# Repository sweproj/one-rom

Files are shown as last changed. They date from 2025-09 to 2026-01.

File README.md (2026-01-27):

# One ROM

**[One ROM](https://onerom.org) - One ROM To Rule Them All**

The most flexible ROM replacement for your retro computer.  It is highly configurable and low-cost.  Get them fabbed at JLC for under $5 each in a quantity of 10 or more.

Based on a Raspberry Pi RP2350 (One ROM Fire 🔥) or STM32F4 (One ROM Ice ❄️).

One ROM is available as 24 pin and 28 pin versions, emulating nearly all systems' 24 and 28 pin ROMs, including any possible chip select configurations with a single hardware variants, and can serve different images to multiple ROM sockets simultaneously.

Replaces failed ROMs in Commodore 64s, VIC-20s, PETs, Ataris, BBC, TIs, disk drives and many other types of systems, like pinball machines and music synthesizers.

ROM types replaced:
- 24 pin: 2704, 2708, 2716, 2732, 2316, 2332, 2364
- 28 pin: 2764, 27128, 27256, 27512, 23128, 23256, 23512

As of the latest firmware, One ROM also supports RAM chips of the correct footprint, including the 6116 and 2016 2K SRAM chips.

One ROM was formerly known as Software Defined Retro ROM (SDRR).

## Quick Start

See https://onerom.org/start/

## Key Features

💰 Based on sub-$2 microcontrollers.  **[Choose from Raspberry Pi (Fire 🔥) or STM (Ice ❄️) flavours](docs/MCU-SELECTION.md)**.

⚡ **[Fast](docs/STM32-SELECTION.md)** enough for PETs, VIC-20s, C64s, 1541s, IEEE drives, etc. Support faster systems with higher end microcontroller.

📐 **[Same footprint](docs/images/sdrr-24-pin-side.png)** as original ROMs - doesn't overhang the socket like other solutions.

🔌 **[USB Version](https://onerom.org/prog/)** - no programmer required, program from your browser.

🚀 **[Quick programming](docs/PROGRAMMING.md)** - build and flash in <10 seconds.

🛠️ **[Reflash in situ](docs/PROGRAMMING.md)** - no need to remove the ROM from the host when reprogramming.

⚙️ **[Software configurable](docs/CONFIGURATION.md)** chip select lines - no hardware jumpers required.

💾 Stores up to **[16 ROM images](docs/STM32-SELECTION.md)** of different sizes and chip select configurations.  Image selectable via jumpers.

📦 **[Replace multiple ROMs with one ROM](docs/MULTI-ROM-SETS.md)** a single One ROM can replace up to 3 original ROMs e.g. all of C64 kernel, BASIC, character set.

🔀 **[Dynamic bank switching](docs/MULTI-ROM-SETS.md)** - switch between ROM images on the fly, e.g. different char ROMs.

💻 **[Hackable at runtime](docs/RUNTIME-ACCESS.md)** - change the ROM images being served and access telemetry from the ROM at runtime using **[Airfrog](https://piers.rocks/u/airfrog)** or other SWD probes.

🧩 **[Images combined automatically](docs/CONFIGURATION.md)** - no need to manually build up your own larger PROM image containing multiple retro ROMs.

🏭 **[Two layer PCB](sdrr-pcb/README.md)**, component on single-side, limited BOM for low manufacturing cost/complexity.

🎯 Supports multiple **[STM32F4xxR](docs/STM32-SELECTION.md)** variants: F401, F411, F405, F446 (others can be added).

🔓 **[Open source](LICENSE.md)** software and hardware.

## Introduction

The video below provides an introduction to One ROM:

Video Title (https://youtu.be/Jhe4LF5LrZ8)

## Hardware

This is the Fire 24-pin version, hardware revison A.  See [sdrr-pcb](sdrr-pcb/README.md) for the hardware designs and documentation.

<div style="display: flex; justify-content: center; gap: 20px;">
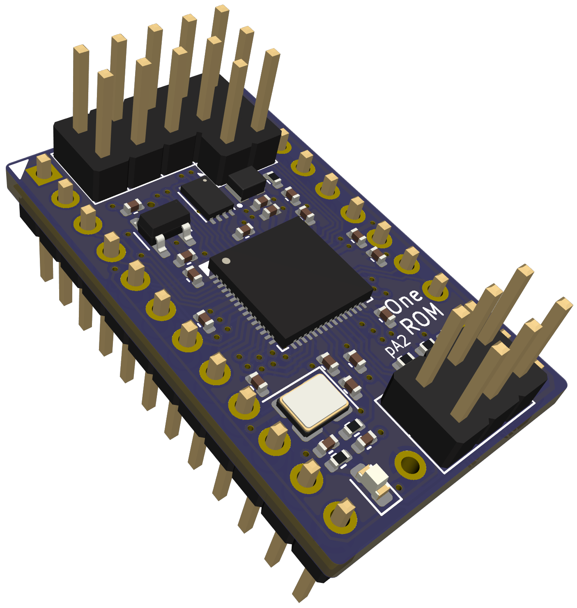
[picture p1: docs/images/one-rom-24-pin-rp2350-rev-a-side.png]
One ROM RP2350 24 pin rev A side on
  
</div>

## Documentation

| Topic | Description |
|---|---|
| [Getting Started](docs/GETTING-STARTED.md) | Detailed instructions for flashing your One ROM |
| [Frequently Asked Questions](docs/FAQ.md) | Answers to common questions about One ROM. |
| [Installation](INSTALL.md) | Installation of dependencies. |
| [Programming](docs/PROGRAMMING.md) | How to program One ROM. |
| [Available Configurations](config/README.md#available-configurations) | Various pre-collated ROM collection configurations. |
| [MCU Selection](docs/MCU-SELECTION.md) | How to select the appropriate MCU for your application. |
| [Image Selection](docs/IMAGE-SELECTION.md) | How to tell One ROM which of the installed ROM images to serve. |
| [Image Sets](docs/MULTI-ROM-SETS.md) | How to use a single One ROM to support multiple ROMs simultaneously or to dynamically switch between images. |
| [Configuration](docs/CONFIGURATION.md) | One ROM configuration options. |
| [Runtime Access/Control](docs/RUNTIME-ACCESS.md) | Access and control the One ROM while it is serving ROMs. |
| [Compatibility](docs/COMPATIBILITY.md) | Compatibility with various retro systems. |
| [Logging](docs/LOGGING.md) | How to enable and use One ROM logging. |
| [Technical Summary](docs/TECHNICAL-SUMMARY.md) | Overview of the One ROM architecture, operation and design decisions. |
| [Technical Details](docs/TECHNICAL-DETAILS.md) | Technical details of the One ROM firmware and hardware. |
| [ROMs Glorious ROMs](docs/ROMS-GLORIOUS-ROMS.md) | Everything you ever wanted to know about 23/27 series ROMs but were afraid to ask. |
| [Custom Hardware](docs/CUSTOM-HARDWARE.md) | Guide on designing custom hardware for One ROM. |
| [Build System](docs/BUILD-SYSTEM.md) | How the One ROM build system works. |
| [Voltage Levels](docs/VOLTAGE-LEVELS.md) | How the One ROM supports the required logic voltage levels. |
| [Pi Pico Programmer](docs/PI-PICO-PROGRAMMER.md) | How to use a $5 Raspberry Pi Pico as a programmer for One ROM. |
| [Manufacturing Test](docs/MANUFACTURING-TEST.md) | Information on testing One ROM during manufacturing. |
| [STM32 Clones](docs/STM32-CLONES.md) | Information using STM32 clones with One ROM. |
| [Future Enhancements](docs/FUTURE-ENHANCEMENTS.md) | Possible future enhancements under consideration. |
| [License](LICENSE.md) | One ROM software and hardware licenses. |

## Debugging

The best place to start with debugging is [`Logging`](docs/LOGGING.md).  This will help you see what the One ROM is doing, and why it may not be working as expected.

If you have an [Airfrog](https://piers.rocks/u/airfrog), you can use it to inspect the One ROM firmware and its current state.

If you'd like a hand, raise an issue on the [GitHub issues page](https://github.com/piersfinlayson/software-defined-retro-rom/issues).  Please provide:

- the MCU you are using and the PCB type/revision
- the retro system you are trying to One ROM with
- any logging from One ROM
- ideally, the firmware image, if you are happy to share.

If you have built the firmware yourself, rather than using a pre-built release image, also provide:

- your build configuration
- the output from `make info-detail`.

## License

See [LICENSE](LICENSE.md) for software and hardware licensing information.

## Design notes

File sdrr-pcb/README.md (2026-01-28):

# sdrr-pcb

Contains SDRR PCB design files.  These are organised into two directories:

- [`verified/`](verified/README.md) - Verified designs that have been tested and work.
- [`unverified/`](unverified/README.md) - Unverified designs that have not been tested.

## Recommended Revisions

Last Updated 28th January 2026.

I recommend Fire over Ice boards for most users.  See [MCU-SELECTION.md](../docs/MCU-SELECTION.md) for a comparison between Fire and Ice capabilities.

### Fire (RP2350)

The current recommended 24 pin hardware revision is [fire-24-d](./verified/fire-24-d/README.md).  This is a combined Pro (SWD) and micro USB version, with 4 image select jumpers (v0.6.1 onwards).  It supports PIO and CPU serving algorithms.  This is recommended over revisions A (Pro only) and B (USB only).

The current recommended 28 pin hardware revision is [fire-28-a3](./verified/fire-28-a3/README.md).  This is a combined Pro (SWD) and USB-C version, with 2 image select pins.  (The 28 pin version does not have X pins.)  It supports PIO and CPU serving algorithms.  The incorrect SWD CLK/DIO silkscreen in A2 has been corrected in this revision.

### Ice (STM32F4)

The current recommended 24 pin hardware revision is [ice-24-j](./verified/ice-24-j/README.md).  This is a combined Pro (SWD) and USB version, with 4 image select pins (v0.6.1 onwards) and 2 X (special function) pins.  It supports both SWD programming and USB programming.

There is no recommended 28 pin Ice version.  (Revision A does exist, but is not recommended and support may have been removed from the latest firware revisions.)

## Notes on Fabrication

All recommended designs have been manufactured and assembled using JLCPCB's PCB assembly service.  The gerbers and BOM files in each revision's `fab/` directory are compatible with JLCPCB's requirements.  However, you need to exercise care when submitting the order to ensure the correct options are selected.  In particular:

- Select economic assembly, not standard assembly, for cost reasons.
- Use standard 1.6mm PCB thickness.  You probably want HASL with lead finish for cost reasons.
- You have to select the desired PCB colour as part of the PCB ordering process.  Red is recommended for Fire and blue for Ice.
- As of late 2025 you no longer need to remove JLC's order ID from the PCBs, but it is worth checking this is still the case when you place your order.
- After uploading the BOM and position files for assembly, you need to ensure all parts are available and checked.
- You must ensure JLC is showing the correct orientation for all components.  There are silkscreen markings for pin 1 on all ICs and polarized components - ensure this matches the pink dot of the component in the viewer.  Also ensure the USB connector is the correct orientation.

Occasionally, some chosen parts are out of stock on JLCPCB.  One ROM has been designed with extremely common parts where possible, which JLC tend to hold large stocks of.  However, if a part is unavailable you may need to select an alternative part.  Ensure the alternative part has the same footprint and electrical characteristics (e.g. capacitance, voltage rating, etc) as the original part.  If in doubt, query within github discussions for advice. 

JLC may raise an issue with you after submitting your order.  Common issues include:
- JLC may ask to add side rails with stamp holes, to help with the PCB assembly process.  While One ROM has been successfully fabbed without these, if JLC recommends them it is best to accept this change, as otherwise they may not warrant the assembled boards.  The side rails can be snapped off using the "mouse bites" (stamp holes) after assembly.  JLC may or may not accept replacing stamp holes with v-score - as v-score is not available on their economic service.

If in doubt, query within github discussions for advice.

Assembly errors:
- Ice boards have rarely, if ever, experienced assembly errors.
- The first few batches of Fire boards experienced some assembly issues, particularly with respect to the RP2350 MCU solder pad fillets.  More recent boards and orders have been without issue.  It is unclear whether differences in the later PCBs or improvements in JLC's assembly process are responsible for this improvement.  If you do experience assembly issues, raise with JLC support.  It would also be interesting to hear on github discussions what issues you experienced, so others can be aware.

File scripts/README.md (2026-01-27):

# Scripts

Helper scripts for testing and debugging.

## onerom.sh

Builds a blank firmware image, adds the chip metadata, adds the ROM/RAM images, and optionally flashes the firmware to a connected OneROM device.

Example, to build a C64 set of ROMs for Fire 24 D:

```bash
scripts/onerom.sh fire-24-d onerom-config/c64.json
```

Example, to build a C64 set of ROMs for Ice 24 J, MCU STM32F411RE, with logging and debug logging, and flash it:

```bash
scripts/onerom.sh -d -l -f ice-24-j f411re onerom-config/c64.json
```

## build-empty-fw.sh

Creates a blank firmware image for the OneROM device, with no metadata and no ROM (or other chip) images or types.

Example:

```bash
scripts/build-empty-fw.sh -d -l sdrr/build/sdrr-rp2350.bin /tmp/
```

## add.sh

Tkes a blank firmware image, adds the chip metadata to it.

Example:

```bash
scripts/add.sh sdrr/build/sdrr-rp2350.bin /tmp/onerom-fw rom-config/c64.json
```

Creates:

- `/tmp/onerom-fw.bin` - the firmware image with the ROM metadata added
- `/tmp/onerom-fw.elf` - the ELF file with symbols for debugging

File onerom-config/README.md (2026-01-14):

# ROM Configs

This directory contains configuration files that can be used to generate various ROM collections for use with One ROM.

There is a [schema file](schema.json) that describes the structure of these configuration files. You can use this schema to validate your own configuration files or to generate new ones.

If you would like a more human readable version of the schema use a tool like [json-schema.app](https://json-schema.app/view/%23?url=https%3A%2F%2Fimages.onerom.org%2Fconfigs%2Fschema.json), pasting in https://images.onerom.org/configs/schema.json as the URL.

To be precise, these config files are used to generate the __metadata__ that is embedded on One ROM's flash __alongside__ the core firmware, adding:

- ROM images
- (optionally) overrides to stock firmware behaviour, on a per ROM basis.

A config file following this format can be used with [One ROM Studio](https://onerom.org/studio) to generate a complete One ROM image and flash it to your One ROM.

## Minimal Config

This is a minimal config:

```json
{
    "$schema": "https://images.onerom.org/configs/schema.json",
    "version": 1,
    "description": "A minimal ROM config",
    "rom_sets": []
}
```

This produces One ROM image with no ROMs in it. This may be useful for manufacturing purposes - in order to flash and ship One ROM with no ROMs installed.

This is essentially the configuration that is used to generate the base One ROM images that One ROM Studio then adds the ROMs you select to.

## Simple Config

A slightly more advanced config with 2 ROM images:

```json
{
    "$schema": "https://images.onerom.org/configs/schema.json",
    "version": 1,
    "name": "Simple Config",
    "description": "A simple ROM config with 2 ROMs",
    "rom_sets": [
        {
            "type": "single",
            "roms": [
                {
                    "description": "ROM 1",
                    "file": "http://example.com/rom1.bin",
                    "type": "2364",
                    "cs1": "active_low"
                }
            ]
        },
        {
            "type": "single",
            "roms": [
                {
                    "description": "ROM 2",
                    "file": "http://example.com/rom2.bin",
                    "type": "2364",
                    "cs1": "active_low"
                }
            ]
        }
    ]
}
```

As can be seen, this config contains 2 ROM sets, each with a single 2364 mask programmed ROM image, each with the CS line active low.

One ROM Studio reads this config, downloads the 2 ROM images from the specified URLs, and builds a One ROM image containing these 2 ROMs.

The two ROM images are selected, at One ROM boot (power on) time, via the on-board image select jumpers.  The first ROM set is selected when all the jumpers are open.  The second ROM set is selected when the first jumper is closed.

(If you close more jumpers than there are ROM sets, the firmware will select the image indicates by the binary value encoded by the jumpers, modulo the number of installed images.)

## 23 vs 27 Series ROMs

If specifying a 27 series (EP)ROM, instead of a 23 (mask programmed) ROM, the `type` field should be set to the appropriate 27 series type (e.g. "27256" instead of "2364").

In this case, there is no need to specify CS line behaviour, as 27 series ROMs use /CE and /OE (both active low) logic by default.

For more details on the differences between 23 and 27 series ROMs, see the [One ROM Visualizer](https://onerom.org/visualizer).

## Firmware Configuration

The `firmware_overrides` section __within a ROM set__ allows fine-tuning of One ROM hardware behavior for __that specific ROM/set of ROMs__. Each base firmware image has built-in defaults - these overrides change the behavior when serving a particular ROM set.

Any ROM set can have its own `firmware_overrides` section, allowing different ROM sets to have different hardware configurations.  It can also have no `firmware_overrides` section, in which case the default firmware behavior is used.

The `firmware_overrides` fields are optional - only include the fields you wish to override from the defaults.

### Primary Use Cases

1. __Performance requirements__ - Some ROM images (particularly character ROMs) require specific clock speeds or voltage settings to serve reliably in certain host systems
2. __Hardware experimentation__ - Testing different configurations to determine optimal settings for specific host platforms and ROM types
3. __Power/performance/preference__ - Disabling features like LEDs (power saving or user preference) or debug interfaces (performance)

### Ice/Fire Specific Configuration

#### Ice Boards (STM32F4-based)

```json
"firmware_overrides": {
    "ice": {
        "cpu_freq": "72MHz",
        "overclock": false
    }
}
```

Ice boards support frequencies from 1MHz to 450MHz.

Set `overclock: true` for frequencies above the rated maximum for a specific STM32F4 MCU.

#### Fire Boards (RP2350-based)

```json
"firmware_overrides": {
    "fire": {
        "cpu_freq": "300MHz",
        "overclock": true,
        "vreg": "1.20V",
        "serve_mode": "Pio"
    }
}
```

Fire boards support 16MHz to 800MHz in various increments (as defined in the schema). For higher frequencies than 150MHz:

- set `overclock: true`.
- you may need to tune `vreg` (internal voltage regulator) - different RP2350 silicon may need different core voltages for stability at high speeds. One ROM firmware will use its own (conservative) voltage regulator settings for higher clock speeds if this is not specified.

### Other Hardware Settings

```json
"firmware_overrides": {
    "led": {
        "enabled": false
    },
    "swd": {
        "swd_enabled": false
    }
}
```

- __LED__ - Disable to save power or if you don't want a status LED on your ROM.  Note, if present and the device enters "limp mode" (e.g. due to a fault or unrecoverable configuration error), the LED will still blink to indicate an error.
- __SWD__ - Disable the debug interface to reduce bus contention and improve serving performance.  Not yet supported, may be removed in a future release.

### Example: ROM-Specific Configuration

```json
{
    "rom_sets": [
        {
            "description": "C64 Character ROM - requires high clock speed",
            "firmware_overrides": {
                "ice": {
                    "cpu_freq": "150MHz",
                    "overclock": true
                }
            },
            "roms": [
                {
                    "description": "C64 Character ROM",
                    "file": "http://example.com/c64-char.bin",
                    "type": "2332",
                    "cs1": "active_low",
                    "cs2": "active_high"
                }
            ]
        }
    ]
}
```

### Advanced: PIO Serving Algorithm Parameters

For Fire boards using the PIO serving algorithm, low-level timing can be tuned via `serve_alg_params`. This is primarily for experimentation to determine what settings are required for specific ROM/host combinations.

```json
"firmware_overrides": {
    "serve_alg_params": {
        "params": [254, 0, 2, 0, 0, 0, 254, 255]
    }
}
```

As of firmware 0.6.0, the parameter array format is 8 bytes long, as follows:

- Byte 0: `0xFE` (signature)
- Byte 1: `addr_read_irq` (0=disabled, 1=enabled) - whether to use IRQ to trigger address reads
- Byte 2: `addr_read_delay` (0-31) - PIO cycles to delay between address reads
- Byte 3: `cs_active_delay` (0-31) - PIO cycles to wait after CS active before setting data pins to outputs
- Byte 4: `cs_inactive_delay` (0-31) - PIO cycles to hold data as outputs after CS goes inactive
- Byte 5: `no_dma` (0=use DMA, 1=CPU) - whether to use DMA or CPU for byte serving
- Byte 6: `0xFE` (end signature)
- Byte 7: `0xFF` (padding)

These parameters adjust the PIO state machine timing for specific ROM types or host systems. At 150MHz, each PIO cycle is ~6.67ns. See the PIO implementation source code for detailed timing analysis and pre-defined configurations.

It is likely that in future firmware versions, more PIO settings will be exposed via the config file.

### Firmware Defaults

As of 0.6.0 the following firmware defaults are used if no overrides are specified:

- Ice Clock: F401=84MHz, F411=100MHz, F405=168MHz, F446=180MHz, no overclocking.
- Fire Clock: 150MHz, overclocking enabled, VREG 1.10V.
- LED: Enabled (if hardware support is present)
- SWD: Enabled (if hardware support is present)
- PIO Serve Algorithm Params: [254, 0, 2, 0, 0, 0, 254, 255]

### Error Handling

Where possible, One ROM attempts to gracefully recover from incorrect or invalid configuration settings. 

For example, if it cannot calculate PLL values for a specific requested clock speed, it will attempt to find a close match, and if not found fall back to the values built into the firmware (likely to be the stock maximum rated speed for the MCU).

However, there are some situations where recover is not possible, or it is deemed better to enter "limp mode" (where the device hangs and flashes its status LED, irrespective of the LED enabled setting) to indicate a fault.

If the device enters limp mode, you have two choices:
- Try changing the settings and reflashing.
- Connecting a debug probe and using a build with BOOT_LOGGING/DEBUG_LOGGING included, to diagnose the issue.

The stock builds provided as part of One ROM releases _do not_ include debug or boot logging for performance reasons.

## Complex Configs

There's some advanced ROM options including the following:

- ROM Set types "multi" and "banked" for multi-ROM sets and dynamically bank switched ROM sets
- Local file and URL file sources (most generators only support URLs)
- The ability to specify licenses which must be accepted before building a config
- The ability to configure chip selects in multiple directions
- Support for all 24 and 28 pin ROM types
- Optional categories for better organization
- Support for archived ROM files (zips)
- Retrieve sections of a larger ROM file
- Duplicate and pad ROM images, if the ROM file provided is smaller than the expected size, and truncate if larger

Use the configs in this directory and the schema to build your own complex configs.

## Future Plans

The "end-game" is to have a repository of officially supported ROM configs for popular systems that can be used with One ROM Studio to build custom One ROM images.

It is intended that eventually ROM configs will specify the original ROM chip's access times and other characteristics, with the One ROM firmware to dynamically adjust its serving behavior to match the original hardware as closely as possible.

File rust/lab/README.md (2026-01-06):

# One ROM Lab

One ROM Lab firmware reads ROM images from external ROM chips (originals, One ROMs, and other replacements), by using the One ROM hardware with female socket placed on top of the ROM socket pins.  It can also be used to instrument the performance of these external ROM chips, by using additional equipment, such as logic analyzers or oscilloscopes.

<div class="video-container">
    <iframe 
        width="560" 
        height="315" 
        src="https://www.youtube.com/embed/9QBlPToP_BQ" 
        frameborder="0" 
        allow="accelerometer; autoplay; encrypted-media; gyroscope; picture-in-picture" 
        allowfullscreen>
    </iframe>
</div>

You need female headers on the top of your One ROM PCB in order to use the Lab firmware. 

One ROM Lab currently only support STM32F4 based One ROMs - a RP2350 is viable, with the appropriate changes to support `embassy-rp`.

## Validating One ROMs

The current primary use case for lab is to validate One ROMs before shipping them to customers.  This is done by reading the ROM image, calculating its SHA1 hash, and comparing it to the expected hash from the database.

To build One ROM Lab firmware for validating 24 pin One ROMs (with lab running on hw revision ice-24-usb-h) use:

```bash
cargo build --no-default-features --features validate-24-ice --target thumbv7em-none-eabihf --bin onerom-lab
```

To build One ROM Lab firmware for validating 28 pin One ROMs (with lab running on hw revision fire-28-a) use:

```bash
cargo build --no-default-features --features validate-28-fire --target thumbv8m.main-none-eabihf --bin onerom-lab-fire
```

Note that the 28 pin Fire version does not currently support USB.

## Modes

There are a number of modes of operation:
- **Control** - **default** - is controlled via an external device using SWD.  When paired with `Airfrog` this allows the user to manually trigger ROM Reads using Airfrog's web UI.
- **One-shot** - reads a ROM image once at startup and then stops.  This is useful for automated testing, or for use in environments where SWD is not available.  In this mode, ROM information is output via RTT.
- **Continuous** - continuously reads a ROM image in a loop, with a brief pause between reads.
- **QA** - similar to continuous, used to .

These modes are mutually exclusive, and are selected at [build](#building) time using Cargo features.

## Building

There are different features to support:
- Different STM32F4 variants
- Different [modes](#modes)

Supported STM32F4 variants:
- `f401re`
- `f405rg` - **default**
- `f411re`
- `f446re`

Modes:
- `control` - **default** - controlled via SWD (e.g. Airfrog UI)
- `oneshot` - reads a ROM image once at startup and then stops
- `repeat` - continuously reads an attached ROM image in a loop
- `qa` - similar to repeat, designed for QA testing One ROMs

Example build commands:

```bash
cargo build --release --no-default-features --features f411re,qa,usb
cargo build --release --no-default-features --features f405rg,control
cargo build --release --no-default-features --features f411re,oneshot
cargo build --release --no-default-features --features f446re,repeat
```

## Flashing

If using `probe-rs` use `cargo run` instead of `cargo build` to automatically flash the firmware after building:

```bash
cargo build --release --no-default-features --features f405rg,control
cargo build --release --no-default-features --features f411re,oneshot
cargo build --release --no-default-features --features f446re,repeat
```

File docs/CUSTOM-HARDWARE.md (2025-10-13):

# Custom Hardware

This document explains the key steps for designings custom One ROM hardware and integrating it with the One ROM build system.

## Hardware Design Requirements - STM32F4xxR

There are a number of mandatory requirements when designing your own One ROM hardware.  These are explained in [Requirements Justification](#requirements-justification).

If you are using an STM32F4xxR based system:

- You **must** assign all of the address lines and chip select lines to Port C.
- You **must** "right justify" the address and chip select lines, so they start at PC0, and use contiguous lines.
- If you provide X1/X2 they **must** follow the address and CS lines, so be PC14/PC15.
- You **must** assign the data lines to pins PA0-7 inclusive.

With the above requirements, the address and chip select lines, and data lines, can be assigned to the specified range of pins in any order.  Address and CS lines can be mixed together.

In addition, it is recommended to:

- Avoid assigning additional purposes to PA13/PA14, but dedicating them to an SWD programming/debug interface.
- Avoid assigning additional purposes to PA8, but break it out to a test point, for optional MCO access.
- Avoid connecting any external pull-ups/downs to PB2, as it is also BOOT1.  (PB2 can be used, for example as one of the image select jumpers.)
- Avoid any external pull-ups/downs on the image select lines, as the firmware enables internal pull-downs on these lines.
- Expose BOOT0.  While the firmware will keep SWD active at all times, if so configured, it may still be useful to be able to force the device into the bootloader mode by pulling BOOT0 high.
- Tie NRST high, to avoid unexpected glitches.
- Avoid the RT9013 or other switching regulators to provide 3.3V power to the STM32F4.  This voltage regular causes problems with some systems.  AP2112K-3.3 is a good, small form factor alternative, which is also used on the official One ROM hardware.

## Non-STM32F4xxR Hardware

If you are using a different model of microcontroller, read [Requirements Justification](#requirements-justification), and select the microcontroller and design the hardware following the same philosophy.

## Firmware Integration

These instructions apply to STM32F4xxR based hardware only.  If you have selected a different microcontroller, you will likely need to adapt the [firmware source code](/sdrr/).

Add a config file to either [`rust/config/json/third-party`](/rust/config/json/third-party/README.md) or [`rust/config/json/user`](/rust/config/json/user/README.md) using the name of your hardware configuration, e.g. `piers.rocks-24pin-rev-a.json`.

This file contains the ports and pins used for each function.  Use the existing files in [`rust/config/json/`](/rust/config/json/) as a template.

No firmware changes are required, so long as you follow the requirements above.  The firmware will automatically detect the hardware configuration based on the config file, and apply the correct pin mappings.

## Building

From the root of the One ROM repository, run:

```bash
MCU=f411re HW_REV=piers.rocks-24pin-rev-a BOOT_LOGGING=1 make       # Replace f411re with your STM model
MCU=f411re HW_REV=piers.rocks-24pin-rev-a BOOT_LOGGING=1 make test
```

Examine the build logs to ensure your configuration has been detected correctly.

It is **strongly recommended** to run the tests with `make test` after building your firmware, to ensure that the firmware has correctly detected and applied your hardware configuration, and mapped the ROM image(s) correctly.  

## Testing

Flash the firmware to your hardware, using an SWD programmer with RTT support:

```bash
MCU=f411re HW_REV=piers.rocks-24pin-rev-a BOOT_LOGGING=1 make run
```

Check the logs indicate a successful boot and the device is serving the image.

Now test the device in an appropriate host.

## Requirements Justification

The 64 pin STM32F4xx microcontroller is used, because it has sufficient 5V tolerant GPIOs for this application, in suitable locations.  In particular, Port C is required, as Port A contains the 2 SWD pins, which we want to keep free for SWD debugging.  All GPIOs on this range of microcontrollers are 5V tolerant, and have sufficient tolerances for this purpose.  However you should double check the datasheet for your specific microcontroller model.

Port C is used for the address and CS lines, as:

- All 16 GPIOs are exposed on the 64-pin package.  One ROM needs a minimum of 14 for the address and CS lines for the 2364 ROM.
- We want the address and CS lines states to be on the same port as each other so they are retrievable with a single assembly instruction.
- We want them to start from PC0, and to be contiguous, to avoid any bit shifting or other manipulation before using the read input register value as an offset into the ROM image being served.

Port A is used for the data lines, as:

- We need 8 GPIOs.
- We want them to be pins 0-7, to avoid any bit shifting or other manipulation before applying the read data byte to the port output register.
- Port B has BOOT1 on PB2, which we want to avoid on the address or data buses (or CS line), as its state may change during boot - either conflicting with the bus, or causing the device to boot into an incorrect mode.
- Port C is taken.

Note that on most of the STM32F4xxR devices PB11 is not broken out.  (It is present on the F405 and F415.)

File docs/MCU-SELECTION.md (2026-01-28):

# MCU Selection

Your most important choice is between a Raspbery Pi RP2350-based One ROM Fire 🔥, or an STM32F4-based One ROM Ice ❄️.

| Feature | Fire 🔥 RP2350 | Ice ❄️ STM32F4 |
|---|---|---|
| **Firmware** | Fully supported | Fully supported |
| **Price Each (5 units)** | $8 | $6.50 |
| **Price Each (20 units)** | $4.00 | $3.25 |
| **Performance** | Higher | Lower |
| **Image Select Jumpers** | 4 | 4 |
| **Bank/Set Pins** | 2 | 2 |
| **Flash Size** | 2MB | 128KB-1MB |
| **Physical Size** | 2316/2332/2364 footprint | Same |
| **Future Enhancements** | Expected | Supported for foreseeable future |
| **SRAM Emulation** | Supported | Not supported |

Notes:
- **Price**: Approximate Assembled price, each, from JLCPCB, August 2025, not including tax and shipping.
- **Image Select Jumpers**: More jumpers allow more images to be selected between at boot time
- **Bank/Set Pins**: Allow dynamic switching between images at runtime, or serving multiple ROM sockets at once
- **Storage Impact**: Flash size impacts ROM image storage capacity and multi-ROM set usage
- **Support**: Both boards are expected to be supported long-term
- **Price Trend**: RP2350 is more expensive in small quantities but prices converge at larger volumes
- **Performance**: RP2350 offers higher performance, due its parallel IO state machines (PIOs)
- **SRAM Emulation**: As of writing, only supported on Fire 24

## Which One Should **You** Choose?

I now recommend Fire (RP2350-based) boards over Ice, as they contain all the features of Ice boards, can be produed at a similar cost, and have more headroom for future enhancements, particularly as have PIO state machines.

I will keep supporting both boards for the foreseeable future - I have a large personal stock of Ice boards I want to continue to use.

## RP2350

The One ROM Pico uses the RP2350 MCU, A4 stepping or later.  This is now (August 2025) used by default by JLC's PCB assembly service.  They also (January 2026) offer RP2354 (both A and B) in the A4 stepping.

See [RP2350](docs/RP2350.md) for more details about the RP2350 support, including some earlier performance results.

## STM32

The One ROM STM uses the STM32F4 family of MCUs.  This section aims to help you choose the right one for your needs.

All performance figures in this document are based on testing genuine STM32 parts.  For a discussion of clones, see [STM32-Clones](/docs/STM32-CLONES.md).

### Supported Microcontrollers

The following table provides details about the supported STM32 and clone microcontrollers for One ROM Ice:

| Model | Flash | RAM | Max Clock Speed | Max single ROM Images | Max multi-ROM sets | Build variant |
|---|---|-----|---|---|---|---|
| STM32F401RBT6 | 128KB | 64KB | 84MHz | 4 | - | f401rb |
| STM32F401RCT6 | 256KB | 64KB | 84MHz | 12 | - | f401rc |
| STM32F401RET6 | 512KB | 96KB | 84MHz | 16 | 7 | f401re |
| STM32F411RCT6 | 256KB | 128KB | 100MHz | 12 | 3 | f411rc |
| STM32F411RET6 | 512KB | 128KB | 100MHz | 28 | 7 | f411re |
| GD32F405RGT6* | 1024KB | 128KB | 168MHz | 32 | 15 | f405rg |
| STM32F405RGT6 | 1024KB | 128KB | 168MHz | 32 | 15 | f405rg |
| STM32F446RCT6 | 256KB | 128KB | 180MHz | 12 | 3 | f446rc |
| STM32F446RETx | 512KB | 128KB | 180MHz | 28 | 7 | f446re |

(*) The GD32F405RGT6 is currently preferred above the STM32F405RGT6 as it seems more highly performant, although it has slower boot times.  See [this issue](https://github.com/piersfinlayson/software-defined-retro-rom/issues/8) for more details.

Neither STM32F401RBT6 and STM32F401RCT6 have sufficient RAM to serve multi-ROM or banked sets of images, but they can serve single ROM images.

The vast majority of ROMs can be emulated by the cheapest variant, the F401.  The best bang for buck are likely to be either:

- STM32F401RET6 - [currently $1.93 on LCSC](https://lcsc.com/product-detail/Microcontrollers-MCU-MPU-SOC_ST-STM32F401RET6_C116978.html)
- STM32F411RET6 - [currently $2.69 on LCSC](https://lcsc.com/product-detail/Microcontrollers-MCU-MPU-SOC_ST-STM32F411RET6_C94355.html)

The F401 may require a small overclock for some systems, such as running the C64 multi-ROM set (~90MHz vs 84MHz rated maximum).

There are also cheap [clones available](/docs/STM32-CLONES.md), with a clone F405 coming in at around the same price as a genuine F411 (from LCSC).  The GD32F405RGT6 has been tested, and is a recommended MCU.

For One ROM Fire boards, the RP2350A is the supported microcontroller, using ```MCU=rp2350```.  Flash is a separate chip, and is 2MB on the official boards.

Therefore the maximum number single ROM images and multi-ROM sets are both 16 for One ROM Fire.  On hardware rev A, there are only 3 image select jumpers, so only 2^3 = 8 images can be selected via these jumpers.

### Clock Speed Requirements

Ideally, you should not specify the `FREQ` build variable, which will cause the STM32 variant you choose to run at its maximum clock speed.

However, if you need to specify a lower clock speed, for example, to reduce power draw/heat you can do so by setting the `FREQ` build variable to a value that is less than or equal to the maximum clock speed of the selected STM32 variant.  See [`FREQ`](/docs/CONFIGURATION.md#freq) for more details.  It is also possible to [overclock](/docs/CONFIGURATION.md#overclock) the processor you have, at your own risk.

Different retro systems, and different use cases, have different minimum clock speed requirements.  Some example minimum clock speeds are given in the following table.  They contain both serving algorithms `A` and `B`, which can be [specified](/docs/CONFIGURATION.md#serve_alg), and `B` is the default.

They were generated by testing against real retro systems and are absolute minima.  Your mileage may vary and it would be advisable to add some headroom to these figures - and you may need to experiment with different clock speeds to find the best one for your system.

Alternatively, either a GD32F405, STM32F405 or STM32F446 and running at maximum clock speed, both of which support all of the systems below, or [overclock](/docs/CONFIGURATION.md#overclock) the processor you have.  Even the C64 multi-ROM set requires only a modest (~5%) overclock on the F401.

| System | Video | ROM Type | Default Alg `B` | Optional Alg `A` | STM32F4 Variants | Release Measured | Notes |
|---|---|---|---|---|---|---|---|
| PET 4032 | 40 Col 50Hz | Kernal | 26MHz | 29MHz | All | v0.2.1 | $E000 tested |
| PET 4032 | 40 Col 50Hz | Character | 18MHz | 26MHz | All | v0.2.1 | |
| VIC 20 | PAL | Kernal | 32Mhz | 34MHz | All | v0.2.1 | |
| VIC 20 | PAL | BASIC | 32MHz | 34MHz | All | v0.2.1 | |
| VIC 20 | PAL | Character | 45MHz | 76MHz | All | v0.2.1 | |
| C64 | PAL | Kernal | 79MHz | 79MHz | All | v0.2.1 | |
| C64 | PAL | Character | 79MHz | 92MHz | All | v0.2.1 | |
| 1541 | n/a | Kernal | 18MHz | 30MHz | All | v0.2.1 | $C000 tested |
| VIC 20 | PAL | Multi-ROM Set | 32MHz | n/a | All | v0.2.1 | Kernal+BASIC |
| C64 | PAL | Multi-ROM Set | 89MHz | n/a | *F411/F405/F446 | v0.2.1 | Kernal+BASIC+Char |
| 1541 | n/a | Multi-ROM Set | 18MHz | n/a | All | v0.2.1 | $C000+$E000 |

(*) Or a slightly overclocked F401.

When running multiple One ROMs in a single system, you may find you have to run each One ROM faster than these speeds, to avoid each conflicting with the other.  In this case, consider using multi-ROM support.

When all CS lines on a ROM are active low, the serving algorithm is slightly quicker, and hence slower clock speeds are acceptable.

### ROM Image Capacity

Each ROM image consumes 16KB of flash (irrespective of the ROM type - see [Technical Details](/docs/TECHNICAL-DETAILS.md) for why), so the maximum number of ROM images that can be stored is limited by the flash size for smaller variants.  The One ROM firmware itself consumes between 16-32KB of flash.  The rest of the flash can be used for images, up to a maximum of 16, which is limited by the number of select jumpers on the PCB, which in turn is limited by the phyical size of the original ROM footprint.

If you are using multi-ROM sets (of up to 3 images), each set consumes 64KB of flash, again irrespective of the image types.

### Supporting Other Variants

If you have a different variant, the easiest way to support it is to choose a version above which is of the same or higher power than your chosen variant, and select that version.

If you want to add support for another variant:

- Add it to [`Makefile`](/Makefile) - see the `STM` variable.
- Add it to [`/rust/sddr-common`](/rust/sdrr-common), in particular:
  - [`/rust/sdrr-common/src/sdrr_types.rs`](/rust/sdrr-common/src/sdrr_types.rs):
    - `StmProcessor`
    - `StmVariant`
  - [`/rust/sdrr-common/src/args.rs`](/rust/sdrr-common/src/args.rs):
    - `parse_stm_variant()` function
  - [`/rust/sdrr-gen/src/rom_types.rs`](/rust/sdrr-gen/src/rom_types.rs):
    - `StmProcessor`
    - `StmVariant`
- Add it to the [`sdrr`] firmware:
  - [`/sdrr/src/config_base.h`](/sdrr/src/config_base.h)
    - `stm_line_t`
  - Add its max frequency to [`/sdrr/include/include.h`](/sdrr/include/include.h) - search for the pre-processor `TARGET_FREQ_MHZ` tests.
  - Add it to [`/sdrr/src/utils.c`](/sdrr/src/utils.c) - `log_init` function.
  - Add any support specifically for this STM32 variant - grep for "STM32F411" and "STM32F405" for examples of variant specific code.

### STM32F4 Family Comparisons

For completeness, all of the STM32F4xxR variants are compared in the following table.  All of these variants proivde the Cortex-M4F core.

| Feature | F401 | F405 | F410 | F411 | F412 | F413 | F415 | F423 | F446 |
|---|---|---|---|---|---|---|---|---|---|
| **Max Freq** | 84 MHz | 168 MHz | 100 MHz | 100 MHz | 100 MHz | 100 MHz | 168 MHz | 100 MHz | 180 MHz |
| **Flash** | 128-512 KB | 512 KB-1 MB | 64-128 KB | 256-512 KB | 512 KB-1 MB | 1-1.5 MB | 512 KB-1 MB | 1-1.5 MB | 256-512 KB |
| **SRAM** | 96 KB | 192 KB | 32 KB | 128 KB | 256 KB | 320 KB | 192 KB | 320 KB | 128 KB |

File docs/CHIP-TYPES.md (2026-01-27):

# Chip Type Specifications

This document provides detailed specifications for the different Chip types One ROM supports, and aims to support in future, including pinouts, control lines, and programming requirements.

The document is auto-generated from the [json/rom-types.json](/rust/config/json/rom-types.json) configuration file.  That file was created by researching datasheets for the various Chip types.

Some of the pin names have been modified from the datasheet values for consistency beween Chip types:

- /OE on 2704/2408 is called Program, but serves as /OE when in read mode.  Other 27xx ROMs use /OE for that pin, hence the /OE name is used here. 
- Similarly /CE on 2704/2708 ROMs is called /CS, but is called /CE for consistency with other ROM types.
- 23256/23512 chip select lines are often called CE/OE on datasheets, but are mask programmable to be active high or low, hence these are referred to within this doc as CS lines, like the other 23xx ROMs.

There are also some other inconsistencies between types:

- 2332's CS2 is pin 21 and pin 18 is A11.  On the 2316, CS2 is pin 18, and CS3 pin 21.
- The 2332's A11 is pin18, but the 2732's A11 is pin 21.

## Contents

- [24-pin Mask ROM Family (23xx)](#24-pin-mask-rom-family-23xx)
- [28-pin Mask ROM Family (23xxx)](#28-pin-mask-rom-family-23xx)
- [24-pin EPROM Family (27xx)](#24-pin-eprom-family-27xx)
- [28-pin EPROM Family (2764 and 27xxx)](#28-pin-eprom-family-27xx)
- [RAM Chips](#ram-chips)
- [Pin Function Comparison](#pin-function-comparison)
- [Detailed Pinouts](#detailed-pinouts)

## 24-pin Mask ROM Family (23xx)

| Chip Type | Size | Address Lines | Control Lines | Programming |
|---|---|---|---|---|
| 2316 | 2KB | 11 (A0-A10) | CS1 (pin 20), CS2 (pin 18), CS3 (pin 21) | None |
| 2332 | 4KB | 12 (A0-A11) | CS1 (pin 20), CS2 (pin 21) | None |
| 2364 | 8KB | 13 (A0-A12) | CS1 (pin 20) | None |

## 28-pin Mask ROM Family (23xx)

| Chip Type | Size | Address Lines | Control Lines | Programming |
|---|---|---|---|---|
| 23128 | 16KB | 14 (A0-A13) | CS1 (pin 20), CS2 (pin 22), CS3 (pin 27) | None |
| 23256 | 32KB | 15 (A0-A14) | CS1 (pin 20), CS2 (pin 22) | None |
| 23512 | 64KB | 16 (A0-A15) | CS1 (pin 20), CS2 (pin 22) | None |
| 231024 | 128KB | 17 (A0-A16) | CS1 (pin 20) | None |

## 24-pin EPROM Family (27xx)

| Chip Type | Size | Address Lines | Control Lines | Programming |
|---|---|---|---|---|
| 2704 | 512B | 9 (A0-A8) | /CE (pin 18), /OE (pin 20) | VPP: pin 18 (Low during read) |
| 2708 | 1KB | 10 (A0-A9) | /CE (pin 18), /OE (pin 20) | VPP: pin 18 (Low during read) |
| 2716 | 2KB | 11 (A0-A10) | /CE (pin 18), /OE (pin 20) | VPP: pin 21 (VCC during read) |
| 2732 | 4KB | 12 (A0-A11) | /CE (pin 18), /OE (pin 20) | VPP: pin 20 (Acts as /OE) |

## 28-pin EPROM Family (27xx)

| Chip Type | Size | Address Lines | Control Lines | Programming |
|---|---|---|---|---|
| 2764 | 8KB | 13 (A0-A12) | /CE (pin 20), /OE (pin 22) | VPP: pin 1 (VCC during read); /PGM: pin 27 (High during read) |
| 27128 | 16KB | 14 (A0-A13) | /CE (pin 20), /OE (pin 22) | VPP: pin 1 (VCC during read); /PGM: pin 27 (High during read) |
| 27256 | 32KB | 15 (A0-A14) | /CE (pin 20), /OE (pin 22) | VPP: pin 1 (VCC during read) |
| 27512 | 64KB | 16 (A0-A15) | /CE (pin 20), /OE (pin 22) | VPP: pin 22 (VCC during read) |
| 27C010 | 128KB | 17 (A0-A16) | /CE (pin 22), /OE (pin 24) | VPP: pin 1 (x); /PGM: pin 31 (x) |
| 27C020 | 256KB | 18 (A0-A17) | /CE (pin 22), /OE (pin 24) | VPP: pin 1 (x); /PGM: pin 31 (x) |
| 27C040 | 512KB | 19 (A0-A18) | /CE (pin 22), /OE (pin 24) | VPP: pin 1 (x); /PGM: pin 22 (Acts as /OE) |
| 27C400 | 512KB | 19 (A0-A18) | /BYTE (pin 31), /CE (pin 10), /OE (pin 12) | VPP: pin 31 (word_size); /PGM: pin 10 (Acts as /OE) |
| 27C080 | 1024KB | 20 (A0-A19) | /CE (pin 22), /OE (pin 24) | VPP: pin 24 (Acts as /OE); /PGM: pin 22 (Acts as /OE) |

## RAM Chips

| Chip Type | Size | Address Lines | Control Lines | Programming |
|---|---|---|---|---|
| 6116 | 2KB | 11 (A0-A10) | /CE (pin 18), /OE (pin 20), /WRITE (pin 21) | None |

## Pin Function Comparison

### 24-pin Package

| Pin | 2316 | 2332 | 2364 | 2704 | 2708 | 2716 | 6116 | 2732 |
|-----|---|---|---|---|---|---|---|---|
| 1 | A7 | A7 | A7 | A7 | A7 | A7 | A7 | A7 |
| 2 | A6 | A6 | A6 | A6 | A6 | A6 | A6 | A6 |
| 3 | A5 | A5 | A5 | A5 | A5 | A5 | A5 | A5 |
| 4 | A4 | A4 | A4 | A4 | A4 | A4 | A4 | A4 |
| 5 | A3 | A3 | A3 | A3 | A3 | A3 | A3 | A3 |
| 6 | A2 | A2 | A2 | A2 | A2 | A2 | A2 | A2 |
| 7 | A1 | A1 | A1 | A1 | A1 | A1 | A1 | A1 |
| 8 | A0 | A0 | A0 | A0 | A0 | A0 | A0 | A0 |
| 9 | D0 | D0 | D0 | D0 | D0 | D0 | D0 | D0 |
| 10 | D1 | D1 | D1 | D1 | D1 | D1 | D1 | D1 |
| 11 | D2 | D2 | D2 | D2 | D2 | D2 | D2 | D2 |
| 12 | GND | GND | GND | GND | GND | GND | GND | GND |
| 13 | D3 | D3 | D3 | D3 | D3 | D3 | D3 | D3 |
| 14 | D4 | D4 | D4 | D4 | D4 | D4 | D4 | D4 |
| 15 | D5 | D5 | D5 | D5 | D5 | D5 | D5 | D5 |
| 16 | D6 | D6 | D6 | D6 | D6 | D6 | D6 | D6 |
| 17 | D7 | D7 | D7 | D7 | D7 | D7 | D7 | D7 |
| 18 | CS2 | A11 | A11 | /CE+VPP | /CE+VPP | /CE | /CE | /CE+PE |
| 19 | A10 | A10 | A10 | VDD | VDD | A10 | A10 | A10 |
| 20 | CS1 | CS1 | CS1 | /OE+PE | /OE+PE | /OE+PE | /OE | /OE+VPP |
| 21 | CS3 | CS2 | A12 | VBB | VBB | VPP | /WRITE | A11 |
| 22 | A9 | A9 | A9 | GND | A9 | A9 | A9 | A9 |
| 23 | A8 | A8 | A8 | A8 | A8 | A8 | A8 | A8 |
| 24 | VCC | VCC | VCC | VCC | VCC | VCC | VCC | VCC |

### 28-pin Package

| Pin | 23128 | 23256 | 23512 | 231024 | 2764 | 27128 | 27256 | 27512 |
|-----|---|---|---|---|---|---|---|---|
| 1 | NC | NC | A15 | A15 | VPP | VPP | VPP | A15 |
| 2 | A12 | A12 | A12 | A12 | A12 | A12 | A12 | A12 |
| 3 | A7 | A7 | A7 | A7 | A7 | A7 | A7 | A7 |
| 4 | A6 | A6 | A6 | A6 | A6 | A6 | A6 | A6 |
| 5 | A5 | A5 | A5 | A5 | A5 | A5 | A5 | A5 |
| 6 | A4 | A4 | A4 | A4 | A4 | A4 | A4 | A4 |
| 7 | A3 | A3 | A3 | A3 | A3 | A3 | A3 | A3 |
| 8 | A2 | A2 | A2 | A2 | A2 | A2 | A2 | A2 |
| 9 | A1 | A1 | A1 | A1 | A1 | A1 | A1 | A1 |
| 10 | A0 | A0 | A0 | A0 | A0 | A0 | A0 | A0 |
| 11 | D0 | D0 | D0 | D0 | D0 | D0 | D0 | D0 |
| 12 | D1 | D1 | D1 | D1 | D1 | D1 | D1 | D1 |
| 13 | D2 | D2 | D2 | D2 | D2 | D2 | D2 | D2 |
| 14 | GND | GND | GND | GND | GND | GND | GND | GND |
| 15 | D3 | D3 | D3 | D3 | D3 | D3 | D3 | D3 |
| 16 | D4 | D4 | D4 | D4 | D4 | D4 | D4 | D4 |
| 17 | D5 | D5 | D5 | D5 | D5 | D5 | D5 | D5 |
| 18 | D6 | D6 | D6 | D6 | D6 | D6 | D6 | D6 |
| 19 | D7 | D7 | D7 | D7 | D7 | D7 | D7 | D7 |
| 20 | CS1 | CS1 | CS1 | CS1 | /CE | /CE | /CE | /CE+PE |
| 21 | A10 | A10 | A10 | A10 | A10 | A10 | A10 | A10 |
| 22 | CS2 | CS2 | CS2 | A16 | /OE | /OE | /OE+PE | /OE+VPP |
| 23 | A11 | A11 | A11 | A11 | A11 | A11 | A11 | A11 |
| 24 | A9 | A9 | A9 | A9 | A9 | A9 | A9 | A9 |
| 25 | A8 | A8 | A8 | A8 | A8 | A8 | A8 | A8 |
| 26 | A13 | A13 | A13 | A13 | NC | A13 | A13 | A13 |
| 27 | CS3 | A14 | A14 | A14 | /PGM | /PGM | A14 | A14 |
| 28 | VCC | VCC | VCC | VCC | VCC | VCC | VCC | VCC |

## Detailed Pinouts

### 2316 - 2KB mask ROM with 3 configurable CS lines

**Package:** 24-pin DIP  
**Capacity:** 2048 bytes  
**Control:** 3 configurable CS lines  

| Function | Pins | Notes |
|---|---|---|
| Address (A0-A10) | 8,7,6,5,4,3,2,1,23,22,19 | 11 address lines |
| Data (D0-D7) | 9,10,11,13,14,15,16,17 | 8 data lines |
| CS1 | 20 | Configurable polarity |
| CS2 | 18 | Configurable polarity |
| CS3 | 21 | Configurable polarity |
| VCC | 24 | +5V |
| GND | 12 | 0V |

### 2332 - 4KB mask ROM with 2 configurable CS lines

**Package:** 24-pin DIP  
**Capacity:** 4096 bytes  
**Control:** 2 configurable CS lines  

| Function | Pins | Notes |
|---|---|---|
| Address (A0-A11) | 8,7,6,5,4,3,2,1,23,22,19,18 | 12 address lines |
| Data (D0-D7) | 9,10,11,13,14,15,16,17 | 8 data lines |
| CS1 | 20 | Configurable polarity |
| CS2 | 21 | Configurable polarity |
| VCC | 24 | +5V |
| GND | 12 | 0V |

### 2364 - 8KB mask ROM with 1 configurable CS line

**Package:** 24-pin DIP  
**Capacity:** 8192 bytes  
**Control:** 1 configurable CS line  

| Function | Pins | Notes |
|---|---|---|
| Address (A0-A12) | 8,7,6,5,4,3,2,1,23,22,19,18,21 | 13 address lines |
| Data (D0-D7) | 9,10,11,13,14,15,16,17 | 8 data lines |
| CS1 | 20 | Configurable polarity |
| VCC | 24 | +5V |
| GND | 12 | 0V |

### 23128 - 16KB mask ROM with 3 configurable CS lines

**Package:** 28-pin DIP  
**Capacity:** 16384 bytes  
**Control:** 3 configurable CS lines  

| Function | Pins | Notes |
|---|---|---|
| Address (A0-A13) | 10,9,8,7,6,5,4,3,25,24,21,23,2,26 | 14 address lines |
| Data (D0-D7) | 11,12,13,15,16,17,18,19 | 8 data lines |
| CS1 | 20 | Configurable polarity |
| CS2 | 22 | Configurable polarity |
| CS3 | 27 | Configurable polarity |
| VCC | 28 | +5V |
| GND | 14 | 0V |

### 23256 - 32KB mask ROM with 2 configurable CS lines

**Package:** 28-pin DIP  
**Capacity:** 32768 bytes  
**Control:** 2 configurable CS lines  

| Function | Pins | Notes |
|---|---|---|
| Address (A0-A14) | 10,9,8,7,6,5,4,3,25,24,21,23,2,26,27 | 15 address lines |
| Data (D0-D7) | 11,12,13,15,16,17,18,19 | 8 data lines |
| CS1 | 20 | Configurable polarity |
| CS2 | 22 | Configurable polarity |
| VCC | 28 | +5V |
| GND | 14 | 0V |

### 23512 - 64KB mask ROM with 2 configurable CS lines

**Package:** 28-pin DIP  
**Capacity:** 65536 bytes  
**Control:** 2 configurable CS lines  

| Function | Pins | Notes |
|---|---|---|
| Address (A0-A15) | 10,9,8,7,6,5,4,3,25,24,21,23,2,26,27,1 | 16 address lines |
| Data (D0-D7) | 11,12,13,15,16,17,18,19 | 8 data lines |
| CS1 | 20 | Configurable polarity |
| CS2 | 22 | Configurable polarity |
| VCC | 28 | +5V |
| GND | 14 | 0V |

### 231024 - 128KB mask ROM with 1 configurable CS line

**Package:** 28-pin DIP  
**Capacity:** 131072 bytes  
**Control:** 1 configurable CS line  

| Function | Pins | Notes |
|---|---|---|
| Address (A0-A16) | 10,9,8,7,6,5,4,3,25,24,21,23,2,26,27,1,22 | 17 address lines |
| Data (D0-D7) | 11,12,13,15,16,17,18,19 | 8 data lines |
| CS1 | 20 | Configurable polarity |
| VCC | 28 | +5V |
| GND | 14 | 0V |

### 2704 - 512B EPROM with multiple supply voltages

**Package:** 24-pin DIP  
**Capacity:** 512 bytes  
**Control:** /CE, /OE  

| Function | Pins | Notes |
|---|---|---|
| Address (A0-A8) | 8,7,6,5,4,3,2,1,23 | 9 address lines |
| Data (D0-D7) | 9,10,11,13,14,15,16,17 | 8 data lines |
| CE | 18 | Active low |
| OE | 20 | Active low |
| VPP | 18 | Low during read during read |
| PE | 20 | Low during read during read |
| VCC | 24 | +5V |
| VDD | 19 | +12V |
| VBB | 21 | -5V |
| GND | 12 | 0V |
| GND | 22 | 0V |

### 2708 - 1KB EPROM with multiple supply voltages

**Package:** 24-pin DIP  
**Capacity:** 1024 bytes  
**Control:** /CE, /OE  

| Function | Pins | Notes |
|---|---|---|
| Address (A0-A9) | 8,7,6,5,4,3,2,1,23,22 | 10 address lines |
| Data (D0-D7) | 9,10,11,13,14,15,16,17 | 8 data lines |
| CE | 18 | Active low |
| OE | 20 | Active low |
| VPP | 18 | Low during read during read |
| PE | 20 | Low during read during read |
| VCC | 24 | +5V |
| VDD | 19 | +12V |
| VBB | 21 | -5V |
| GND | 12 | 0V |

### 2716 - 2KB EPROM with fixed active-low CE/OE

**Package:** 24-pin DIP  
**Capacity:** 2048 bytes  
**Control:** /CE, /OE  

| Function | Pins | Notes |
|---|---|---|
| Address (A0-A10) | 8,7,6,5,4,3,2,1,23,22,19 | 11 address lines |
| Data (D0-D7) | 9,10,11,13,14,15,16,17 | 8 data lines |
| CE | 18 | Active low |
| OE | 20 | Active low |
| VPP | 21 | VCC during read during read |
| PE | 20 | Low during read during read |
| VCC | 24 | +5V |
| GND | 12 | 0V |

### 6116 - 2KB (2048 x 8-bit) Static RAM with fixed active-low CE/OE/WE

**Package:** 24-pin DIP  
**Capacity:** 2048 bytes  
**Control:** /CE, /OE, /WRITE  

| Function | Pins | Notes |
|---|---|---|
| Address (A0-A10) | 8,7,6,5,4,3,2,1,23,22,19 | 11 address lines |
| Data (D0-D7) | 9,10,11,13,14,15,16,17 | 8 data lines |
| CE | 18 | Active low |
| OE | 20 | Active low |
| WRITE | 21 | Active low |
| VCC | 24 | +5V |
| GND | 12 | 0V |

### 2732 - 4KB EPROM with fixed active-low CE and shared OE/VPP

**Package:** 24-pin DIP  
**Capacity:** 4096 bytes  
**Control:** /CE, /OE  

| Function | Pins | Notes |
|---|---|---|
| Address (A0-A11) | 8,7,6,5,4,3,2,1,23,22,19,21 | 12 address lines |
| Data (D0-D7) | 9,10,11,13,14,15,16,17 | 8 data lines |
| CE | 18 | Active low |
| OE | 20 | Active low |
| VPP | 20 | Acts as /OE during read |
| PE | 18 | Low during read during read |
| VCC | 24 | +5V |
| GND | 12 | 0V |

### 2764 - 8KB EPROM with fixed active-low CE/OE

**Package:** 28-pin DIP  
**Capacity:** 8192 bytes  
**Control:** /CE, /OE  

| Function | Pins | Notes |
|---|---|---|
| Address (A0-A12) | 10,9,8,7,6,5,4,3,25,24,21,23,2 | 13 address lines |
| Data (D0-D7) | 11,12,13,15,16,17,18,19 | 8 data lines |
| CE | 20 | Active low |
| OE | 22 | Active low |
| VPP | 1 | VCC during read during read |
| /PGM | 27 | High during read during read |
| VCC | 28 | +5V |
| GND | 14 | 0V |

### 27128 - 16KB EPROM with fixed active-low CE/OE

**Package:** 28-pin DIP  
**Capacity:** 16384 bytes  
**Control:** /CE, /OE  

| Function | Pins | Notes |
|---|---|---|
| Address (A0-A13) | 10,9,8,7,6,5,4,3,25,24,21,23,2,26 | 14 address lines |
| Data (D0-D7) | 11,12,13,15,16,17,18,19 | 8 data lines |
| CE | 20 | Active low |
| OE | 22 | Active low |
| VPP | 1 | VCC during read during read |
| /PGM | 27 | High during read during read |
| VCC | 28 | +5V |
| GND | 14 | 0V |

### 27256 - 32KB EPROM with fixed active-low CE/OE

**Package:** 28-pin DIP  
**Capacity:** 32768 bytes  
**Control:** /CE, /OE  

| Function | Pins | Notes |
|---|---|---|
| Address (A0-A14) | 10,9,8,7,6,5,4,3,25,24,21,23,2,26,27 | 15 address lines |
| Data (D0-D7) | 11,12,13,15,16,17,18,19 | 8 data lines |
| CE | 20 | Active low |
| OE | 22 | Active low |
| VPP | 1 | VCC during read during read |
| PE | 22 | Low during read during read |
| VCC | 28 | +5V |
| GND | 14 | 0V |

### 27512 - 64KB EPROM with fixed active-low CE/OE

**Package:** 28-pin DIP  
**Capacity:** 65536 bytes  
**Control:** /CE, /OE  

| Function | Pins | Notes |
|---|---|---|
| Address (A0-A15) | 10,9,8,7,6,5,4,3,25,24,21,23,2,26,27,1 | 16 address lines |
| Data (D0-D7) | 11,12,13,15,16,17,18,19 | 8 data lines |
| CE | 20 | Active low |
| OE | 22 | Active low |
| VPP | 22 | VCC during read during read |
| PE | 20 | Low during read during read |
| VCC | 28 | +5V |
| GND | 14 | 0V |

### 27C010 - 128KB EPROM with fixed active-low CE/OE

**Package:** 32-pin DIP  
**Capacity:** 131072 bytes  
**Control:** /CE, /OE  

| Function | Pins | Notes |
|---|---|---|
| Address (A0-A16) | 12,11,10,9,8,7,6,5,27,26,23,25,4,28,29,3,2 | 17 address lines |
| Data (D0-D7) | 13,14,15,17,18,19,20,21 | 8 data lines |
| CE | 22 | Active low |
| OE | 24 | Active low |
| VPP | 1 | x during read |
| /PGM | 31 | x during read |
| VCC | 32 | +5V |
| GND | 16 | 0V |

### 27C020 - 256KB EPROM with fixed active-low CE/OE

**Package:** 32-pin DIP  
**Capacity:** 262144 bytes  
**Control:** /CE, /OE  

| Function | Pins | Notes |
|---|---|---|
| Address (A0-A17) | 12,11,10,9,8,7,6,5,27,26,23,25,4,28,29,3,2,30 | 18 address lines |
| Data (D0-D7) | 13,14,15,17,18,19,20,21 | 8 data lines |
| CE | 22 | Active low |
| OE | 24 | Active low |
| VPP | 1 | x during read |
| /PGM | 31 | x during read |
| VCC | 32 | +5V |
| GND | 16 | 0V |

### 27C040 - 512KB EPROM with fixed active-low CE/OE

**Package:** 32-pin DIP  
**Capacity:** 524288 bytes  
**Control:** /CE, /OE  

| Function | Pins | Notes |
|---|---|---|
| Address (A0-A18) | 12,11,10,9,8,7,6,5,27,26,23,25,4,28,29,3,2,30,31 | 19 address lines |
| Data (D0-D7) | 13,14,15,17,18,19,20,21 | 8 data lines |
| CE | 22 | Active low |
| OE | 24 | Active low |
| VPP | 1 | x during read |
| /PGM | 22 | Acts as /OE during read |
| VCC | 32 | +5V |
| GND | 16 | 0V |

### 27C400 - 0.5MB EPROM with fixed active-low CE/OE

**Package:** 40-pin DIP  
**Capacity:** 524288 bytes  
**Control:** /BYTE, /CE, /OE  

| Function | Pins | Notes |
|---|---|---|
| Address (A0-A18) | 29,9,8,7,6,5,4,3,2,40,39,38,37,36,35,34,33,32,1 | 19 address lines |
| Data (D0-D7) | 13,15,17,19,22,24,26,28,14,16,18,20,23,25,27,29 | 8 data lines |
| BYTE | 31 | Active low |
| CE | 10 | Active low |
| OE | 12 | Active low |
| VPP | 31 | word_size during read |
| /PGM | 10 | Acts as /OE during read |
| VCC | 21 | +5V |
| GND | 11 | 0V |
| GND | 30 | 0V |

### 27C080 - 1MB EPROM with fixed active-low CE/OE

**Package:** 32-pin DIP  
**Capacity:** 1048576 bytes  
**Control:** /CE, /OE  

| Function | Pins | Notes |
|---|---|---|
| Address (A0-A19) | 12,11,10,9,8,7,6,5,27,26,23,25,4,28,29,3,2,30,31,1 | 20 address lines |
| Data (D0-D7) | 13,14,15,17,18,19,20,21 | 8 data lines |
| CE | 22 | Active low |
| OE | 24 | Active low |
| VPP | 24 | Acts as /OE during read |
| /PGM | 22 | Acts as /OE during read |
| VCC | 32 | +5V |
| GND | 16 | 0V |

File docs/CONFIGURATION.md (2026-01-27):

# Configuration

This document describes Makefile configuration.  This uses also style ROM config files (see [`old-config`](/old-config/) for examples).  Generally, blank firmware images are now created using EXCLUDE_METADATA=1 in the Makefile configuration, and then Studio or Web to construct and image with ROM images - using new style config files (see ['onerom-config'](/onerom-config/) for examples).

---

The top-level [Makefile](/Makefile) allows you to specify a significant number of configuration options, including developer and debug level options.  These are commented in the Makefile.

You can either pass options on the command line, or specify them in a config file which you then include using the `CONFIG` environment variable.  It is recommended to do this rather than modify the original `Makefile`.  For example:

```bash
# Specify ROM images on the command line
MCU=f411re HW_REV=e ROM_CONFIGS=file=images/test/0_63_8192.rom,type=2364,cs1=0 make run
```

```bash
# Or use a pre-built config file
MCU=f405rg CONFIG=old-config/c64.mk make run
```

## Mandatory Configuration

## `STM`

Defines your STM32 variant, for example:

```bash
MCU=f446re
```

See [Supported STM32 Microcontrollers](/README.md#supported-stm32-microcontrollers) for the list of supported variants.

## `HW_REV`

Use this to specify the hardware revision of your One ROM's PCB.  It is silkscreened on the underside of the PCB.  Other ways to identify the revision are:

- Rev D
  - Uses 0402 passives.
  - Has 2x4 jumpers next 2 pin 1 (3 image select jumpers and the `BOOT0` jumper).

- Rev E
  - Uses 0603 passives.
  - Has 2x5 jumpers next to pin 1 (4 image select jumpers and the `BOOT0` jumper).
  - Has a status LED roughly between pins 10 and 14.

```bash
HW_REV=e
```

## `ROM_CONFIGS`

Use this option to specify all of the ROM images to include in your One ROM firmware.  They will be numbered, in the order you provide them, starting from 0.  They can then be selected at boot type, using the image select jumpers.

The format of ROM_CONFIGS is:

```bash
ROM_CONFIGS=FIRST_ROM_INFO SECOND_ROM_INFO THIRD_ROM_INFO ...
```

Where each `..._ROM_INFO` takes the form:

```bash
key1=value1,key2=value2,...,command1,command2
```

Supported key/value pairs are:

- `set`: Optional.  Use for multi-ROMs sets, with multiple images in a set.  You need a line per image within the set, so multiple lines with the same `set` value.  If not specified, the image is in its own set.
- `file`: Required.  The path to the ROM file to include in the firmware.  This can be a local file, or a URL.
- `extract`: Optional.  Valid only if `file` is a URL, and the file to be downloaded is a ZIP file.  This specifies the path within the ZIP file to extract the ROM from.  Use URL encoding to encode any special characters in the path, such as spaces (%20).
- `licence`: Optional.  URL to path for this ROM image's licence.  Including this causes the build process to force the user to explicitly acknowledge they accept the licence terms before the firmware is built.
- `type`: Required.  One of 2364, 2332, 2316 for 8KB, 4KB and 2KB ROM images respectively.  The `file` must be small enough to fit into the specified type.
- `cs1`: Required.  0 or 1, specifying chip select line 1 acts as active low (0) or active high (1).
- `cs2`: Valid for `type=2332` or `type=2316`.  0 or 1, specifying chip select line 2 acts as active low (0) or active high (1).
- `cs3`: Valid for `type=2316`only. 0 or 1, specifying chip select line 3 acts as active low (0) or active high (1).

Supprted commands are:

- `dup`: Optional.  Valid only if file size is less than indicated by `type`, and only if ROM type size if an exact multiple of file size.  Causes the ROM image to be duplicated to fill the remaining space.  This is useful for 2KB and 4KB ROM images which need to be exposed as larger ROMs.
- `pad`: Optional.  Valid only if file size ia less than indicated by `type`.  Pad out the remaining space with 0xAA bytes.  Useful for 2KB and 4KB ROM images which need to be exposed as larger ROMs.

See [`old-config`](/old-config/) for examples of how to specify ROM images.

## Advanced Configuration

A few of the most useful advanced options are described below, but see the [Makefile](/Makefile) for the full list.

### `SWD`

Setting this to 1 enables SWD support within the firmware.  If you do **not** enable this, you will be unable to easily reprogram the device after flashing the image - you will have to use the `BOOT0` jumper.  Also see [`BOOTLOADER`](#bootloader).

This option is also required for [`BOOT_LOGGING`](#boot_logging) (and the other [`logging`](/docs/LOGGING.md) options) to work, as it uses SWD for logging.

### `BOOT_LOGGING`

This is enabled by default, and logs using RTT over SWD as the One ROM boots up.  It stops logging when it enters its main ROM serving loop for performance reasons.

You may wish to disable this logging, if startup speed of One ROM is a problem.  With boot logging enabled, One ROM takes around 2ms to start up and be ready to serve the ROM.  Without boot logging it takes around 500us.

These timings will vary based on clock speed.

### `FREQ`

This is not specified by default, which uses the maximum frequency for the chosen STM32F4xxR variant.  You can lower the frequency if you want to reduce One ROM's power draw.  The [Makefile](/Makefile) gives some guidance on what values are required by what systems, but your mileage may vary.

### `OVERCLOCK`

⚠️ Use with Caution

Enabling this feature allows you to specify a higher frequency than supported by a particular STM32F4xxR variant.  One ROM uses very few peripherals and hence it should be possible for the STM32 to be powered at a higher than stock frequency, but the silicon may not be stable.

The STM32F405 seems to max out at around 250MHz, probably due to the maximum number of flash wait states that can be configured.

The GD32F405 appears to run at 300MHz, although some host instabilities were noticed at this speed - it is possible One ROM is running too fast (serving bytes too quickly, or on brief chip select line glitches, or de-serving them too quickly?).

While currently untested, the STM32F446 may be able to be pushed much higher - as it has capacity for wait states supporting up to around 500MHz.

The STM32F405 seems to max out at around 250MHz, probably due to the maximum number of flash wait states that can be configured.

The GD32F405 appears to run at 300MHz, although some host instabilities were noticed at this speed - possible SDRR is running too fast (serving bytes too quickly, or on brief chip select line glitches, or de-serving them too quickly?).

While currently untested, the STM32F446 may be able to be pushed much higher - as it has capacity for wait states supporting up to around 500MHz.

### `STATUS_LED`

One ROM hardware revisions E and onwards provide a status LED, which is lit once the One ROM has booted and is ready to serve the image.  It also flashes this LED if it crashes.

If you want to reduce power consumption, or just not have the LED lit, use this option (or do not populate the LED on your board).

### `BOOTLOADER`

In addition to the BOOT0 jumper, One ROM provides an option, disabled by default, which will put the STM32 into bootloader mode if all image select jumpers are closed.  This may be useful if you consistently hit [problems flashing](/README.md#flashing-problems).

To use:

- Close all image select jumpers (`1`, `2`, `4`, `8`), but not the BOOT0 (`B0`) jumper.
- Reboot the One ROM device.  It will now be in bootloader mode.
- Optionally change the image select jumpers to the selection you want when the device next boots.
- Reprogram the One ROM device.  It will then reboot, re-read the image select jumpers and start serving the appropriate image.

Enabling this option means that the 16th image (if installed) cannot be selected.

### `SERVE_ALG`

This option allows you to select which serving algorithm to use.

A - Checks address lines all the time, and applies to data lines (which are inputs when CS is not active).  CS is checked twice as frequently as the address lines.

B - Checks address lines only when CS is active, and applies to data lines (which are already outptts).  CS and address lines are read with the same frequency.

In all cases tested, `B` appears to be the superior algorithm, but `A` is kept in case it is incompatible with some systems.

SDRR defaults to `B` is no algorithm is specified for single-ROM sets, and requires `B` (which is applies automatically, even if you specify `A`) for multi-ROM sets.

## Extra C Flags

There are some additional options that can be compiled in/out based on "hidden" C #defines.  You can use `EXTRA_C_FLAGS` to pass these in on the `make` command.

For example this disables loading the ROM table to the STM32F405's CCM RAM, instead loading it to (normal) RAM (SRAM):

```bash
EXTRA_C_FLAGS=-DDISABLE_CCM=1 MCU=f405rg make
```

See [`include.h`](../sdrr/include/include.h) for more information on available options.  These may be have left in a non-compiling state - raise an issue if you have problems.

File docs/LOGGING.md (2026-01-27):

# Logging

There are three types of logging which can be enabled on One ROM.

## `BOOT_LOGGING`

This logs the boot process to the SWD interface, using RTT.  It is enabled by default.  This type of logging stops when the device enters its main ROM serving loop, as with logging enabled the device cannot hit the required performance.

In general, you should be able to leave `BOOT_LOGGING` on, as this only adds around 1.5ms to One ROM's startup time, increasing it to roughly 3ms total.  This is substantially below most retro systems' reset circuit timers, so One ROM should boot and be ready to serve the configured ROM image well before it is required.

Sample boot logs from a startup of firmware built with [`c64-no-destestmax.mk`](/old-config/c64-no-destestmax.mk), are shown below:

```log
13:49:28.943: -----
13:49:28.943: SDRR v0.2.0 (build 1) - https://piers.rocks/u/sdrr
13:49:28.943: Copyright (c) 2025 Piers Finlayson <piers@piers.rocks>
13:49:28.943: Build date: Jul 13 2025 13:49:23
13:49:28.943: Git commit: bed08d2
13:49:28.943: -----
13:49:28.943: Hardware info ...
13:49:28.943: STM32F411RE
13:49:28.943: PCB rev 24-d
13:49:28.943: Flash size: 512KB
13:49:28.943: Flash used: 82KB
13:49:28.943: RAM: 128KB
13:49:28.943: Target freq: 100MHz
13:49:28.943: Oscillator: HSI
13:49:28.943: PLL MNPQ: 8/100/0/4
13:49:28.943: MCO: disabled
13:49:28.943: Bootloader: disabled
13:49:28.943: -----
13:49:28.943: Pin Configuration ...
13:49:28.943: ROM emulation: 24 pin ROM
13:49:28.943: Data pins D[0-7]: PA7,6,5,4,3,2,1,0
13:49:28.943: Addr pins A[0-15]: PC5,4,6,7,3,2,1,0,8,13,11,12,9,255,255,255
13:49:28.943: CS pins - 2364: PC10 2332: PC10,9 2316: PC10,12,9 X1: PC255 X2: PC255
13:49:28.943: Sel pins: PB0,1,2,255
13:49:28.943: Status pin: PNONE255
13:49:28.943: -----
13:49:28.943: ROM info ...
13:49:28.943: # of ROM sets: 4
13:49:28.943: Set #0: 1 ROM(s), size: 16384 bytes
13:49:28.943:   ROM #0: kernal.901227-03.bin, 2364, CS1: Active Low, CS2: -, CS3: -
13:49:28.943: Set #1: 1 ROM(s), size: 16384 bytes
13:49:28.943:   ROM #0: basic.901226-01.bin, 2364, CS1: Active Low, CS2: -, CS3: -
13:49:28.943: Set #2: 1 ROM(s), size: 16384 bytes
13:49:28.943:   ROM #0: characters.901225-01.bin, 2332, CS1: Active Low, CS2: Active High, CS3: -
13:49:28.943: Set #3: 1 ROM(s), size: 16384 bytes
13:49:28.943:   ROM #0: dead%20test.BIN, 2364, CS1: Active Low, CS2: -, CS3: -
13:49:28.943: -----
13:49:28.943: Running ...
13:49:28.943: !!! VOS not ready - proceeding anyway
13:49:28.943: Set VOS to scale 1
13:49:28.943: Configured PLL MNPQ: 8/100/0/4
13:49:28.943: Set flash config: 3 ws
13:49:28.943: ROM sel/index 0/0
13:49:28.943: ROM kernal.901227-03.bin preloaded to RAM 0x20000000 size 16384 bytes
13:49:28.943: Set ROM count: 1, Serving algorithm: 0, multi-ROM CS1 state: -
13:49:28.943: Start main loop - logging ends
```

Pulling out some highlights:

- The `Hardare info` section logs provide information about the One ROM hardware that this firmware image **was built for**.  This may not necessarily the hardware you are running the firmware on.
- The `Pin Configuration` section logs show the pin mapping used by the firmware, including:
  - The data pins (D[0-7])
  - The address pins (A[0-15])
  - The chip select (CS) pins for each ROM type
  - The image select pins (SEL0, SEL1, SEL2)
  - The status LED pin (if supported)
- The `ROM info` section logs show you how many ROM images are included in the firmare, and some details about them:
  - their file names (as seen by the build process)
  - the ROM type (`2364`, `2332`, `2316`)
  - the chip select line configuration:
    - `0` means active low
    - `1` means active high
    - `-` means not used for this ROM type
- The `Running ...` section logs show One ROM's main activities as it starts up, including:
  - Whether the VOS (voltage scaling) is set to scale 1 (only done on the F411 and only when `FREQ` is > 84Mhz).  While the F405 also required VOS set to scale 1 for high frequency operation, this is its power-on default.
  - What the PLL MNPQ values have been set to (to allow you to check they are as intended to achieve the target `FREQ`).
  - How many flash wait states have been configured (the STM32 required a different number of wait states based on the `FREQ`).
  - `ROM sel/index` shows you what value the image select jumpers were set to, and what index that corresponds to in the firmware.
  - The logs also show the filename of the active ROM image, and whether it has been preloaded to RAM (the default behaviour).
  - Finally, the last line shows that the main loop has started, and that logging has stopped.

## `DEBUG_LOGGING`

This logs extra debug information to the SWD interface, using RTT.  Enabling debug logging can sometimes cause RTT to lose some logs due to its added verbosity - this is typically shown as blank logs.  However, the RTT buffer has been increased in size, so this should not be a problem in most cases.

It is disabled by default, but can be enabled by setting the `DEBUG_LOGGING` configuration option to `1`.  This type of logging is useful for debugging One ROM itself.

Example debug logging:

```log
13:50:58.502: -----
13:50:58.502: SDRR v0.2.0 (build 1) - https://piers.rocks/u/sdrr
13:50:58.502: Copyright (c) 2025 Piers Finlayson <piers@piers.rocks>
13:50:58.502: Build date: Jul 13 2025 13:50:51
13:50:58.502: Git commit: bed08d2
13:50:58.502: -----
13:50:58.502: Hardware info ...
13:50:58.502: STM32F411RE
13:50:58.502: PCB rev 24-d
13:50:58.502: Flash size: 512KB (524288 bytes)
13:50:58.502: Flash used: 84KB 85112 bytes
13:50:58.502: RAM: 128KB (131072 bytes)
13:50:58.502: Target freq: 100MHz
13:50:58.502: Oscillator: HSI
13:50:58.502: PLL MNPQ: 8/100/0/4
13:50:58.502: MCO: disabled
13:50:58.502: Bootloader: disabled
13:50:58.502: -----
13:50:58.502: Pin Configuration ...
13:50:58.502: ROM emulation: 24 pin ROM
13:50:58.502: Data pins D[0-7]: PA7,6,5,4,3,2,1,0
13:50:58.502: Addr pins A[0-15]: PC5,4,6,7,3,2,1,0,8,13,11,12,9,255,255,255
13:50:58.502: CS pins - 2364: PC10 2332: PC10,9 2316: PC10,12,9 X1: PC255 X2: PC255
13:50:58.502: Sel pins: PB0,1,2,255
13:50:58.502: Status pin: PNONE255
13:50:58.502: -----
13:50:58.502: ROM info ...
13:50:58.502: # of ROM sets: 4
13:50:58.502: Set #0: 1 ROM(s), size: 16384 bytes
13:50:58.502:   ROM #0: kernal.901227-03.bin, 2364, CS1: Active Low, CS2: -, CS3: -
13:50:58.502: Set #1: 1 ROM(s), size: 16384 bytes
13:50:58.502:   ROM #0: basic.901226-01.bin, 2364, CS1: Active Low, CS2: -, CS3: -
13:50:58.502: Set #2: 1 ROM(s), size: 16384 bytes
13:50:58.502:   ROM #0: characters.901225-01.bin, 2332, CS1: Active Low, CS2: Active High, CS3: -
13:50:58.502: Set #3: 1 ROM(s), size: 16384 bytes
13:50:58.502:   ROM #0: dead%20test.BIN, 2364, CS1: Active Low, CS2: -, CS3: -
13:50:58.502: Execute from: Flash
13:50:58.502: -----
13:50:58.502: Running ...
13:50:58.502: !!! VOS not ready - proceeding anyway
13:50:58.502: Set VOS to scale 1
13:50:58.502: HSI cal value: 0x7C
13:50:58.502: Not trimming HSI
13:50:58.502: Configured PLL MNPQ: 8/100/0/4
13:50:58.502: PLL started
13:50:58.502: SYSCLK/2->APB1
13:50:58.502: Set flash config: 3 ws
13:50:58.502: PLL->SYSCLK
13:50:58.502: ROM sel/index 0/0
13:50:58.502: ROM filename: kernal.901227-03.bin
13:50:58.502: ROM type 2364
13:50:58.502: ROM size 16384 bytes
13:50:58.502: ROM kernal.901227-03.bin preloaded to RAM 0x20000000 size 16384 bytes
13:50:58.502: Set ROM count: 1, Serving algorithm: 0, multi-ROM CS1 state: -
13:50:58.502: Start main loop - logging ends
13:50:58.502: Serve ROM #0: kernal.901227-03.bin via mode: 0
13:50:58.502: ROM type: 2364
13:50:58.502: CS1 active low
13:50:58.502: -----
13:50:58.502: Register locations and values:
13:50:58.502: GPIOA_MODER: 0x28000000
13:50:58.502: GPIOA_PUPDR: 0x24000000
13:50:58.502: GPIOA_OSPEEDR: 0x0000AAAA
13:50:58.502: GPIOC_MODER: 0x00000000
13:50:58.502: GPIOC_PUPDR: 0xA0000000
13:50:58.502: VAL_GPIOA_ODR: 0x40020014
13:50:58.502: VAL_GPIOA_MODER: 0x40020000
13:50:58.502: VAL_GPIOC_IDR: 0x40020810
13:50:58.502: CS check mask: 0x00000400
13:50:58.502: CS invert mask: 0x00000000
13:50:58.502: Data output mask: 0x28005555
13:50:58.502: Data input mask: 0x28000000
13:50:58.502: ROM table: 0x20000000
13:50:58.502: -----
```

## `MAIN_LOOP_LOGGING`

This enables logging within the main_loop (see [`rom_impl.c`](/sdrr/src/rom_impl.c).  It does not control logging after every byte is served - see [`MAIN_LOOP_ONE_SHOT`](#main_loop_one_shot)

You mus have `SWD` and `BOOT_LOGGING` enabled for this to work.

## `MAIN_LOOP_ONE_SHOT`

This makes a log after every requested byte has been served, once the chip select has gone inactive.

Some notes:

- It is **highly** likely that enabling this will cause the One ROM to not be able to keep up with the requested data, and so it is disabled by default.
- It is also likely, unless you are only querying the odd byte here and there, that RTT will not be able to keep up with the logged data.
- Although the address and data values served are logged, these are **mangled** versions of each - they are the value read directly from the STM32 GPIO port with the address and CS lines, and the value written directly to the STM32 GPIO port with the data lines.  As the pin mapping is complex, they are not the values you would naively expect to see.  See [Technical Details](/docs/TECHNICAL-DETAILS.md) for more information on the the pin mapping.

This logging is disabled by default and can be enabled by setting the `MAIN_LOOP_ONE_SHOT` configuration option to `1`.  This type of logging is useful for debugging the One ROM's main loop.

You must have `SWD`, `BOOT_LOGGING`, and `MAIN_LOOP_LOGGING` enabled for this to work.

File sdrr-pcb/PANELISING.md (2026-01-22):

# PANELISING PCBs

WORK IN PROGRESS - DO NOT USE

## Setup

Install kikit into the KiCad python environment:

```zsh
/Applications/KiCad/KiCad.app/Contents/Frameworks/Python.framework/Versions/Current/bin/python3 -m pip install kikit
```

add to .zshrc
```
alias kikit='/Applications/KiCad/KiCad.app/Contents/Frameworks/Python.framework/Versions/Current/bin/python3 -m kikit.ui'
```

```zsh
source ~/.zshrc
```

## Usage

1. Generate the panel using kikit:

    ```zsh
    mkdir -p panels/fire-24-d-5x4-panel
    kikit panelize -p support/fire-24-d-5x4-panel-config.json verified/fire-24-d/kicad/fire-24-d.kicad_pcb panels/fire-24-d-5x4-panel/fire-24-d-5x4-panel.kicad_pcb
    ```

2. Manually add "CNC" on Edge Cuts in spaces that should be milled out.

3. Export gerbers (do not refill zones) and drill files.  It's best to export to a sub-directory.  Create a zip file of the contents of that directory for submission.

4. Upload the gerbers.

5. Select colour.

6. Select Panel by Customer and the number of columns/rows.

7. Ensure Remove Mark selected.

8. Select Confirm Production file.

9. Select PCB Assembly.

10. Select Standard (not Economic, as this includes V-CUT).

11. Select Edge Rails/Fiducials Added by Customer.

12. When adding BOM, ensure "Single Piece, pls help me repeat the data" is selected.

13. Ensure all parts selected.

Use the standard bom and pos files.

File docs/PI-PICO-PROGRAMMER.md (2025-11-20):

# Raspberry Pi Pico as a Programmer

To use a stock Raspberry Pi Pico as a programmer for One ROM, download the `debugprobe_on_pico.uf2` file from the [Releases](https://github.com/raspberrypi/debugprobe/releases) page of Raspberry Pi's `debugprobe` repository.

Mount your Raspberry Pi Pico in BOOTSEL mode and copy the `debugprobe_on_pico.uf2` file to the Raspberry Pi Pico's file system.

The required pins on the Pico are:

- CLK - GP2 (pin 4)
- DIO - GP3 (pin 5)
- GND - any GND pin (3, 8, 13, 18, 23, 28, 33, 38)
- 5V - (if **not** connected to a retro system) - VBUS (pin 40)

Note that some Pico clone boards may have different pin numbering.  Usually GP2/GP3/GND are marked on the board using silkscreen.

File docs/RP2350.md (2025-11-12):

# RP2350

In response to Raspberry Pi's July 2025 announcement of [5V tolerant GPIOs](https://www.raspberrypi.com/news/rp2350-a4-rp2354-and-a-new-hacking-challenge/) coinciding with the new RP2350 A4 stepping, I added support for the RP2350 to my open source STM32F4-based retro ROM emulator, [One ROM](https://piers.rocks/u/one).  I learned many interesting things.  This post covers the ones that I haven't forgotten.

If you'd rather consume this content in video form see below - this article contains extra detail.

<div class="video-container">
    <iframe 
        width="560" 
        height="315" 
        src="https://www.youtube.com/embed/Zy8IMe6fMI4" 
        frameborder="0" 
        allow="accelerometer; autoplay; encrypted-media; gyroscope; picture-in-picture" 
        allowfullscreen>
    </iframe>
</div>

Summary:

- The RP2350 is sort of **cheaper** than the STM32F4 and it's sort of not.
- While the RP2350 has 5V tolerant GPIOs, you still have to be **careful**.
- The recommended PCB layout for the RP235X is **extremely** painful on such a space constrained, 2-layer board.
- The RP2350 silicon appears to take about **10ms** to come out of reset, with a further approximately 5ms required by the (ROM) bootloader to start application code.
- Overclocking is entirely feasible - operation up to **540MHz** with a VREG voltage of 1.6V has been achieved, with faster clocks likely possible.  A more reasonable recommendation might be around 400MHz (1.3V).
- Programming the Pico 2/RP2350 with Rust-based [`probe-rs`](https://github.com/probe-rs/probe-rs) is a bit of a **pain**.  Perhaps other software would work better?
- In some of my use-cases the RP2350 must be clocked slighter faster than an STM32.  I suspect this is due to differences in the flash and memory subsystems.
- The RP2350's GPIO Coprocessor (GPIOC) is **slower** than using its SIO to access GPIOs.
- The RP2350's flash **XIP cache pinning** either doesn't do what I think it does, or is broken.  I tried pinning my main_loop() function to the XIP cache, but the core crashed.
- The SIO has a limitation on **sub-word writes**, which can be turned into a feature.
- **Erratum E9** does appear to be fixed in the A4 stepping - my application uses internal pull-ups successfully. 
- My first PCB revision **just worked** - meaning the first PCB layout was a success.  (The firmware didn't quite work first time, but only took a few hours to get fully functional.)

I'm glad I've ported the hardware and firmware to the RP2350 - it was a fantastic learning experience, and, on balance, it looks like it's a [better solution](#conclusion) for serving ROMs to retro systems.

The gory details follow.

## Introduction

All of the learning documented here was earned as part of the [One ROM](https://piers.rocks/u/one) project, which aims to provide the most flexible ROM replacement for retro systems.  Think Commodore 64, Atari 2600, TI-99 ...

One ROM is the form factor of an original 24-pin ROM chip (small!), but instead driven by a micro-controller with 5V tolerant GPIOs, reading the ROM's address and chip select lines, and serving data to its data lines.  I originally went with the STM32F4 as the cheapest MCU with 5V tolerant GPIOs that had the horsepower to do the job.

The application's main_loop() is hand rolled ARM thumb assembly.  No interrupts, no PIOs (at least, yet), single core, using a bunch of hardware and software tricks to get the ROM serving as fast as possible.  The main application startup and setup code is all bare metal C, with no HAL - just direct MCU register access.

Coming into the One ROM's RP2350 development, I already had a fully functional STM32F4 implementation, with mature PCB designs and firmware.

All told the layout of my first RP2350 layout for One ROM took around 12 hours, including much back forth over the [Hardware design with RP2350](https://datasheets.raspberrypi.com/rp2350/hardware-design-with-rp2350.pdf), as well as the datasheet.  I started from the existing STM32F4 layout.

Porting of the firmware, initial testing on a Pico 2, and then subsequently getting it working on the One ROM RP2350 board took around 20 hours, with much of that being poring over the RP2350 datasheet to get the bare metal register implementation correct.

## Price

One of the recurring comments I've heard from folks is that the RP2350 is cheaper than the STM32F4 MCUs.  The Raspberry Pi marketing folks have done a fantastic job of convincing people of this - but what is the reality?

I use [LCSC](https://lcsc.com) as a price reference here, as they are a large, cheap, reputable, Chinese component supplier (JLC PCB's component arm), with good prices and stock, and they serve where I live (the UK).  Prices are as of August 2025 and are for single units, unless otherwise stated.

I chose the STM32F411RET6 as my comparison.  Yes, the RP2350 is quite a lot more powerful, but the STM32F411RET6 is sufficient to get One ROM's job done and is a good bang for the buck.

| RP2350A  | STM32F411RET6  |
|---|---|
| $1.74 | $2.69 |

Wow 35% cheaper!  But wait, the RP2350A needs other components the STM32F4 includes internally:

- An external crystal oscillator
- External flash
- A (somewhat specialised) inductor for the internal voltage regulator 
- More passives (I'll ignore - they make just a few cents difference)

Ok, so here's a fuller BOM:

| Components | RP2350A | STM32F411RET6 |
|---|---|---|
| MCU | $1.74 | $2.69 |
| Crystal | $0.43 | - |
| Flash* | $0.53 | - |
| Inductor*  | $0.28 | - |
| **Total**  | **$2.98** | **$2.69** |

\* Flash and inductor not available by the single piece - piece price in quantities of 5 used instead.

That's 11% **more expensive** for the MCU-related components.

In fact, it's worse than this if getting boards assembled, which, face it, you likely will for this application, as I had to go with 0402 passives, and the RP2350 is also not really hand-solderable.  Each of the crystal, flash and inductor are JLC PCB "extended" parts, which means a one off additional $3 fee per part, per order.  If you make the minimum batch of 5 boards, this is $9 extra, or $1.80 per board.

Now the RP2350A and supporting components are **67% more expensive** than the STM32.

Perhaps I've been a bit unfair here.  In reality I would probably be ordering the STM32F4 clone from GigaDevices, the GD32F405RGT6 ($3.28).  The per-board cost would then be the same at 30 boards, and then the RP2350 based board would get cheaper for quantities above that.  And the RP2350 does have that second core, and more RAM and flash ...

Aside.  The figures above are just for the MCU and supporting components.  For the entire assembled One ROM RP2350 PCB (without pins) from JLC you are, as of writing, looking at:
- $44 for 5 - $8.80 each
- $89.50 for 20 - $4.45 each
- $320 for 100 - $3.20 each

Taxes and shipping not included.

## 5V Tolerance

Much has been made of the new RP2350's newly qualified 5V tolerant GPIOs.  This is true for GPIOs 0-25, but not for the ADCs - GPIOs 26-29.  One ROM therefore uses pins 0-23 to connect to the host.

Also, the input/output high/low voltage thresholds in the datasheet do seem to be compatible with the retro chips One ROM is used with (6502, VIC-II chip, etc).

**Caution**  Like the STM32F4, the RP2350 has an absolute maximum voltage on any pin of 5.5V.  The original Commodore chips tended to tolerant up to 7V, at least according to their datasheets.  This is likely to be the case for other types of retro systems.  If you have a retro machine with a suspect voltage regulator or power supply, and the voltage goes up 5.5V, your One ROM is at risk.

## Space Constraints and Layout

Due to the physical form factor of the ROMs being replaced by One ROM, and other design choices (the desire to have image select jumpers, the same programming header as the STM version, and only have components on a single side to keep manufacturing cost low), the entire area of the PCB available for the RP2350, plus supporting componentry, is roughly **17mm x 14mm**.  A thumbnail if you have slightly bigger thumbnails than me.  Or around 1/3 sq inch.

While the RP2350 itself is only 7mm x 7mm, I had to include:
- A voltage regulator (as per the STM32 boards, the AP2112K).
- External flash (it is internal on the STM32s).
- External crystal oscillator (it is internal and reasonably good on the STM32s - the internal oscillator on the RP2350 is, frankly, crap, and only good - and probably only intended for - getting the chip to start up).
- External decoupling and voltage regulator capacitors (similar to the STM32 boards, but more of them are recommended).
- A polarised (!) inductor for the internal voltage regulator (not required on the STM32).
- Status LED, resistor and a few pull-ups (per the STM32 boards).

This is around 30 surface mount components in total.  The 7x7mm RP2350 and the 3.2x2.5mm crystal are starting to look mighty large at this point.

As with the STM32 boards it was a design goal to avoid going below 0402 sized components, to make hand-assembly at least possible (not necessarily easy), and to be able to use the cheapest PCB assembly services.

At this point you might be thinking "sure, but the STM32 package you use on those boards is huge so surely that was tought to route around".  Yes, it is large - 14mm x 14mm.  But, and it is a very big but, you can route traces directly underneath it as it has no ground pad.

Much of the underside of the RP2350 is a solid ground pad, with any remaining space taken up by the 2 required power voltages.  In addition, you're supposed to have stitching vias through the entire ground pad, primarily to help with heat dissipation, but also to provide a good ground return path for things like the external voltage regulator circuitry.

This would mean that you also can't route traces on the underside of the PCB either, under the RP2350.  This might then push you, not to a 4-layer board (gains you very little in this case), but to a 6-layer board (expensive).  And/or to very fine traces.  But the 6 mils (6/1000ths of an inch) I used tends to be the minimum side supported by the cheapest PCB fab services.

In the end, with some creative pin assignments (that still allow One ROM's highly optimised assembly code to be very similar to the STM32 version), very few stitching vias, and a lot of careful routing, I managed to fit everything in.  But just barely.  In hardware revision A, only 3 image select jumpers are exposed, compared to the STM32F4's 5 - although there are 2 more unused GPIOs just waiting to be used.  By the time you read this, there may be a further revisions with more jumpers exposed - I have an idea that might just allow me to get them routed.

## Power On

I measured power on delay using an oscilloscope, measuring the time from 3.3V becoming available on the chip, until the main loop started executing.  I know when the main loop has started execting by measuring GPIO 26 which drives One ROM's status LED - it is pulled low at the start of the loop execution (and, in fact, due to one of my software optimisations, shows bytes being served which is fun!).

I see:
- GPIO 26 go mid-level (~1.8V) at power on, and stay there for 10ms.
- GPIO 26 go high (3.3V) at that point and stay there for 8ms in "normal" operation, with One ROM's debug logging enabled.
- GPIO 26 then goes low and starts showing bytes being served.

By removing logging and ROM image preload to RAM I can reduce the GPIO 26 high period to 6ms.

This suggests 10ms for the chip to come out of reset, 5ms for the ROM bootloader to start One ROM's code, and 1-3ms for the code to get to the main loop (depending on build options).

There are unlikely to be major gains possible here.  It may be possible to speed up One ROM's preloading the ROM image to RAM (which is necessary - serving from ROM would be too slow), by using DMA instead of a memcpy, but it's only going to save around a millisecond at the most.

The STM32F4, in the same application takes under **2ms** (1.5ms in testing) from power on to main_loop execution.  That's an order of magnitude faster.

## Overclocking

There are a number of considerations when overclocking the RP2350.

### PLL Settings

Simply, the on-board PLL takes the clock source (external crystal in this case), and takes it through an number of multipliers and dividers to generate the system clock.  

The Pico SDK tool `vcocalc.py` is very useful for calculating the settings required, although One ROM generates its own PLL settings based on the frequency requested at build time.

### Flash Speed

The appropriate flash access timing must be set using the QMI `M0_TIMING` register.  The flash chosen for revision A is the W25Q16JV, which has a maximum clock speed of 133MHz.  When clocking the RP2350 beyond this speed, the system clock needs to be divided down for flash access.  A divider of 3 is actually the RP2350's default, but One ROM is more aggressive, and sets it lower if it can according to the target MCU frequency.

### Regulator Voltage

The stock voltage regulator voltage is 1.1V, which, from testing, is good to drive the RP2350 up to around 300MHz.  Beyond that, the voltage needs to be increased.  420MHz was possible with 1.3V, but was probably right on the edge.  Frequencies beyond that need higher voltages, which in turn requires unlocking voltage limits within the RP2350.  540MHz at 1.6V was the highest I was prepared to go, and One ROM faithfully served a C64 character ROM at this speed.

Your mileage is likely to vary, depending on the exact silicon you have, temperature, application, cosmic particles, etc.

### Temperature

Running faster, means more power, means more heat.  One ROM's first RP2350 PCB has only 2 stitching vias from the RP2350 GND pad to the underside, as opposed to 9 in the reference design, so its ability to dissipate heat is limited.  If overclocking you would be wise to install a small heat-sink on the RP2350, to monitor temperature, and perhaps expect premature failure of the RP2350.

The RP2350 has an internal temperature sensor, which can be read using the ADC peripheral.  When overlocking beyond 300MHz is enabled, One ROM enables the ADC and temperature sensor, and reads it and logs it before entering its main loop.  You could continue to read this periodically - which would be more useful than detecting the temperature before it starts working hard! - either via an external [SWD device](https://piers.rocks/u/airfrog), or with code running on the second core (which would generate more heat...).

## Programming

One ROM has no USB connection, so therefore an SWD Debug Probe like Raspberry Pi's Debug Probe is used to program it.

During development I mostly used Rust-based `probe-rs` to program the RP2350, while it was installed in a host (a long-suffering Commodore 64).

I found that I had to put the RP2350 into BOOTSEL mode (pulling BOOT low and resetting), in order to program it each time.  This is a bit of a pain, as you have to short a cable from the PCB's USB_BOOT  to GND, and then power cycle the board.  You know when One ROM's in BOOTSEL mode, as the status LED will glow faintly - presmably due to the RP2350 leaving GPIO 26 in an uninitialized state while starting up.

I suspect this programming issue is due to `probe-rs` not fully resetting the RP2350 before programming it, rather than an RP2350 specific problem.  If I tried to re-program the RP2350 without pulling in BOOTSEL mode, the first re-flash appeared to work - but hadn't really.  A second time hard-failed.

The same behaviour was observed with a Pico 2 (W), so I don't believe this is a problem with the One ROM PCB.

## Speed vs STM32

To get the obvious comparisions out of the way first:

| |  RP2350  |  STM32F4 |
|---|---|---|
| Max Speed | 150MHz | 84-180MHz |
| Cortex | M33 | M4 |
| Cores | 2 | 1 |
| Flash | External | Internal |
| RAM | 520KB | 64-192KB |

The code between the STM32F4 and RP2350 variants of One ROMs is very, very similar, and in particular, at the time of writing, the assembly main byte serving loop is essentially identical.  You would therefore naively expect the performance to be the same, Hz for Hz between the two devices, as they are both ARM Cortex cores, running the same assembly, at the same speed.

However, this is not the case.

But first, what do I mean by performance?  I mean One ROM serving bytes to the host system, so it behaves correctly and does not crash.  If one MCU can serve a C64 character ROM without visual glitches or host crashes, at 80MHz, but another needs 100MHz, I consider the latter to be slower, and might be very loose and say it's 20% slower, or the other 20% faster.  Yes, my stats teacher would be horrified.  I never liked stats.  But it's all **approximate** anyway so try not to get too angry with me.

Minimum clock speeds required:

| |  RP2350 |  STM32F4 |
|---|---|---|
| C64 char ROM | 80Mhz | 80MHz |
| C64 kernal ROM | **90MHz** | 84MHz |

Why do I think there is any difference?  Two key reasons:

- Flash, in particular, instruction cache.
- RAM and bus architecture.

### Flash

The STM32F4xxR series has an ART Accelerator.  I won't get into the gory details here, but for One ROM it appears to cause the device to behave as if the device has zero flash wait states.  This is a good thing.

There are also some differences between STM32F4 models here - the F405's ART Accelerator appears worse than the other, later models, such as the F401, F411 and F446.  So let's forget about the F405 for now.  The ART Accelerator for the others is great, a least for One ROM.  There appears to be zero touching of flash from within One ROM's main loop, and I can erase and re-program One ROM's flash while the main loop is running, without any problems.

The RP2350 on the other hand has a quite difference flash architecture.  For one thing, flash is external using QSPI, and for another the RP2350 has an XIP (eXecute In Place) cache instead of the ART Accelerator.  I don't fully understand it (see [XIP Cache Pinning](#xip-cache-pinning) later!), but it is a different approach to caching.

In One ROM I attempt to "warm" the XIP cache by reading the main_loop() function from flash, immediately before executing it.  Maybe this helps, I'm not sure.  But I suspect it isn't as good as the STM32's ART Accelerator for this application and hence I think there may be more variability in performance Hz for Hz.  And perhaps the C64's 6510 processor is more sensitive to timings than the VIC-II is - hence replacing the kernal ROM requires a slightly faster clock speed than the character ROM.  I'm speculating. 

### RAM and Bus Architecture

Like the flash, I think the RAM and bus matrix architecture is a bit different between the two MCUs, although there's not that many details in the RP2350 datasheet on this topic.

I therefore think that the RP2350 may involve a bit more jitter while running due to bus contention than the STM32.  Having said this, I am currently loading bytes to be served via RAM, and accessing GPIOs via the SIO, which probably is using the same bus matrix and probably introducing contention.

I **might** be able to reduce contention by using PIOs to serve bytes (it has direct GPIO connection).  However, using the direct GPIO Coprocessor (GPIOC) is [slower](#gpio-coprocessor) when compared to SIO access.

I did upload the ROM image to be served to a dedicated SRAM bank to try and reduce contention.  Maybe that helped?

## GPIO Coprocessor

What is the GPIO Coprocessor (GPIOC)?  Cortex M33 (on which the RP2350 is based), has a concept of co-processors, which are directly connected to the core, and can be accessed using ARM-v8m instructions, such as MCR. This approach is described in the RP2350 datasheet 3.6.1 GPIO Coprocessor (GPIOC).

There are two primary benefits touted of this approach:

- You bypass the bus matrix, and therefore avoid bus contention.
- You can operate on the entire 48 GPIOs in a single instruction.  The RP2350A only has 30 GPIOs, so this is irrelevant.

I tested using MCR instructions to set the data lines to outputs/inputs (when the ROM chip select goes active/inactive) and found **worse** performance when using GPIOC compared with SIO.  Specifically, for serving the C64 character ROM stably, I needed to at 80MHz using GPIOC, vs 78MHz using SIO.

(Yes, this figure of 78MHz conflicts with the 80MHz given earlier - it was a different day, and such variations happen.)

I speculate one or both of two reasons for this:

- XIP instruction cache impact.  The MCR instructions are 32-bit wide, rather than the STR instructions I use in the SIO case.  I struggle to believe this as the cause, as this approach only introduces 4 more bytes into the very compact main loop.
- The GPIO Coprocessor is simply not as optimised as the memory-mapped GPIO and bus access.

I have not really found **anything** online discussing this approach, either using the RP2350, or other ARM Cortex processors.  It is possible that any benefit would be more apparent in a different use case, for example when using the second core for heavy memory access.

I have not attempted to use GPIOC to read the address lines, or to apply values to the data lines, as my current approach will always be faster - it requires no masking or bit shifting as a result of some cunning PCB and assembly optimisations.  A GPIOC approach would require shifting/masking (an extra cycle) in both cases.

## XIP Cache Pinning

Reading the RP2350 datasheet, in particular 4.4. External Flash and PSRAM (XIP), I concluded that I could "pin" certain flash addresses to the XIP cache, in order to ensure the main_loop() was already loaded into the XIP cache, and would be executed from there - to avoid any wait states if the CPU had to load instructions from flash.  Even a single wait state during the first iteration of the main loop and therefore failing to serve the **first** byte quite within the necessary time can crash the ROM's host.

I tried this pinning - by reading the main_loop() function from flash, and then pinning it to the XIP cache.

I tried pinning jut "way" 0, and pinning both "ways".

However, this either caused a core lock-up (when pinning both ways and then continuing), or a fault (pinning way 0 then continuing).  I don't know why, but suspect I have misunderstood the XIP cache, and it's really intended for use with external PSRAM instead.

## SIO Sub-word Writes, and Reads

The RP2350's single-cycle IO (SIO) subsystem is, as it sounds, used to perform single-cycle reads and writes to GPIOs.  All of the SIO registers are 32-bit wide, and registers are provided to modify individual or arbitrary sets of bits with single-cycle (atomic) operations.

Buried in the detail elsewhere in the datasheet, in 2.1.5 Narrow IO Register Writes is the statement:

"[Memory-mapped IO registers] treat all writes as though they were 32 bits in size.  This means software cannot use byte or halfword writes to modify part of an IO register: any write to an address where the 30 address MSBs match the register address affects the contents of the entire register."

This suggests that one cannot safely write an 8-bit or 16-bit value to an SIO register.  This can be done on other MCUs.  This limitation is fine for many use cases - just mask/shift your bits and use the registers that operate on that desired set of bits.  But in the One ROM use case, every cycle counts.  Reading on:

"Upon a 8-bit or 16-bit write (such as a strb instruction on the Cortex-M33), the narrow value is replicated multiple times across the 32-bit data bus, so that it is broadcast to all 8-bit or 16-bit segments of the destination register"

Aha, this is very useful.  In One ROM we read a single byte from RAM and want to apply it to 8 data lines, GPIOs 16-23.  This means we can write the **byte** (8-bits) we have just retrieved from RAM to the SIO's GPIO OUT register, and the hardware will replicate it across the entire 32-bit register, and apply it to GPIOs 16-23 - avoiding a shift operation, saving a cycle.  As we don't have any other GPIOs in output mode, this is a safe operation, and we don't mind having the other GPIO outputs set with the same byte.

The is no similar limitation on reads - we can read an 8-bit or 16-bit value from an SIO register without problems.  This is also useful in One ROM, as we have the address and CS lines as GPIOs (0-15), allowing us to read the entire address and CS state with a single ldrh (half-word load) instruction.  This is then used as an offset to a RAM array containing the bytes to be served.  Again, no shift or mask is required, saving a cycle.

## Erratum E9

Erratum E9 affects the RP2350 A2 stepping and essentially prevents the use of RP2350's internal pull-ups/pull-downs, requiring external pulls (where pulls are required).

One ROM makes use of internal MCU pulls, both for its image select jumpers (which are read at boot time to select a ROM image), and at run-time (to allow dynamic switching between images and also serving multiple ROM sockets simultaneously from a single ROM).  External pulls are avoided due to board space issues - there simply isn't space for the 5x0402s that would be required for external pull.

I can report that One ROM's image/bank/rom switching function operates as designed, so although I haven't explicitly tests the internal pulls, they do appear to be operating as expected.

## It Verks

This is what most surprised me, and much as I thought ill of them during PCB layout, the Raspberry Pi engineers have done a cracking job of [Hardware design with RP2350](https://datasheets.raspberrypi.com/rp2350/hardware-design-with-rp2350.pdf).  I read it and re-read it repeatedly during design and layout, and BOM selection, and followed it as closely as possible - and I was rewarded by One ROM's RP2350 design working first time.

Ship it!

## Conclusion

What are my takeaways?

Although I remain a bit nervous of the RP2350's absolute maximum voltage on any pin of 5.5V (as I've seen some of my systems hit 5.5V), now I am past the pain of the fscking board layout, I think the RP2350 gives an overall better solution than the STM32F4:

- It is roughly the same price or cheaper in quantity.
- It can be laid out on a the PCB in the same space as alternatives.
- It is roughly as performant (within 10%) at the same clock speed.
- It can be overclocked higher.
- It has more flash, more RAM, a second core, and those PIOs.
- It's British.

Well done Raspberry Pi.

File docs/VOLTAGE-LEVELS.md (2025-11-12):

# Voltage Levels

## Background

One of the biggest difficulties of this project, alongside hitting the timing requirements, was finding a microcontroller tha could support the 5V logic levels required by retro systems.

The STM32F1 series (64-bit variant) on the face of it has the required number of 5V tolerant (FT) GPIOs, but on further examination, there are not sufficient contiguous and starting at pin 0, FT pins on any port to hit the required performance - that is to allow the assembly code to perform optimal chip select comparisons, address lookups, and apply the results those to the data pins.
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

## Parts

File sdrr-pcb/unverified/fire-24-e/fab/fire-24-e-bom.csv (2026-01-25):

Reference | Qty | Value | DNP | Exclude from BOM | Exclude from Board | Footprint | Datasheet | LCSC
C1,C2,C7,C13,C15 | 5 | 4.7uF |  |  |  | Capacitor_SMD:C_0402_1005Metric | ~ | C23733
C3,C4,C5,C6,C8,C9,C10,C11,C12 | 9 | 0.1uF |  |  |  | Capacitor_SMD:C_0201_0603Metric | ~ | C668346
C16,C17 | 2 | 4.7uF |  |  |  | RP2350_60QFN_minimal:C_0402_1005Metric_small_pads | ~ | C23733
C18,C19 | 2 | 15pF |  |  |  | Capacitor_SMD:C_0201_0603Metric | ~ | C85891
D1 | 1 | LED_Small |  |  |  | LED_SMD:LED_0402_1005Metric | ~ | C25503345
D2,D3 | 2 | 1N5819WS |  |  |  | Diode_SMD:D_SOD-323 |  | C191023
J4 | 1 | USB_C_Receptacle_USB2.0_16P |  |  |  | piers retro:USB_C_connector_c2765186 | https://www.usb.org/sites/default/files/documents/usb_type-c.zip | C2765186
L1 | 1 | 3.3u |  |  |  | RP2350_60QFN_minimal:L_pol_2016 | ~ | C42411119
R1,R3,R7,R8 | 4 | 10K |  |  |  | Resistor_SMD:R_0201_0603Metric | ~ | C473048
R2,R5,R6 | 3 | 1K |  |  |  | Resistor_SMD:R_0201_0603Metric | ~ | C270365
R4 | 1 | 33R |  |  |  | Resistor_SMD:R_0402_1005Metric | ~ | C25105
R9,R10 | 2 | 5K1 |  |  |  | Resistor_SMD:R_0201_0603Metric | ~ | C270344
U1 | 1 | RP2350_60QFN |  |  |  | RP2350_60QFN_minimal:RP2350-QFN-60-1EP_7x7_P0.4mm_EP3.4x3.4mm_ThermalVias |  | C41378174
U3 | 1 | AP2112K-3.3 |  |  |  | Package_TO_SOT_SMD:SOT-23-5 |  | C51118
U4 | 1 | USBLC6-2P6 |  |  |  | Package_TO_SOT_SMD:SOT-666 | https://www.st.com/resource/en/datasheet/usblc6-2.pdf | C15999
Y1 | 1 | Crystal_GND24 |  |  |  | Crystal:Crystal_SMD_Abracon_ABM8G-4Pin_3.2x2.5mm | ~ | C20625731

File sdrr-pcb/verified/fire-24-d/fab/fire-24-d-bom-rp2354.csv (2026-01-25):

Reference | Qty | Value | DNP | Exclude from BOM | Exclude from Board | Footprint | Datasheet | LCSC
C1,C2,C3,C7,C13,C15 | 6 | 4.7uF |  |  |  | Capacitor_SMD:C_0402_1005Metric | ~ | C23733
C4,C5,C6,C8,C9,C10,C11,C12 | 8 | 0.1uF |  |  |  | Capacitor_SMD:C_0402_1005Metric | ~ | C1525
C16,C17 | 2 | 4.7uF |  |  |  | RP2350_60QFN_minimal:C_0402_1005Metric_small_pads | ~ | C23733
C18,C19 | 2 | 15pF |  |  |  | Capacitor_SMD:C_0402_1005Metric | ~ | C1548
D1 | 1 | LED_Small |  |  |  | LED_SMD:LED_0603_1608Metric | ~ | C2286
D2,D3 | 2 | 1N5819WS |  |  |  | Diode_SMD:D_SOD-323 |  | C191023
J6 | 1 | USB_B_Micro |  |  |  | piers footprints:USB_Micro-B_micro_xnj_073_C404969 | ~ | C404969
L1 | 1 | 3.3u |  |  |  | RP2350_60QFN_minimal:L_pol_2016 | ~ | C42411119
R1,R3,R7,R8 | 4 | 10K |  |  |  | Resistor_SMD:R_0402_1005Metric | ~ | C25744
R2,R5,R6 | 3 | 1K |  |  |  | Resistor_SMD:R_0402_1005Metric | ~ | C11702
R4 | 1 | 33R |  |  |  | Resistor_SMD:R_0402_1005Metric | ~ | C25105
U1 | 1 | RP2350_60QFN |  |  |  | RP2350_60QFN_minimal:RP2350-QFN-60-1EP_7x7_P0.4mm_EP3.4x3.4mm_ThermalVias |  | C41378174
U3 | 1 | AP2112K-3.3 |  |  |  | Package_TO_SOT_SMD:SOT-23-5 |  | C51118
U4 | 1 | USBLC6-2P6 |  |  |  | Package_TO_SOT_SMD:SOT-666 | https://www.st.com/resource/en/datasheet/usblc6-2.pdf | C15999
Y1 | 1 | Crystal_GND24 |  |  |  | Crystal:Crystal_SMD_Abracon_ABM8G-4Pin_3.2x2.5mm | ~ | C20625731

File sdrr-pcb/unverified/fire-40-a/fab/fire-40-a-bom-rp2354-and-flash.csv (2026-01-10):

Reference | Qty | Value | DNP | Exclude from BOM | Exclude from Board | Footprint | Datasheet | LCSC
C1,C2,C3,C7,C13,C15 | 6 | 4.7uF |  |  |  | Capacitor_SMD:C_0402_1005Metric | ~ | C23733
C4,C5,C6,C8,C9,C10,C11,C12,C14,C20,C21,C22 | 12 | 0.1uF |  |  |  | Capacitor_SMD:C_0402_1005Metric | ~ | C1525
C16,C17 | 2 | 4.7uF |  |  |  | RP2350_60QFN_minimal:C_0402_1005Metric_small_pads | ~ | C23733
C18,C19 | 2 | 15pF |  |  |  | Capacitor_SMD:C_0402_1005Metric | ~ | C1548
D1 | 1 | LED_Small |  |  |  | LED_SMD:LED_0603_1608Metric | ~ | C2286
D2,D3 | 2 | 1N5819WS |  |  |  | Diode_SMD:D_SOD-323 |  | C191023
J1 | 1 | USB_C_Receptacle_USB2.0_16P |  |  |  | piers retro footprints:USB_C_connector_c2765186 | https://www.usb.org/sites/default/files/documents/usb_type-c.zip | C2765186
L1 | 1 | 3.3u |  |  |  | RP2350_60QFN_minimal:L_pol_2016 | ~ | C42411119
R1,R3,R7,R8 | 4 | 10K |  |  |  | Resistor_SMD:R_0402_1005Metric | ~ | C25744
R2,R5,R6 | 3 | 1K |  |  |  | Resistor_SMD:R_0402_1005Metric | ~ | C11702
R4 | 1 | 33R |  |  |  | Resistor_SMD:R_0402_1005Metric | ~ | C25105
R9,R10 | 2 | 5K1 |  |  |  | Resistor_SMD:R_0402_1005Metric | ~ | C25905
R12 | 1 | 0R |  |  |  | Resistor_SMD:R_0402_1005Metric | ~ | C17168
U1 | 1 | RP2354B |  |  |  | RP2350B:RP2350-QFN-80-1EP_10x10_P0.4mm_EP3.4x3.4mm_ThermalVias |  | C39843328
U3 | 1 | AP2112K-3.3 |  |  |  | Package_TO_SOT_SMD:SOT-23-5 |  | C51118
U4 | 1 | USBLC6-2P6 |  |  |  | Package_TO_SOT_SMD:SOT-666 | https://www.st.com/resource/en/datasheet/usblc6-2.pdf | C15999
U5 | 1 | W25Q16JVSS |  |  |  | Package_SON:Winbond_USON-8-1EP_3x2mm_P0.5mm_EP0.2x1.6mm | https://www.winbond.com/hq/support/documentation/levelOne.jsp?__locale=en&DocNo=DA00-W25Q16JV.1 | C2843335
Y1 | 1 | Crystal_GND24 |  |  |  | Crystal:Crystal_SMD_Abracon_ABM8G-4Pin_3.2x2.5mm | ~ | C20625731

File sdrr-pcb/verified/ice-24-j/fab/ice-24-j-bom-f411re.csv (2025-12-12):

Reference | Value | Datasheet | Footprint | Qty | DNP | LCSC | Comment
C1,C2,C3 | 4.7uF | ~ | Capacitor_SMD:C_0402_1005Metric | 3 |  | C23733 | Samsung Electro-Mechanics CL05A475MP5NRNC
C4,C5,C6,C7,C8 | 0.1uF | ~ | Capacitor_SMD:C_0402_1005Metric | 5 |  | C1525 | Samsung Electro-Mechanics CL05B104KO5NNNC
C9 | 4.7uF/DNP/DNP | ~ | Capacitor_SMD:C_0402_1005Metric | 1 |  | C23733 | Samsung Electro-Mechanics CL05A475MP5NRNC
C10,C11 | 33pF | ~ | Capacitor_SMD:C_0402_1005Metric | 2 |  | C1562 | Samsung Electro-Mechanics CL05B104KO5NNNC
D1 | LED_Small | ~ | LED_SMD:LED_0603_1608Metric | 1 |  | C2286
D2,D3 | 1N5819WS |  | Diode_SMD:D_SOD-323 | 2 |  | C191023
J6 | USB_B_Micro | ~ | piers global:USB_Micro-B_micro_xnj_073_C404969 | 1 |  | C404969
R1,R2 | 4K7 | ~ | Resistor_SMD:R_0402_1005Metric | 2 |  | C25900 | UNI-ROYAL(Uniroyal Elec) 0402WGF4701TCE
R3 | 1K | ~ | Resistor_SMD:R_0402_1005Metric | 1 |  | C11702 | UNI-ROYAL(Uniroyal Elec) 0402WGF1001TCE
R4 | 10K | ~ | Resistor_SMD:R_0402_1005Metric | 1 |  | C25744 | UNI-ROYAL(Uniroyal Elec) 0402WGF1002TCE
RC4,RC5 | 0R/4.7uF/DNP | ~ | Capacitor_SMD:C_0402_1005Metric | 2 |  | C17168 | UNI-ROYAL(Uniroyal Elec) 0402WGF0000TCE
U1 | STM32F411RET6 | https://www.st.com/resource/en/datasheet/stm32f411rc.pdf | Package_QFP:LQFP-64_10x10mm_P0.5mm | 1 |  | C94355
U3 | AP2112K-3.3 |  | Package_TO_SOT_SMD:SOT-23-5 | 1 |  | C51118
U4 | USBLC6-2P6 | https://www.st.com/resource/en/datasheet/usblc6-2.pdf | Package_TO_SOT_SMD:SOT-666 | 1 |  | C15999
Y1 | 12MHz | ~ | Crystal:Crystal_SMD_3225-4Pin_3.2x2.5mm | 1 |  | C9002

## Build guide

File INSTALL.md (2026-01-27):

# INSTALL

one-rom requires a fairly involved toolchain to build, due to the extend of the project (embedded firmware, desktop application, webassembly, etc).  This document covers installing the toolchain and dependencies on linux (primarily focusing on an x86_64 Debian-based distribution, although notes are also provided for an ARM64 based host).

Other hosts (Mac, Windows) are possible, and it is recommended to use macOS for building One ROM Studio for Mac, and Windows for building Windows installers.

However, we strongly recommend sticking to a *nix based host (Linux or macOS) for building the One ROM firmware itself, and instructions for settig up a full Windows build host are not included below.

You can choose to install the dependencies locally, or use the [Docker container](ci/docker/README.md) to build the One ROM firmware.

0. Install pre-requisites

    ```bash
    sudo apt -y install git build-essential curl pkg-config
    ```

1. Clone the repository:

    ```bash
    git clone https://github.com/piersfinlayson/one-rom.git
    cd one-rom
    ```

2. Install the required ARM GNU toolchain.  You have options here.

    - Install it [from ARM's website](https://developer.arm.com/downloads/-/arm-gnu-toolchain-downloads) for AArch32 bare-metal target (arm-none-eabi).

        Recommended approach - download the toolchain from ARM's developer site (this is quite large, so may take a while) - this is for x86_64 linux hosts::

        ```bash
        wget https://developer.arm.com/-/media/Files/downloads/gnu/14.3.rel1/binrel/arm-gnu-toolchain-14.3.rel1-x86_64-arm-none-eabi.tar.xz
        tar -xvf arm-gnu-toolchain-14.3.rel1-x86_64-arm-none-eabi.tar.xz
        sudo mv arm-gnu-toolchain-14.3.rel1-x86_64-arm-none-eabi /opt/
        ```

        If you are on ARM64 linux, or a Mac (Intel or ARM), select the correct version from ARM's site.  Again update TOOLCHAIN.

    - Install it via your package manager, e.g., on Debian/Ubuntu:

        ```bash
        sudo apt -y install gcc-arm-none-eabi
        ```

    Now you will need to update the `TOOLCHAIN` environment variable in your shell or variable in the [Makefile](sdrr/Makefile) to point to the correct compiler binary directory.  It should probably `/usr/bin` or `/opt/arm-gnu-toolchain-14.3.rel1-darwin-arm64-arm-none-eabi/bin` or similar.

    If on an ARM64 host you will also need x86_64-linux-gnu cross tools:

    ```bash
    sudo apt -y install gcc-x86-64-linux-gnu
    ```

3. Install the following packages required for building and testing.  Of these `vice` and `dfu-util` are optional.  (`vice` is used to build some Commodore demo programs, and `dfu-util` can be used for SWD programming Ice variants.):

    ```bash
    sudo apt -y install dfu-util jq libcurl4-openssl-dev libzip-dev libjson-c-dev libudev-dev vice
    ```

    If you are using a different package manager, the package name may vary slightly, e.g., `libcurl-devel` on Fedora.

    On macOS you would be using [Homebrew](https://brew.sh/).

4. Install [Rust](https://www.rust-lang.org/tools/install) - this will take a while:

    ```bash
    curl --proto '=https' --tlsv1.2 -sSf https://sh.rustup.rs | sh
    source $HOME/.cargo/env
    rustup target install thumbv7em-none-eabihf
    cargo install cross
    cargo install wasm-pack   # Only required to build one-rom-wasm
    cargo install cargo-dist  # Only required to build One ROM Studio installers
    ```

    If planning to build One ROM Studio for all possible targets (you likely only want to build a subset!) you will also need to install additional Rust targets and the mingw-w64 toolchain for Windows targets.  If you just want to build the One ROM firmware you do not need to do this step.
    
    ```bash
    rustup target install \
        x86_64-unknown-linux-gnu \
        aarch64-unknown-linux-gnu \
        x86_64-pc-windows-gnu \
        aarch64-pc-windows-gnullvm \
        x86_64-pc-windows-msvc \
        aarch64-pc-windows-msvc \
        x86_64-apple-darwin \
        aarch64-apple-darwin
    sudo apt -y install mingw-w64
    ```

5. Install [probe-rs](https://probe.rs/) for flashing the firmware to One ROM using an SWD programmer.  This is optional if you want to just build the firmware and use another tool to flash it.

    ```bash
    curl --proto '=https' --tlsv1.2 -LsSf https://github.com/probe-rs/probe-rs/releases/latest/download/probe-rs-tools-installer.sh | sh
    probe-rs complete install
    ```

6. Connect up One ROM to your [programmer](README.md#programmer).

At this point you can follow the instructions below to build and flash the firmware.

## Building the Firmware

To build the firmware, you use a command like this:

```bash
scripts/onerom.sh fire-24-d onerom-config/vic20-pal.json
```

To flash, use `-f`, to include regular and debug logging use `-l` and `-d` respectively.

You can also use make commands as described below, but running make directly has been deprecated in favour of the `scripts/onerom.sh` script.

## Programming the Firmware

### USB

USB is the simplest way to program One ROM if your hardware revision supports.

After building the firmware as above, use the binary from `sdrr/build/sdrr-{MCU}.bin` and one of the following tools to update the firmware of your device.  You have two official One ROM options:
- [One ROM Studio](https://onerom.org/studio)
- [One ROM Web](https://onerom.org/web)

If both cases, you need to select the option to upload a local firmware binary, and then program it.

You also have board specific, third-party, options:

#### Fire Boards

- [pico⚡flash](https://picoflash.org) - A web based RP2040/RP2350 flash by One ROM's author. 
- [picotool](https://github.com/raspberrypi/picotool) - A command line tool from Raspberry Pi for programming Raspberry Pi RP2040/RP2350-based boards.

As well as `sdrr/build/sdrr-rp2350.bin`, if you have [picotool](https://github.com/raspberrypi/picotool) installed and in your path, a UF2 file is created as part of the build for Fire boards at `sdrr/build/sdrr-rp2350.uf2`.

For a factory fresh Fire board, you can copy this UF2 to the RP2350 filesystem that mounts when you plug in the Fire board to program it.

Note that the RP2350 filesystem is not automatically mounted when plugged into USB once you have One ROM firmware v0.6.0+ installed, but you can access it by pulling BOOT to GND on power up to enter this mode.

#### Ice Boards

There are many third-arty options for programming Ice USB boards, which use STM32's DFU mode.

The author sometimes uses [dfu-util](http://dfu-util.sourceforge.net/).  As well as `sdrr/build/sdrr-stm32{MCU}.bin`, a DFU file is also created at `sdrr/build/sdrr-stm32{MCU}.dfu` which can be supplied directly to `dfu-util`.

You can even use the following to build and flash via dfu-util in one step:

```bash
XXX make dfu-flash
```

### SWD Programmer

Using SWD has an advantage over USB of being able to view debug logs from One ROM after re-programming.

However, you will need to find some way to power One ROM while programming, as, unlike USB, SWD does not provide power.  You can power One ROM by installing it in your retro system and powering that on, or by providing 5V and GND to the appropriate pins on One ROM directly.  ⚠️ If you are powering One ROM directly, **do not** install it in a retro system at the same time, as this may damage your One ROM, programmer, or retro system.

There are many tools that can be used to program One ROM via an SWD programmer.  We use [probe-rs](https://probe.rs/), which you may have installed already.

If you installed `probe-rs`, you can a command like this to build and flash the firmware using an SWD programmer in a single step - replace XXX with the appropriate build config for your hardware revision, MCU and ROM set configuration:

```bash
XXX make run
```

Note that as well as `sdrr/build/sdrr-{MCU}.bin`, an ELF file is created at `sdrr/build/sdrr-{MCU}.elf` which can be used with other SWD programming tools, as it contains build symbols.  This is particularly useful for attaching to One ROM with the programmer, after it has been programmed, to view logs. 

See [Pi-PICO-PROGRAMMER](/docs/PI-PICO-PROGRAMMER.md) for details of using a Raspberry Pi Pico as an inexpensive SWD programmer.  Many other SWD programmers are available, like the Raspberry Pi Debug Probe, generic DAPLink, ST-Link, etc. 

Occassionally your One ROM may lock up, particularly if you are experimenting with overclocking or other advanced configuration options, or debugging firmware changes.  If this is is the case, try rebooting your programmer, One ROM, or both, and try again.  If you still have problems, see [Recovering a Bricked Device](docs/GETTING-STARTED.md#recovering-a-bricked-device) for help.

## Additional Make Targets

To build and then review the contents of the firmware run:

```bash
XXX make info
XXX make info-detail # More details
```

To perform consistency checking on the firmware run the following:

```bash
XXX make test
```

Not all ROM types support this testing.  Please raise an issue if your specific ROM type fails this test.

## Debugging

To enable both high-level logging and debug logging, use the following when building:

```bash
BOOT_LOGGING=1 DEBUG_LOGGING=1 HW_REV=fire-24-d MCU=rp2350 CONFIG=config/vic20-pal.mk make
```

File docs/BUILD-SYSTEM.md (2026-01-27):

# One ROM Build System Explanation

The One ROM build system is a multi-stage pipeline that transforms ROM images and configuration into flashable STM32 firmware. This document explains how the build process works internally.

As of January 2026 it's a little out of date, but still a good high level overview of the key steps required to build One ROM firmware and flash it, for both Ice (STM32F4) and Fire (RP2350) variants.

## Build Pipeline Overview

```ascii
User Input → Top-level Make → sdrr-gen → sdrr Make → sdrr-info → test (optional) → probe-rs → STM32
    ↓              ↓            ↓          ↓             ↓              ↓              ↓        ↓
Config Files  ROM Download    Code Gen    Compile      Query      Compile tests      Flash    Running
ROM Images    & Validation    & Mangle    & Link      Firmware        & Run         Firmware
```

The build process involves six main components:

1. **Top-level Makefile** - Configuration processing and orchestration
2. **sdrr-gen** - Rust tool for ROM processing and generation of firmware code containing the ROMs
3. **sdrr Makefile** - STM32 ARM firmware compilation
4. **sdrr-info** - Validate the build firmware and extract its key properties
5. **test** - Optional tests to verify the generated "mangled" ROMs - `make test`
6. **probe-rs** - STM32 flashing and debugging

## Component Breakdown

### 1. Top-level Makefile ([`/Makefile`](/Makefile))

**Purpose**: Configuration management and build orchestration

**Key Responsibilities**:

- Parse configuration variables (e.g. STM variant, HW revision, ROM configs)
- Convert configuration into command-line arguments for sdrr-gen
- Coordinate the build pipeline stages
- Provide user-friendly error messages and warnings

**Configuration Processing**:

```bash
# User can override via config file or command line
CONFIG=old-config/c64.mk MCU=f411re make run

# Makefile processes ROM_CONFIGS like:
ROM_CONFIGS=file=kernel.rom,type=2364,cs1=0 file=basic.rom,type=2364,cs1=0

# Into sdrr-gen arguments:
--rom file=../kernel.rom,type=2364,cs1=0 --rom file=../basic.rom,type=2364,cs1=0
```

**Build Stages**:

1. `sdrr-gen` target - Build the Rust code generator
2. `gen` target - Run sdrr-gen to create firmware files
3. `firmware` target - Compile the STM32 firmware
4. `run` target - Flash to hardware via probe-rs

### 2. sdrr-gen (Rust Tool)

**Purpose**: ROM processing and firmware code generation

**Key Responsibilities**:

- Download ROM images from HTTP/HTTPS URLs
- Extract files from ZIP archives
- Validate ROM sizes against declared types
- "Mangle" ROM data to match PCB pin mapping
- Generate C source files with embedded ROM data
- Create Makefile fragments with build settings
- Create linker scripts for STM32 variant
- Handle license acceptance for ROM images

**ROM Processing Pipeline**:

Example for a `type=2364` ROM image:

```ascii
Original ROM → Size Validation → Pin Mapping → Flash Layout → C Arrays
      ↓                ↓              ↓             ↓             ↓
  8KB file      Must fit 2364      Rearrange     16KB blocks  static const
                  (8KB) type       for GPIO       in flash    uint8_t arrays
```

**Generated Files** (in [`/output/`](/output/) directory):

- `sdrr_config.h` - One ROM configuration constants
- `roms.c` - ROM data as C arrays
- `roms.h` - ROM declarations and types  
- `generated.mk` - Makefile fragment with STM32 variant information
- `linker.ld` - Linker script for the STM32 variant

### 3. sdrr Makefile ([`/sdrr/Makefile`](/sdrr/Makefile))

**Purpose**: ARM firmware compilation using GCC toolchain

**Key Responsibilities**:

- Compile C source files for target STM32 variant
- Link with SEGGER RTT library for logging output via RTT over SWD
- Include auto-generated ROM data from sdrr-gen
- Generate ELF, binary, and disassembly files

**Toolchain Setup**:

```makefile
TOOLCHAIN := /opt/arm-gnu-toolchain-14.3.rel1-x86_64-arm-none-eabi
CC := $(TOOLCHAIN)/bin/arm-none-eabi-gcc
OBJCOPY := $(TOOLCHAIN)/bin/arm-none-eabi-objcopy
```

**Source File Compilation**:

- `/sdrr/src/*.c` - Main firmware source
- `/sdrr/include/*.h` - Header files
- `/sdrr/link/stm32-common.ld` - Common linker script for all STM32 variants
- `/output/roms.c` - Generated ROM data
- `/output/roms.h` - Generated ROM data
- `/output/sdrr_config.h` - Generated One ROM configuration
- `/output/linker.ld` - Generated linker script for specific STM32 variant
- `/sdrr/segger-rtt/RTT/*.c` - Debug logging library (downloaded automatically by build process)

### 6. sdrr-info

**Purpose**: Validate the build firmware and extract its key properties

See [`sdrr-info`](/rust/sdrr-info/README.md) for details on how to use this tool.

### 5. Test (Optional)

**Purpose**: Validate the generated mangled ROM data, which is built into the firmware image

**Configuration**:

- ROM_CONFIGS as defined in the top-level Makefile

**Operation**:

The test program builds in the `sdrr-gen` auto-generated `roms.c` output, loads in the original ROM files, and does a byte-by-byte comparison by

- Choosing the next address
- Mangling the address, as it done in the real hardware
- Looking up the byte in the `roms.c` generated data
- Demangling the byte
- Comparing the byte with the original ROM file

This is a complex process when testing rom sets, as the appropriate chip select line(s) have to be activated.

### 6. probe-rs Integration

**Purpose**: Hardware flashing and debugging

**Configuration**:

- Chip ID passed via `generated.mk` (e.g., `STM32F411RETx`), generated by [`sdrr-gen`](#2-sdrr-gen-rust-tool).
- Automatic detection of connected programmers
- Support for ST-Link, Pi Debug Probe, Pi Pico, etc.

## Configuration System

### Variable Hierarchy

1. **Makefile defaults** - Safe baseline settings
2. **Config file** - Project-specific collections (e.g., `old-config/c64.mk`)
3. **Command line** - Override specific settings

### Key Configuration

See [`CONFIGURATION`](/docs/CONFIGURATION.md).

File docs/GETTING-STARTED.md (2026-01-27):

# Getting Started

## USB One ROMs

Most people will be getting started with a USB One ROM device, which can be programmed over USB.  You are recommended to use either:

- [One ROM Studio](https://onerom.org/studio) - a desktop application for Windows, macOS and Linux
- [One ROM Web](https://onerom.org/web) - a web tool for programming One ROM from your browser.

You only need to continue with this guide if you want to build the firmware yourself, or use an SWD programmer to program your One ROM device, or need to [unbrick a device](#recovering-a-bricked-device).

## Important

⚠️ **Do Not** power your One ROM device when it is installed in your retro system.

If the retro system is off or unplugged, this will cause your power supply and One ROM to attempt to power the entire 5V rail of your retro system, which may damage your One ROM, your retro system, your power supply or all of them.

You may program your One ROM when it is installed in your retro system, so long as it is powered on.  In this case **do not** provide external power.

## Hardware Identification

Each variant of the One ROM hardware has a unique revision ID printed on the PCB, and the boards have different numbers of breakout pins at the top of the PCB.

Identify your One ROM hardware version using the following image - in particular look for the revision ID, or match with the number of pins at the top of the PCB.

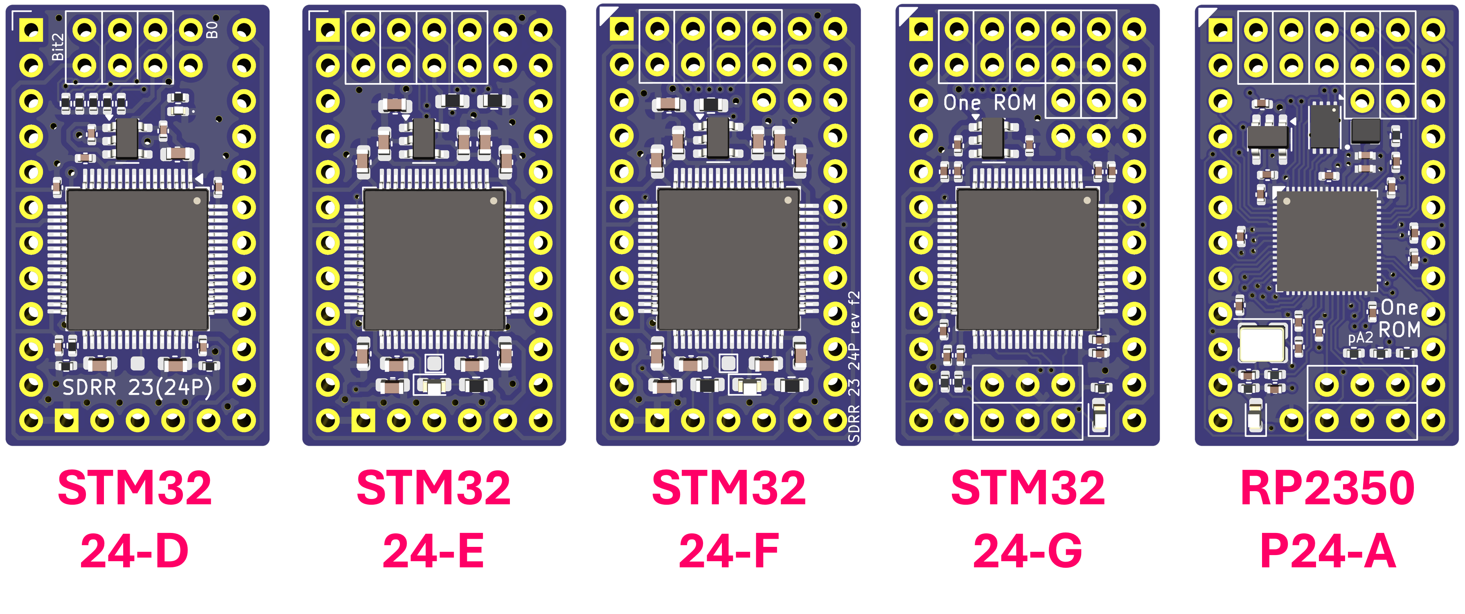
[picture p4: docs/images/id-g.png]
Identify your One ROM Hardware Version


## Pin 1

Pin 1 is marked on the PCB and the above image shows the board oriented so that pin 1 is at the top left.

⚠️ When installing One ROM in your retro system, always ensure the pin 1 is located correctly - you may damage your One ROM if you insert it incorrectly, as the power and ground pins will be connected with the wrong polarity.

## Installing the Dependencies

See [INSTALL.md](/INSTALL.md) for instructions on installing the required dependencies to build and flash the One ROM firmware.

## Programming One ROM

You need an SWD programmer to program the One ROM hardware.  The Raspberry Pi Debug Probe and a Raspberry Pi Pico programmed as a Debug Probe are suitable programmers.  An ST-Link or any other SWD programmer should also work.

You need to connect 3 cables from the SWD programmer to the One ROM:
- SWDIO (data)
- SWCLK (clock)
- GND (ground)

For the programming pins locations see:
- [STM32 Revisions 24-D/E/F Programming Pins](#stm32-revisions-24-def-programming-pins)
- [STM32 Rev G and RP2350 Rev A Programming Pins](#stm32-rev-g-and-rp2350-rev-a-programming-pins)

You also need to power the One ROM in order to program it.  This is most easily done by installing it in a retro system, and powering it on.

Alternatively, you can power the One ROM from a 5V power supply by connecting to the 5V and GND [pins that usually connect the One ROM to the retro system](#external-power):
- GND to pin 12 (bottom left)
- 5V to pin 24 (top right)

At present, when using the standard One ROM programming utility `probe-rs`, the RP2350 version must also be manually put into DFU/bootloader mode to be programmed, by shorting BOOT to GND when One ROM is powered on.  See the [Recovering a Bricked Device](#recovering-a-bricked-device) section for details.

Once connected, you can run the appropriate `make` command from the repository root to build and flash the firmware.

### Example `make` Commands

One ROM rev G, STM32F405RG MCU, serving the standard set of C64 images:

```bash
HW_REV=24-g MCU=f405rg CONFIG=old-config/c64.mk run
```

One ROM rev A, RP2350 MCU, serving the standard set of VIC20 PAL images:

```bash
HW_REV=p24-a MCU=rp2350 CONFIG=old-config/vic20-pal.mk run
```

There are lots of other build configurations possible - see:
- [Hardware Version Build Settings](#hardware-version-build-settings) for standard `HW_REV` and `MCU` settings
- [old-config](/old-config/README.md) for a list of standard ROM image configurations
- [Advanced Configuration](/docs/CONFIGURATION.md) for other configuration options.

### STM32 Revisions 24-D/E/F Programming Pins

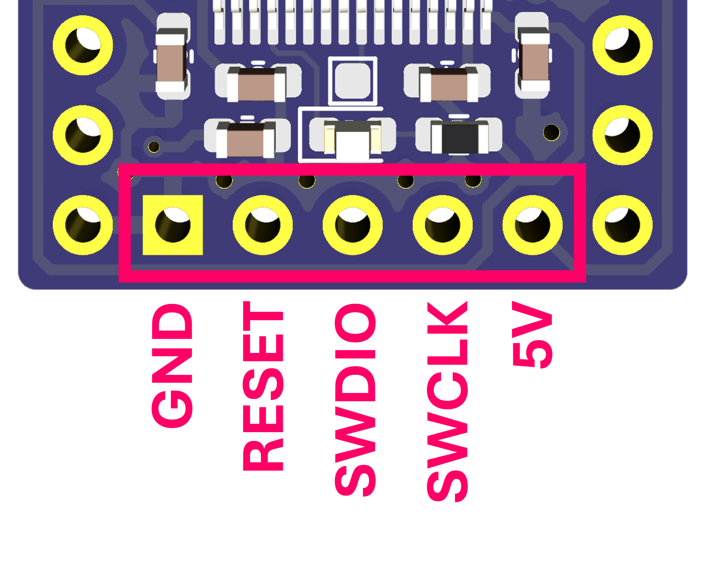
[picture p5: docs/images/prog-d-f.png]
Programming Pins for Revisions STM revs D/E/F


### STM32 Rev G and RP2350 Rev A Programming Pins

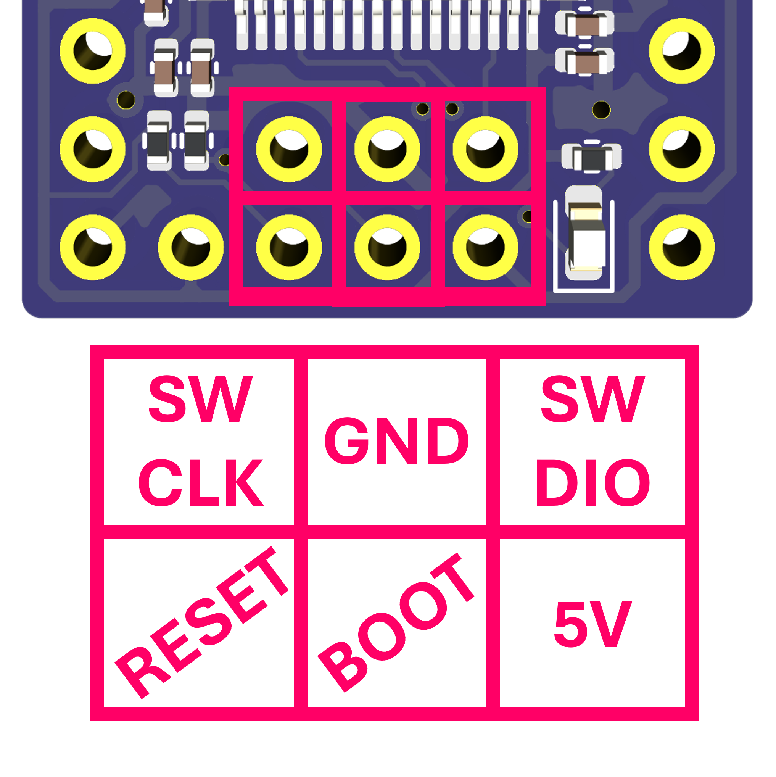
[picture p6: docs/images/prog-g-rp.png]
Programming Pins for Revisions STM rev G and RP rev A


### External Power

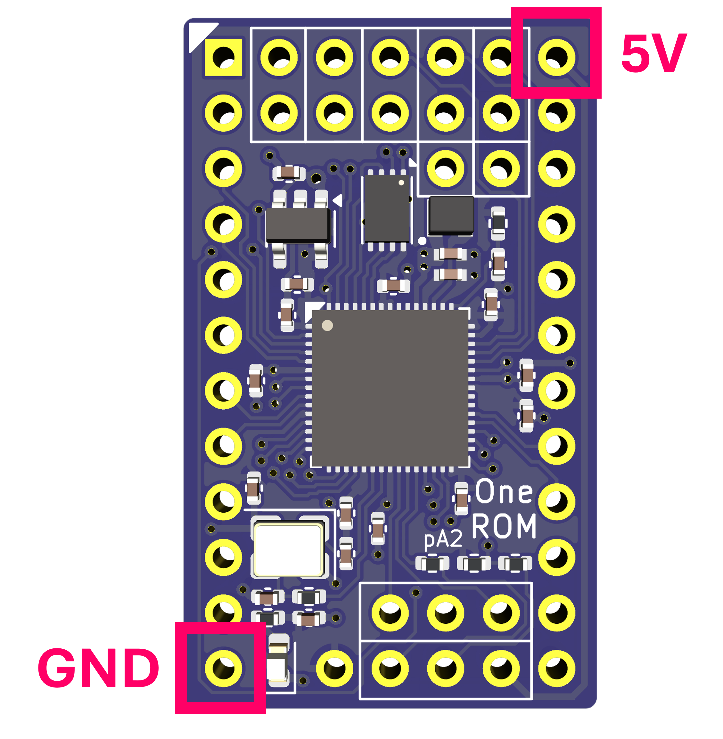
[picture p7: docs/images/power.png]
External Power Pins


## Image Selection

One ROM supports a number of different ROM images being installed at once, with those images being selected by using the One ROM jumpers.  One ROM reads these jumpers at boot time to detect which image to serve.  Using this mechanism, One ROM will not dynamically switch between images while the retro system is running - see [Bank Selection](#bank-selection) below for dynamic switching.

The image select jumpers are always found at the top of the One ROM PCB, and differerent hardware revisions have different numbers of supported jumpers.

The images below show which jumper indicates which bit of the image selection value.  If closed, the bit is a 1, if open, the bit is a 0.  Therefore to select:
- image 0, leave all jumpers open
- image 1, close the jumper marked 0
- image 2, close the jumper marked 1
- image 3, close the jumpers marked 1 and 0
- etc.

If you select an image number higher than the total number of images installed, One ROM will start counting again from image 0.  For example:
- if you have 1 image installed, it will always be selected
- if you have 2 images installed, only bit 0 will take effect
- if you have 3 images installed and close jumper bits 1 and 0, image 0 will be selected (3 modulo 3 = 0)

### STM32 Revision 24-D Image Selection Jumpers

Revision D has 3 image select jumpers, with the least significant bit on the left.

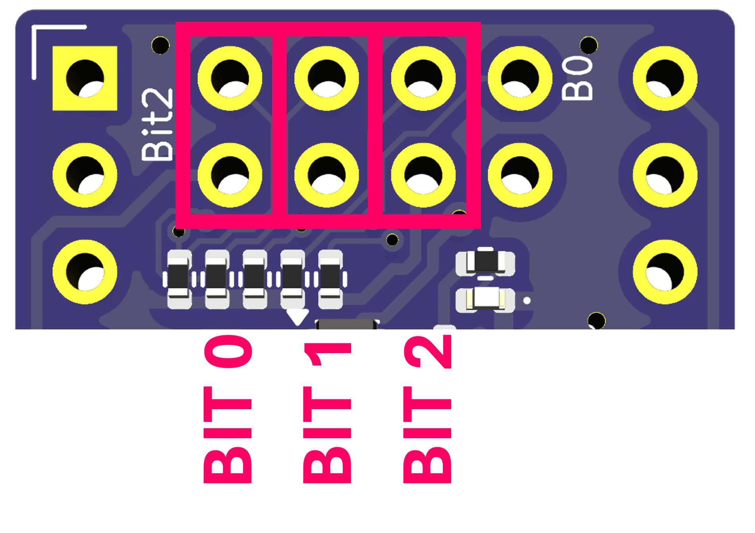
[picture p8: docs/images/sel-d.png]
Image Selection Jumpers for STM rev D


### STM32 Revisions 24-E/F Image Selection Jumpers

Revisions E and F have 4 image select jumpers, with the least significant bit on the left.

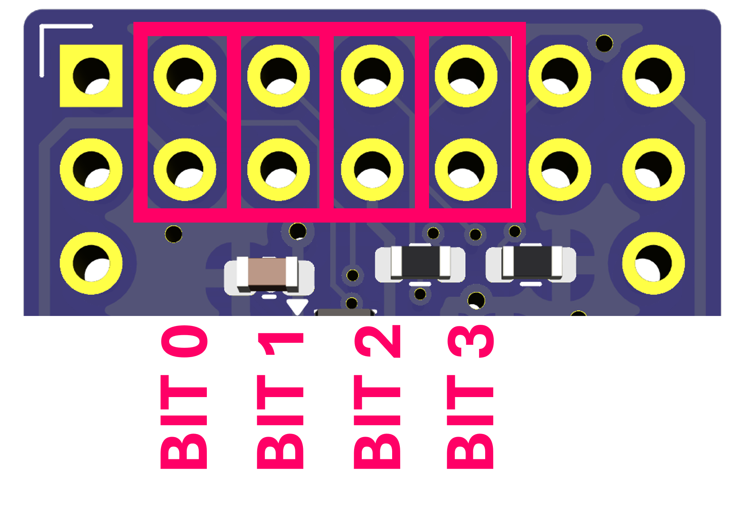
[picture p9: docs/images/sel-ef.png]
Image Selection Jumpers for STM revs E/F


### STM32 Revision 24-G/H Image Selection Jumpers

Revision G has 5 image select jumpers, with the least significant bit on the **right**.

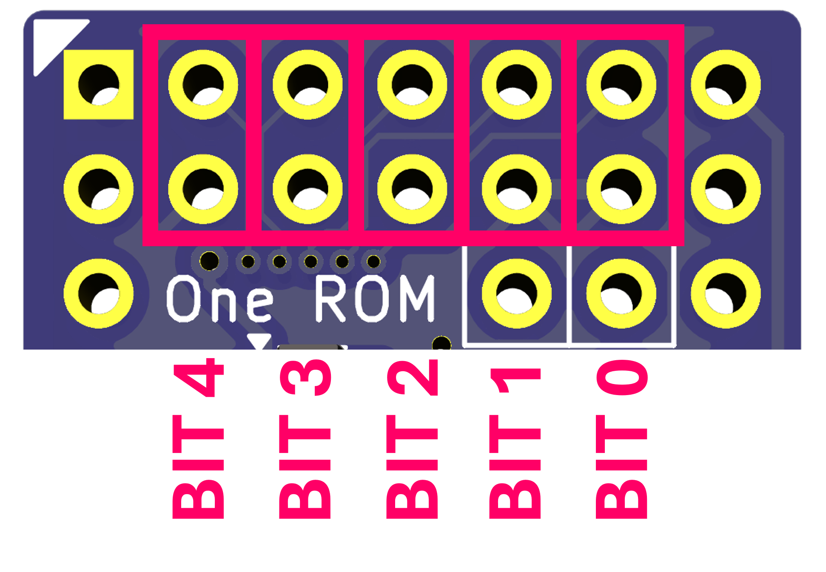
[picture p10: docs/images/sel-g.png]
Image Selection Jumpers for STM revs G/H


### RP2350 Revision A Image Selection Jumpers

Revision A has 3 image select jumpers, with the least significant bit on the **right**.

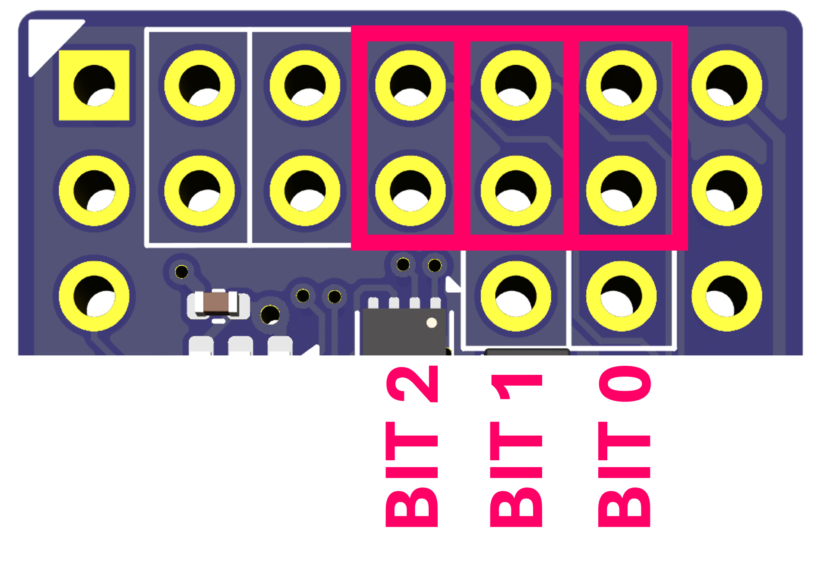
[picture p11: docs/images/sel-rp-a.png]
Image Selection Jumpers for RP rev A


## Bank Selection

When using [bank switched configurations](/docs/MULTI-ROM-SETS.md#dynamic-bank-switching-configuration) (those that start `bank-`), One ROM dynamically switches between images using the bank select jumpers X1 and X2.  These are always found at the top of the PCB.

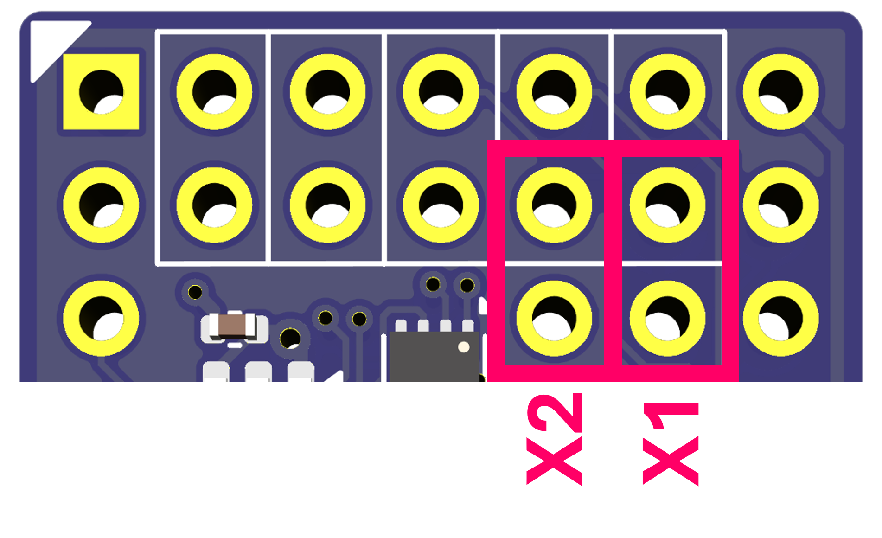
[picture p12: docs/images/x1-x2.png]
Bank Selection Jumpers


See the [Multi-ROM Sets](/docs/MULTI-ROM-SETS.md) documentation for more information on banks and multi-ROM sets.

## Multi-ROM Sets

When using [multi-ROM sets](/docs/MULTI-ROM-SETS.md#multi-rom-set-configuration) (those that start `set-`), One ROM serves ROM images up to 3 ROM sockets simultaneously, using pins X1 and X2 as extra chip select lines.  Connect flying leads from the X1 and X2 pins to the chip select pins of the other ROM sockets to be served.

Bank Selection Jumpers

See the [Multi-ROM Sets](/docs/MULTI-ROM-SETS.md) documentation for more information on banks and multi-ROM sets.

## Hardware Version Build Settings

When building the One ROM firmware you must identify the hardware version and the MCU type to the build system.  The following table lists the identifiers to use for each hardware version:

| PCB Revision ID | MCU | `HW_REV=` | Supported `MCU=` | `STATUS_LED=` |
|---|-----|---|---|---|
| D | STM32 | 24-d | f401rb/f401rc/f401re/f405rg/f411rc/f411re/f446rc/f446re | Not supported
| E | STM32 | 24-e | f401rb/f401rc/f401re/f405rg/f411rc/f411re/f446rc/f446re | 0/1 |
| F/F2 | STM32 | 24-f | f401rb/f401rc/f401re/f405rg/f411rc/f411re/f446rc/f446re | 0/1 |
| G | STM32 | 24-g | f401rb/f401rc/f401re/f405rg/f411rc/f411re/f446rc/f446re | 0/1 |
| A | RP2350 | p24-a | rp2350 | 0/1 |

## Recovering a Bricked Device

If your programmer will not connect to your One ROM device, or you have accidentally flashed incorrect firmware, you may have bricked your device and need to recover the device by forcing it into DFU/bootloader mode and then programming it using your SWD programmer as normal.

To enter DFU/bootloader mode, you must set the BOOT0 (or BOOT on RP2350) pin to the correct level, and then reset the device, either by power cycling, or briefly pulling the RESET/RUN pin low.

### STM32

On revisions D, E, and F, BOOT0 and 3.3V are exposed at the top right of the board as shown - short the two indicated pins together to pull BOOT0 high.

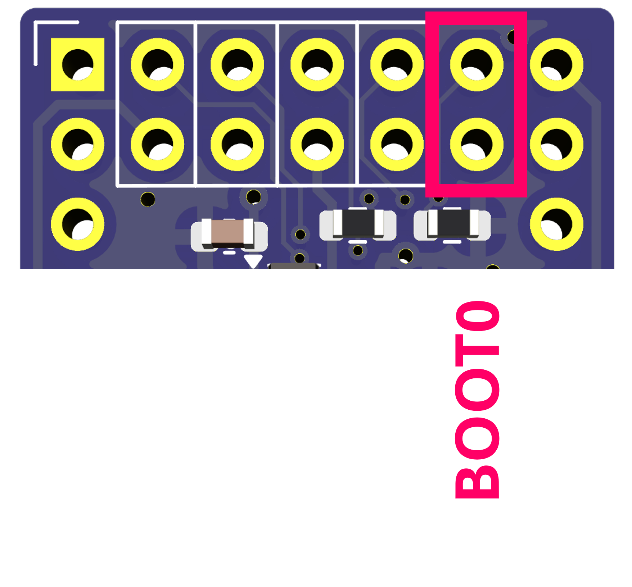
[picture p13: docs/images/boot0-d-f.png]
BOOT0 Pin Location - STM revs D/E/F


On revision G, BOOT0 and 3.3V are exposed at the bottom of the board as part of the programming pins, as shown.  Short the two indicated pins together to pull BOOT0 high.

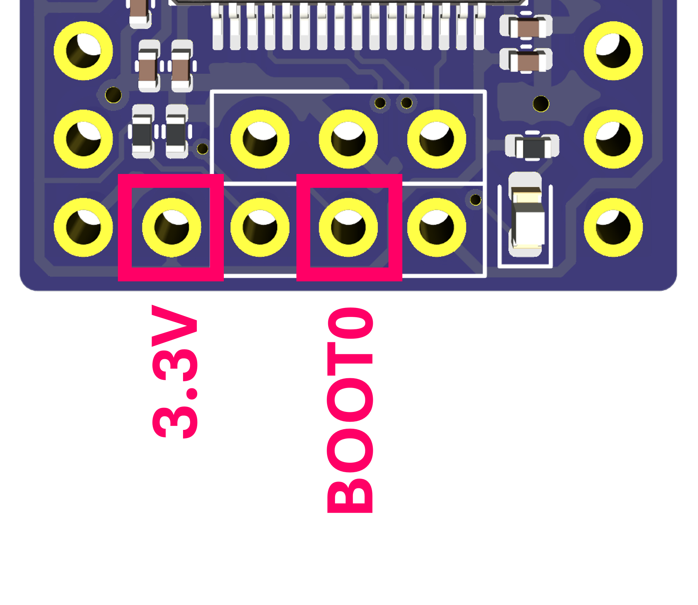
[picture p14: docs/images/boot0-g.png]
BOOT0 Pin Location - STM rev G


## RP2350

On the RP2350 BOOT must be pulled to GND, while resetting the device, to enter DFU/bootloader mode.  Short the two indicated pins together to pull BOOT low.

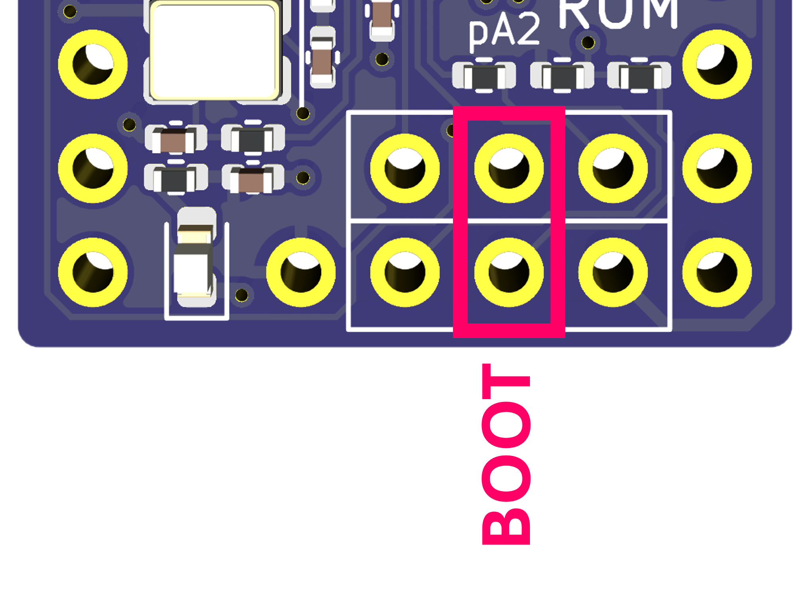
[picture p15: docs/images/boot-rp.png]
BOOT Pin Location - RP rev A


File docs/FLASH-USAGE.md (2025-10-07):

# Flash Usage

Prior to v0.5.0 the One ROM firmware, the ROM image metadata, and the ROM images themselves where all built into a single monolothic binary, which was flashed to the base of the flash.

As of v0.5.0 One ROM's flash usage was modified in to separate the firmware, the ROM image metadata, and the ROM images themselves, so that they could be erased and updated independently.  This change slightly reduces the available flash space for ROM images, but improved the reliability of reprogramming One ROM, allowing just ROM metadata and images to be updated in the normal case, hence reducing the changes of a bricking event, that would require tedious recovery.  This is also faster, as it requires erasing and reprogramming a smaller section of flash.

The new flash layout is as follows, with all addresses relative to the flash base address, which varies between the STM32 (0x08000000) and RP2350 (0x10000000):

```ascii
+---------------------+ 0x00000000
| One ROM Firmware    |
+---------------------+ 0x0000C000
| One ROM Metadata    |
+---------------------+ 0x00010000
| ROM Images          |
+---------------------+ 16/64KB boundary
```

The first 48KB of flash is reserved for the One ROM firmware.  This includes the startup code, the main byte serving algorithm and USB handling code.

The next 16KB of flash is reserved for the ROM metadata, including the number of images, and the metadata associated with each image.

Address 64KB onwards is used by ROM images.  These are varying lengths - either 16KB or 64KB, depending on the MCU and image type:

- Fire/RP2350 - images are always 64KB.
- Ice/STM32F4 - images are either 16KB (single ROM image), or 64KB (banked switch or multi-ROM set).

ROM images are always stacked next to each other, with no gaps, and a pointer to the image (as well as its length) is stored in the metadata for this ROM.

This structure means a complete firmware + metadata + images binary file is always a multiple of 16KB on STM32, and always a 64KB multiple on the RP2350.

This layout is chosen to align with both STM32F4 and RP2350 flash sector sizes - that is the minimum size which can be erased at once.

The STM32F4's sector sizes are:

- 16KB for the first 4 sectors (0x0000 - 0x3FFF)
- 64KB for the 5th sector (0x4000 - 0xFFFF)
- 128KB for sectors 6-11 (0x10000 - 0x1FFFFF)

The RP2350's sector sizes are expected to be 4KB, although this does depends on the exact flash chip used.  The stock One ROM hardware uses Winbond W25Q16JV, which has 4KB sectors.

Hence, to erase and reflash the firmware:

- On the STM32F4, sectors 0-2 are erased (0x0000 - 0x2FFF)
- On the RP2350, sectors 0-11 are erased (0x0000 - 0x2FFF)

To modify the ROM images, the metadata and all ROM images must be erased, but the firmware can be left intact. Hence means leaving sectors 0-2 (STM32F4) or 0-11 (RP2350) intact, and erasing and re-programming the others.

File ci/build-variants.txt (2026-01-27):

# Build option variants to build
# Add new variants here, one per line
# Lines starting with # are ignored

# Fire rev A
rp2350:HW_REV=fire-24-a

# Fire rev B
rp2350:HW_REV=fire-24-usb-b

# Fire 24 rev C
rp2350:HW_REV=fire-24-c

# Fire 24 rev D
rp2350:HW_REV=fire-24-d

# Fire 24 rev E
rp2350:HW_REV=fire-24-e

# Fire 28 rev A
rp2350:HW_REV=fire-28-a

# Ice rev F
f401re:HW_REV=ice-24-f
f411re:HW_REV=ice-24-f
f405rg:HW_REV=ice-24-f
f446re:HW_REV=ice-24-f

# Ice rev G
f401re:HW_REV=ice-24-g
f411re:HW_REV=ice-24-g
f405rg:HW_REV=ice-24-g
f446re:HW_REV=ice-24-g

# Ice rev H
f401re:HW_REV=ice-24-usb-h
f411re:HW_REV=ice-24-usb-h
f405rg:HW_REV=ice-24-usb-h
f446re:HW_REV=ice-24-usb-h

# Ice rev I
f401re:HW_REV=ice-24-i
f411re:HW_REV=ice-24-i
f405rg:HW_REV=ice-24-i
f446re:HW_REV=ice-24-i

# Ice rev J
f401re:HW_REV=ice-24-j
f411re:HW_REV=ice-24-j
f405rg:HW_REV=ice-24-j
f446re:HW_REV=ice-24-j

# Ice 28 rev a
f401re:HW_REV=ice-28-a
f411re:HW_REV=ice-28-a
f405rg:HW_REV=ice-28-a
f446re:HW_REV=ice-28-a

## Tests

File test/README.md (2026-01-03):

# roms-test

This is a test suite for the `roms.c` output from `sdrr-gen`, verifying that the generated images and data are correct - that is, they are properly mangled in the way that the STM32F4 expects (based on the STM32F4 wiring to the address, data and CS lines).

## Usage

The best way to execute this test suite is to run `make test` from the root directory of the repository.  Pass in whatever environment variables are being using to build your firmware.  For example:

```bash
HW_REV=24-f CONFIG=config/set-c64.mk make test
```

## Details

This

- builds the firmware
- builds the test suite with the same auto-generated `roms.c` file
- test that against the original ROM files.

These tests have an external dependency on `libcurl` and `libzip` which are used to retrieve any ROM files specified with URLs (as opposed to local files), and extract the appropriate file, if in an archive.

```bash
sudo apt install libcurl4-openssl-dev libzip-dev libjson-c-dev
```

On macOS with Homebrew:

```bash
brew install curl libzip json-c
```

Note that this test suite does _not_ yet use the pin mapping from [`rust/config/json`](/rust/config/json/README.md), so will report errors for hardware revisions other than `24-d`, `24-e` and `24-f`.

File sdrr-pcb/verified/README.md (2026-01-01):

# Verified PCB Revisions

This folder contains design and manufacturing files for verified revisions of the One ROM PCB.

These revisions have been tested and confirmed to work with specific MCU microcontroller variants and are supported by the stock One ROM firmware using the `HW_REV` field in the top-level [Makefile](/Makefile).

See the [sdrr-pcb README](../README.md) for recommended revisions.

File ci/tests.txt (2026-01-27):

# Test combinations for build system validation
# Format: test_name:MCU=variant,VAR1=val1,VAR2=val2,CONFIG=old-config/file.mk
# Lines starting with # are ignored
#
# MCU variant is required for each test
# CONFIG is optional - if not specified, no config is passed to make
# Other environment variables are optional

# All variants without config (uses Makefile default)
no-config-f401rb:HW_REV=ice-24-f,MCU=f401rb
no-config-f401rc:HW_REV=ice-24-f,MCU=f401rc
no-config-f411rc:HW_REV=ice-24-f,MCU=f411rc
no-config-f411re:HW_REV=ice-24-f,MCU=f411re
no-config-f405rg:HW_REV=ice-24-f,MCU=f405rg
no-config-f405rg:HW_REV=ice-24-f,MCU=f446rc
no-config-f446re:HW_REV=ice-24-f,MCU=f446re
no-config-rp2350-24a:HW_REV=fire-24-a,MCU=rp2350
no-config-rp2350-24b:HW_REV=fire-24-usb-b,MCU=rp2350
no-config-rp2350-24c:HW_REV=fire-24-c,MCU=rp2350
no-config-rp2350-24d:HW_REV=fire-24-d,MCU=rp2350
no-config-rp2350-24e:HW_REV=fire-24-e,MCU=rp2350

# Use test config, one of each STM32F4 variant
basic-f401rc:HW_REV=ice-24-f,MCU=f401rc,CONFIG=old-config/test-sdrr-0.mk
basic-f411re:HW_REV=ice-24-f,MCU=f411re,CONFIG=old-config/test-sdrr-0.mk
basic-f405rg:HW_REV=ice-24-f,MCU=f405rg,CONFIG=old-config/test-sdrr-0.mk
basic-f446re:HW_REV=ice-24-f,MCU=f446re,CONFIG=old-config/test-sdrr-0.mk

# Enable MCO, one of each STM32F4 variant
mco-f401re:HW_REV=ice-24-f,MCO=1,MCU=f401re,CONFIG=old-config/test-sdrr-0.mk
mco-f411re:HW_REV=ice-24-f,MCO=1,MCU=f411re,CONFIG=old-config/test-sdrr-0.mk
mco-f405rg:HW_REV=ice-24-f,MCO=1,MCU=f405rg,CONFIG=old-config/test-sdrr-0.mk
mco-f446re:HW_REV=ice-24-f,MCO=1,MCU=f446re,CONFIG=old-config/test-sdrr-0.mk

# Disable BOOT_LOGGGING
no-boot-logging-f411re:HW_REV=ice-24-f,BOOT_LOGGING=0,MCU=f411re,CONFIG=old-config/test-sdrr-0.mk
no-boot-logging-rp2350:HW_REV=fire-24-a,BOOT_LOGGING=0,MCU=rp2350,CONFIG=old-config/test-sdrr-0.mk
no-boot-logging-rp2350:HW_REV=fire-24-usb-b,BOOT_LOGGING=0,MCU=rp2350,CONFIG=old-config/test-sdrr-0.mk

# Disable BOOT_LOGGGING and SWD
no-boot-logging-no-swd-f401re:HW_REV=ice-24-f,BOOT_LOGGING=0,SWD=0,MCU=f401re,CONFIG=old-config/test-sdrr-0.mk

# PCB revisions
pcb-rev-d:HW_REV=ice-24-d,STATUS_LED=0,MCU=f401re,CONFIG=old-config/test-sdrr-0.mk
pcb-rev-e:HW_REV=ice-24-e,MCU=f401re,CONFIG=old-config/test-sdrr-0.mk
pcb-rev-f:HW_REV=ice-24-f,MCU=f401re,CONFIG=old-config/test-sdrr-0.mk
pcb-rev-g:HW_REV=ice-24-g,MCU=f401re,CONFIG=old-config/test-sdrr-0.mk
pcb-rev-h:HW_REV=ice-24-usb-h,MCU=f401re,CONFIG=old-config/test-sdrr-0.mk
pcb-rev-i:HW_REV=ice-24-i,MCU=f401re,CONFIG=old-config/test-sdrr-0.mk
pcb-rev-j:HW_REV=ice-24-j,MCU=f401re,CONFIG=old-config/test-sdrr-0.mk
pcb-rev-pa:HW_REV=fire-24-a,MCU=rp2350,CONFIG=old-config/test-sdrr-0.mk
pcb-rev-pb:HW_REV=fire-24-usb-b,MCU=rp2350,CONFIG=old-config/test-sdrr-0.mk
pcb-rev-pc:HW_REV=fire-24-c,MCU=rp2350,CONFIG=old-config/test-sdrr-0.mk
pcb-rev-pd:HW_REV=fire-24-d,MCU=rp2350,CONFIG=old-config/test-sdrr-0.mk
pcb-rev-pe:HW_REV=fire-24-e,MCU=rp2350,CONFIG=old-config/test-sdrr-0.mk

# Enable BOOT_LOGGGING
boot-logging-f401re:HW_REV=ice-24-f,BOOT_LOGGING=1,MCU=f401re,CONFIG=old-config/test-sdrr-0.mk
boot-logging-rp2350:HW_REV=fire-24-a,BOOT_LOGGING=1,MCU=rp2350,CONFIG=old-config/test-sdrr-0.mk

# Enable DEBUG_LOGGING
debug-logging-f401re:HW_REV=ice-24-f,DEBUG_LOGGING=1,BOOT_LOGGING=1,MCU=f401re,CONFIG=old-config/test-sdrr-0.mk
debug-logging-rp2350:HW_REV=fire-24-a,DEBUG_LOGGING=1,BOOT_LOGGING=1,MCU=rp2350,CONFIG=old-config/test-sdrr-0.mk

# Enable MAIN_LOOP_LOGGING
main-loop-logging-f401re:HW_REV=ice-24-f,MAIN_LOOP_LOGGING=1,BOOT_LOGGING=1,MCU=f401re,CONFIG=old-config/test-sdrr-0.mk
main-loop-logging-rp2350:HW_REV=fire-24-a,MAIN_LOOP_LOGGING=1,BOOT_LOGGING=1,MCU=rp2350,CONFIG=old-config/test-sdrr-0.mk

# Enable MAIN_LOOP_ONE_SHOT
main-loop-one-shot-f401re:HW_REV=ice-24-f,MAIN_LOOP_ONE_SHOT=1,MAIN_LOOP_LOGGING=1,BOOT_LOGGING=1,MCU=f401re,CONFIG=old-config/test-sdrr-0.mk
main-loop-one-shot-debug-f401re:HW_REV=ice-24-f,DEBUG_LOGGING=1,MAIN_LOOP_ONE_SHOT=1,MAIN_LOOP_LOGGING=1,BOOT_LOGGING=1,MCU=f401re,CONFIG=old-config/test-sdrr-0.mk
main-loop-one-shot-rp2350:HW_REV=fire-24-a,MAIN_LOOP_ONE_SHOT=1,MAIN_LOOP_LOGGING=1,BOOT_LOGGING=1,MCU=rp2350,CONFIG=old-config/test-sdrr-0.mk
main-loop-one-shot-debug-rp2350:HW_REV=fire-24-a,DEBUG_LOGGING=1,MAIN_LOOP_ONE_SHOT=1,MAIN_LOOP_LOGGING=1,BOOT_LOGGING=1,MCU=rp2350,CONFIG=old-config/test-sdrr-0.mk

# DISABLE_PRELOAD_TO_RAM
disable-preload-to-ram-f401re:HW_REV=ice-24-f,DISABLE_PRELOAD_TO_RAM=1,MCU=f401re,CONFIG=old-config/test-sdrr-0.mk
disable-preload-to-ram-rp2350:HW_REV=fire-24-a,DISABLE_PRELOAD_TO_RAM=1,MCU=rp2350,CONFIG=old-config/test-sdrr-0.mk

# Disable status LED
disable-status-led-f401re:HW_REV=ice-24-e,DISABLE_STATUS_LED=1,MCU=f401re,CONFIG=old-config/test-sdrr-0.mk
disable-status-led-rp2350:HW_REV=fire-24-a,DISABLE_STATUS_LED=1,MCU=rp2350,CONFIG=old-config/test-sdrr-0.mk

# Custom frequencies
freq-50mhz-f401re:HW_REV=ice-24-f,FREQ=50,MCU=f401re,CONFIG=old-config/test-sdrr-0.mk
freq-92mhz-f411re:HW_REV=ice-24-f,FREQ=92,MCU=f411re,CONFIG=old-config/test-sdrr-0.mk
freq-130mhz-f405rg:HW_REV=ice-24-f,FREQ=130,MCU=f405rg,CONFIG=old-config/test-sdrr-0.mk
freq-170mhz-f446re:HW_REV=ice-24-f,FREQ=160,MCU=f446re,CONFIG=old-config/test-sdrr-0.mk
freq-100mhz-rp2350:HW_REV=fire-24-a,FREQ=100,MCU=rp2350,CONFIG=old-config/test-sdrr-0.mk

# Overclocking
overclock-f401re:HW_REV=ice-24-f,OVERCLOCK=1,FREQ=100,MCU=f401re,CONFIG=old-config/test-sdrr-0.mk
overclock-f411re:HW_REV=ice-24-f,OVERCLOCK=1,FREQ=110,MCU=f411re,CONFIG=old-config/test-sdrr-0.mk
overclock-f405rg:HW_REV=ice-24-f,OVERCLOCK=1,FREQ=250,MCU=f405rg,CONFIG=old-config/test-sdrr-0.mk
overclock-f446re:HW_REV=ice-24-f,OVERCLOCK=1,FREQ=400,MCU=f446re,CONFIG=old-config/test-sdrr-0.mk
overclock-rp2350:HW_REV=fire-24-a,OVERCLOCK=1,FREQ=300,MCU=rp2350,CONFIG=old-config/test-sdrr-0.mk

# Build with different serve algorithms
serve-algorithm-a-f401re:HW_REV=ice-24-f,SERVE_ALG=a,MCU=f401re,CONFIG=old-config/test-sdrr-0.mk
serve-algorithm-b-f401re:HW_REV=ice-24-f,SERVE_ALG=b,MCU=f401re,CONFIG=old-config/test-sdrr-0.mk

# Build with c main loop - not supported in production, but want to keep compiling
c-main-loop-f405rg:HW_REV=ice-24-f,EXTRA_C_FLAGS=-DC_MAIN_LOOP,COUNT_ROM_ACCESS=0,MCU=f405rg,CONFIG=old-config/bank-1541.mk

# Build without COUNT_ROM_ACCESS
no-count-rom-access-f401re:HW_REV=ice-24-f,COUNT_ROM_ACCESS=0,MCU=f401re,CONFIG=old-config/test-sdrr-0.mk

# Build with DISABLE_CCM
disable-ccm-f405rg:HW_REV=ice-24-f,EXTRA_C_FLAGS=-DDISABLE_CCM,MCU=f405rg,CONFIG=old-config/test-sdrr-0.mk

# Test each config (except those requiring licenses and not sets)
test-1541-f411re:HW_REV=ice-24-f,MCU=f401re,CONFIG=old-config/1541.mk
test-2040-f411re:HW_REV=ice-24-f,MCU=f411re,CONFIG=old-config/2040.mk
test-4040-f411re:HW_REV=ice-24-f,MCU=f411re,CONFIG=old-config/4040.mk
test-c64-no-destestmax-f411re:HW_REV=ice-24-f,MCU=f411re,CONFIG=old-config/c64-no-destestmax.mk
test-ieee-diag-f411re:HW_REV=ice-24-f,MCU=f411re,CONFIG=old-config/ieee-diag.mk
test-pet-4-40-50-f411re:HW_REV=ice-24-f,MCU=f411re,CONFIG=old-config/pet-4-40-50.mk
test-vic20-pal-f411re:HW_REV=ice-24-f,MCU=f411re,CONFIG=old-config/vic20-pal.mk
test-vic20-ntsc-rp2350:HW_REV=fire-24-a,MCU=rp2350,CONFIG=old-config/vic20-ntsc.mk
test-vic20-ntsc-rp2350:HW_REV=fire-24-usb-b,MCU=rp2350,CONFIG=old-config/vic20-ntsc.mk

# Test old config set letters
test-hw-rev-D:HW_REV=d,STATUS_LED=0,MCU=f411re,CONFIG=old-config/test-sdrr-0.mk
test-hw-rev-E:HW_REV=e,MCU=f411re,CONFIG=old-config/test-sdrr-0.mk
test-hw-rev-F:HW_REV=f,MCU=f411re,CONFIG=old-config/test-sdrr-0.mk

# Test each set config - HW_REV=ice-24-f only
test-set-c64-f411re:HW_REV=ice-24-f,MCU=f411re,CONFIG=old-config/set-c64.mk
test-set-vic20-pal-rp2350:HW_REV=fire-24-a,MCU=rp2350,CONFIG=old-config/set-vic20-pal.mk

# Test each bank switching config
bank-1541-f405rg:MCU=f405rg,HW_REV=f,CONFIG=old-config/bank-1541.mk
bank-c64-char-f405rg:MCU=f405rg,HW_REV=f,CONFIG=old-config/bank-c64-char.mk
bank-vic20-char-f405rg:MCU=f405rg,HW_REV=f,CONFIG=old-config/bank-vic20-char.mk
bank-c64-char-fun-f405rg:MCU=f405rg,HW_REV=f,CONFIG=old-config/bank-c64-char-fun.mk
bank-vic20-char-fun-f405rg:HW_REV=fire-24-a,MCU=rp2350,CONFIG=old-config/bank-vic20-char-fun.mk

# Test RP2350 GPIO coprocessor support
rp-use-cp-rp2350:EXTRA_C_FLAGS=-DRP_USE_CP=1,MCU=rp2350,HW_REV=fire-24-a,CONFIG=old-config/test-sdrr-0.mk

# Build with EXCLUDE_METADATA (no metadata or ROM images included in firmware)
exclude-metadata-f401re:HW_REV=ice-24-f,EXCLUDE_METADATA=1,MCU=f401re,CONFIG=old-config/test-sdrr-0.mk
exclude-metadata-rp2350:HW_REV=fire-24-a,EXCLUDE_METADATA=1,MCU=rp2350,CONFIG=old-config/test-sdrr-0.mk

# PIO tests
pio-1:EXTRA_C_FLAGS="-DRP_PIO -DPIO_CONFIG_DEFAULT",HW_REV=fire-24-a,MCU=rp2350,CONFIG=old-config/c64-no-destestmax.mk

# 24 pin 27 series ROM tests
ice-2716:HW_REV=ice-24-usb-h,MCU=f411re,ROM_CONFIGS="file=images/test/rand_8192.rom,trunc,type=2716"
ice-2732:HW_REV=ice-24-usb-h,MCU=f411re,ROM_CONFIGS="file=images/test/rand_8192.rom,trunc,type=2732"
fire-2716:HW_REV=fire-24-a,MCU=rp2350,ROM_CONFIGS="file=images/test/rand_8192.rom,trunc,type=2716"
fire-2732:HW_REV=fire-24-a,MCU=rp2350,ROM_CONFIGS="file=images/test/rand_8192.rom,trunc,type=2732"
fire-2716-pio:HW_REV=fire-24-d,MCU=rp2350,ROM_CONFIGS="file=images/test/rand_8192.rom,trunc,type=2716"
fire-2732-pio:HW_REV=fire-24-a,MCU=rp2350,ROM_CONFIGS="file=images/test/rand_8192.rom,trunc,type=2732"

# 28 pin 27 series ROM tests
# Ice tests are broken - it's probaby a test script issue, but we have deprecated ice-28-a boards anyway
#ice-2764:HW_REV=ice-28-a,MCU=f446re,ROM_CONFIGS="file=images/test/rand_8192.rom,type=2764"
#ice-27128:HW_REV=ice-28-a,MCU=f446re,ROM_CONFIGS="file=images/test/rand_65536.rom,trunc,type=27128"
#ice-27256:HW_REV=ice-28-a,MCU=f446re,ROM_CONFIGS="file=images/test/rand_65536.rom,trunc,type=27256"
#ice-27512:HW_REV=ice-28-a,MCU=f446re,ROM_CONFIGS="file=images/test/rand_65536.rom,trunc,type=27512"
fire-2764:HW_REV=fire-28-a,MCU=rp2350,ROM_CONFIGS="file=images/test/rand_65536.rom,trunc,type=2764"
fire-27128:HW_REV=fire-28-a,MCU=rp2350,ROM_CONFIGS="file=images/test/rand_65536.rom,trunc,type=27128"
fire-27256:HW_REV=fire-28-a,MCU=rp2350,ROM_CONFIGS="file=images/test/rand_65536.rom,trunc,type=27256"
fire-27512:HW_REV=fire-28-a,MCU=rp2350,ROM_CONFIGS="file=images/test/rand_65536.rom,type=27512"

## 28 pin 23 series ROM tests
# Ice tests are broken - it's probaby a test script issue, but we have deprecated ice-28-a boards anyway
#ice-23128:HW_REV=ice-28-a,MCU=f446re,ROM_CONFIGS="file=images/test/rand_65536.rom,trunc,type=23128,cs1=0,cs2=1,cs3=1"
#ice-23256:HW_REV=ice-28-a,MCU=f446re,ROM_CONFIGS="file=images/test/rand_65536.rom,trunc,type=23256,cs1=0,cs2=1"
#ice-23512:HW_REV=ice-28-a,MCU=f446re,ROM_CONFIGS="file=images/test/rand_65536.rom,trunc,type=23512,cs1=0,cs2=1"
fire-28-a-c64c:HW_REV=fire-28-a,MCU=rp2350,CONFIG=old-config/28-c64c.mk
fire-28-a-c1541ii:HW_REV=fire-28-a,MCU=rp2350,CONFIG=old-config/28-1541ii.mk
fire-23128:HW_REV=fire-28-a,MCU=rp2350,ROM_CONFIGS="file=images/test/rand_65536.rom,trunc,type=23128,cs1=0,cs2=1,cs3=1"
fire-23256:HW_REV=fire-28-a,MCU=rp2350,ROM_CONFIGS="file=images/test/rand_65536.rom,trunc,type=23256,cs1=0,cs2=1"
fire-23512:HW_REV=fire-28-a,MCU=rp2350,ROM_CONFIGS="file=images/test/rand_65536.rom,type=23512,cs1=0,cs2=1"

# Test ice-28-a PCB revision (28 pin ROM support, prototype only)
ice-28-a-f446rc-c64c:HW_REV=ice-28-a,MCU=f446rc,CONFIG=old-config/28-c64c.mk
ice-28-a-f446rc-c1541ii:HW_REV=ice-28-a,MCU=f446rc,CONFIG=old-config/28-1541ii.mk

# Test third party configs - put them last as they often fail for me
test-3p-ti994a-f411re:HW_REV=ice-24-f,MCU=f411re,CONFIG=old-config/third-party/ti994a.mk
test-3p-coco2-f411re:HW_REV=ice-24-f,MCU=f411re,CONFIG=old-config/third-party/coco2.mk

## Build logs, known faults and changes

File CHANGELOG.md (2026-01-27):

# Changelog

All notables changes between versions are documented in this file.

## v0.6.2 - 2026-01-27

This release of One ROM introduces RAM support - for 6116 and 2016 2KB 24-pin static RAM chips, using Fire 24 C and onwards hardware revisions.

For a demonstation of RAM support, and an explanation of how it works, see: https://youtu.be/o7dMY6p6OJU

One ROM's JSON [config file format](onerom-config/README.md) now uses "chip_sets" instead of "rom_sets" and "chips" instead of "roms".  However, the old strings will continue to work for backwards compatibility.

Other changes:
- The ability to execute the main loop from RAM has been removed, to allow 512KB to be used for ROM RAM image on RP2350.  It would be possible to add this back where the image size to be held in RAM is under 512KB, and for Ice boards, but as executing from RAM is currently unused, it has been removed for now to save development and test effort.
- fire-24-e revision added as **unverified**.  This adds USB-C, and is intended for production quantities of Fire 24 - as it required JLC's standard assembly service to be used, rather than economic, due to the use of 0201 passives.  The MCU has also been changed to the RP235A, to take advantage of the on-board flash, saving on cost (and space).
- Rename directories `config/` -> `old-config` and `rom-config` -> `onerom-config`.
- The new recommended by to build One ROM firmware is using [`scripts/onerom.sh`](scripts/onerom.sh).  This builds an empty firmware image, adds the chip metadata, and adds the ROM/RAM images in one command.  It even flashes the firmware if desired.  Images are output to [`builds/fw`](builds/fw).

## v0.6.1 - 2026-01-22

### Added

- Prototype RAM support for 24 pin RAM chips, which use the same pin-out as the 6116/2016 RAM.  See PR #98 and discussion #70. Requires building from command line using make and EXTRA_C_FLAGS=-DONE_RAM
- Support for Fire boards (fire-24-d specifically) to use image select pins that are shared with SWD pins.  Note that this means that having an SWD programmer connected at boot will tend to change the image select value to an unexpected one, as the pins will be pulled by the programmer.  In v0.6.0 only 2 image select jumpers were supported on fire-24-d.
- Support for Ice boards (ice-24-j specifically) to use image select pins that are shared with SWD pins.  Note that this means that having an SWD programmer connected at boot may change the image select value to an unexpected one, as the pins will be pulled by the programmer.  In v0.6.0 only 2 image select jumpers were supported on ice-24-j.  Also, unlike the Fire boards, the ice-24-j (and similar) boards will disconnect from the debug probe during boot because of this function, so reconnecting will be necessary.
- Check in Studio/onerom-gen that firmware version is not too new (next major release) when building firmware images.
- Promote fire-24-d and ice-24-j to verified hardware revisions.

### Fixed

- Fixed #90 in v0.6.0 when older (pre v0.1.8) versions of One ROM Studio are used to build firmware images with more than one ROM set, One ROM will not boot on any ROM set other than ROM set 0.
- 2732 ROM type serving was broken - the top 2K replicated the bottom 2K.  Fixed (#103).  This included fixing the testing, which had also not caught this issue.

### Fixed

- 2732 ROM type serving was broken - the top 2K replicated the bottom 2K.  Fixed (#103).  This included fixing the testing, which had also not caught this issue.

## v0.6.0 - 2026-01-14

**EXPERIMENTAL RELEASE** - may contain bugs, use with caution.  If you hit problems, report them as issues and revert to v0.5.10 or earlier.  See [#87](https://github.com/piersfinlayson/one-rom/pull/87) for details of testing done.

This major release of the One ROM firmware adds support for low-level One ROM firmware configuration from the ROM config files, allowing per-ROM image configuration of processor clock speed, status LED behaviour, and other low-level capabilities from One ROM Studio, and other tools.

As a major firmware release, there are some non-backwards compatible changes in this release:

- The ROM config JSON schema has changed - `sel_jumper_pull` is now a Vec<u8>, to allow per-pin SEL jumper pull direction.
- The default PIO configuration is now SLOW_CHAR_CHAR, to improve ROM serving compatibility.  PIO configuration can be overriden on a per ROM set basis using `serve_alg_params` firmware overrides.

### Added

- Support for per-ROM image low-level configuration, including processor clock speed, status LED behaviour, and other low-level capabilities.  See the ROM Config [README](rom-config/README.md) for details.
- Support for fire-24-d and ice-24-j hardware revisions.
- Enhanced onerom-fw CLI tool to receive a local firmware file.
- One ROM Studio v0.1.8.
- Firmware v0.6.0.

### Changed

- ROM config JSON schema change - `sel_jumper_pull` is now a Vec<u8>, to allow per-pin SEL jumper pull direction.
- PIO support is now built into all RP2350 firmwares, and is enabled/disabled by default using RP_PIO build flag.
- RP2350 no longer enters filesystem mode when USB connected - only PICOBOOT protocol supported.

### Known Limitations

- The firmware does not support image select pins shared with SWD pins.  At present image select pins shared with SWD pins are ignored.
  - This is expected to be added in a future release.
  - It is relevant for `fire-24-d` and `ice-24-j` hardware revisions.
  In additon, the configurable per-pin jumper sel behaviour has not been explicitly tested.
- `swd_enabled`: false is not yet functional.  (It is not clear that this is a good idea anyway, as it would make a non-USB board more difficult to reprogram.)  This setting may be removed in a future release.

## v0.5.10 - 2026-01-03

Promote fire-24-c to verified and recommended 24-pin Fire version.

### Added

- issue #77 - Support for serving multi-ROM sets using Fire PIO algorithm.
- ROM types for 32 and 40 pin ROMs

### Changed

- issue #78 - Move RAM ROM image to 0x2000_0000 to prepare for 40 pin versions.

### Fixes

- issue #76 - fire-24-c PIO algorithm fixes.

## v0.5.9 - 2026-01-01

This release adds new One ROM hardware revisions and ROM type support.

### Added

- 231024 (28 pin) ROM type support.
- Hardware revision ice-24-i - Combined Pro (SWD) and USB 24 pin Ice version.
- Hardware revision fire-24-c - Combined Pro (SWD) and USB 24 pin Fire version.
- Hardware revisions fire-28-a2 and fire-28-a3 - Combined Pro (SWD) and USB 28 pin Fire versions.

### Crates

- onerom-config 0.2.5, 0.2.6
- onerom-fw 0.1.5, 0.1.6
- onerom-gen 0.2.3, 0.2.4
- sdrr-fw-parser 0.5.7, 0.5.8

## v0.5.8 - 2025-12-12

This release adds 28 pin ROM support for the new One ROM Fire 28-pin version, fire-28-a.

### Added

- Support for 28 pin ROM types using fire-28-a.  23128 has been tested in a C64C. wotj 2764, 27128, 27256 and 27512 tested in an EEPROM reader.  It is STRONGLY recommended NOT to use an EEPROM reader to read One ROM, as it may apply 12V to pin A9.

## v0.5.7 - 2025-12-09

### Fixed

- Erroneous CE/OE pin numbers for 2716/2732 ROMs.

## v0.5.6 - 2025-12-09

### Added

- Support for 2716/2732 ROMs (2716 tested).
- PIO support for 2316/2716/2732 ROMs (untested)
- Studio 0.1.4

### Fixed

- Comment in Makefile - B is now default serving algorithm.

## v0.5.5 - 2025-11-18

This release adds support for the RP2350 One ROM serving ROMs using the RP2350's PIO/DIO peripheral, allowing fully autonomous ROM serving without any CPU involvement.  A VIC-20 kernal can be served successfully with the RP2350 clocked at just 22MHz, the C64 kernal at 41MHz and the both systems' character ROMs at 51MHz.  There are some limitations, meaning this is not yet the default Fire algorithm:
- Dynamically bank switched ROMs _are_ supported.
- Only CS lines which are contiguous are supported - hence the 2316 is _not_ supported on either rev A or USB rev B.
- Multi-ROM sets, via X1/X2, are _not_ supported, as they are not contiguous with the CS lines in current hardware.

For full support a hardware revision must order the CS lines contiguously either:
- X2/X1/CS1/A12/A11 or
- A11/A12/CS1/X1/X2

To build use `EXTRA_C_FLAGS=-DRP_PIO` when running `make`.  See `sdrr/src/piorom.c` for further details of the PIO/DMA algorithm, and configuration options.

### Fixed

- Enabled FP extensions on both Ice and Fire to avoid hard fault if floating point instructions are used by the compiler.

## v0.5.4 - 2025-11-12

This release adds support for the One ROM Fire (RP2350) USB version, via hardware revision `fire-24-usb-b`.  Current USB support is per Ice - plugging in USB disables ROM serving, and puts the RP2350 into DFU mode to allow firmware updates.  A future release is expected to add Fire USB support in parallel to ROM serving. 

### Added

- Added first RP2350 USB version, [Fire 24 USB B](sdrr-pcb/unverified/fire-24-24-b/README.md), as unverified.
- Added [Ice 24 USB H3](sdrr-pcb/unverified/one-rom-ice-usb-h3-24-pin/README.md) as unverified.
- Moved [Ice 24 USB H2](sdrr-pcb/verified/one-rom-ice-usb-h2-24-pin/README.md) to verified.

### Added

- `onerom-config` 0.2.2 - Added method to query ROM power pins.
- Studio:
    - See [rust/studio/CHANGELOG.md](rust/studio/CHANGELOG.md) for details.
    - Studio is released independently of firmware - see `studio-*` github tags.
- ROM Configs:
    - Blank ROM config (for manufacturing/testing) - /rom-configs/blank.json
    - Added pincoder 2021 version system 3, 5, 6 and 7 ROM configs (2332 ROMs)
- Allow `sdrr-fw-parser` to parse up to v0.5.999 firmware versions. 

### Fixes

- [#43](https://github.com/piersfinlayson/one-rom/issues/43) - Let sdrr-fw-parser parse later versions of fw. Supports up to v0.5.999 with no code/wasm/site changes required.
- Allow multi-ROM sets to be built in One ROM Studio.  Unsure when this was regressed

## v0.5.3 - 2025-10-24

The major addition in this release is the companion desktop application, One ROM Studio, which provides a native GUI for creating One ROM firmware images, and analysing and flashing One ROM devices.

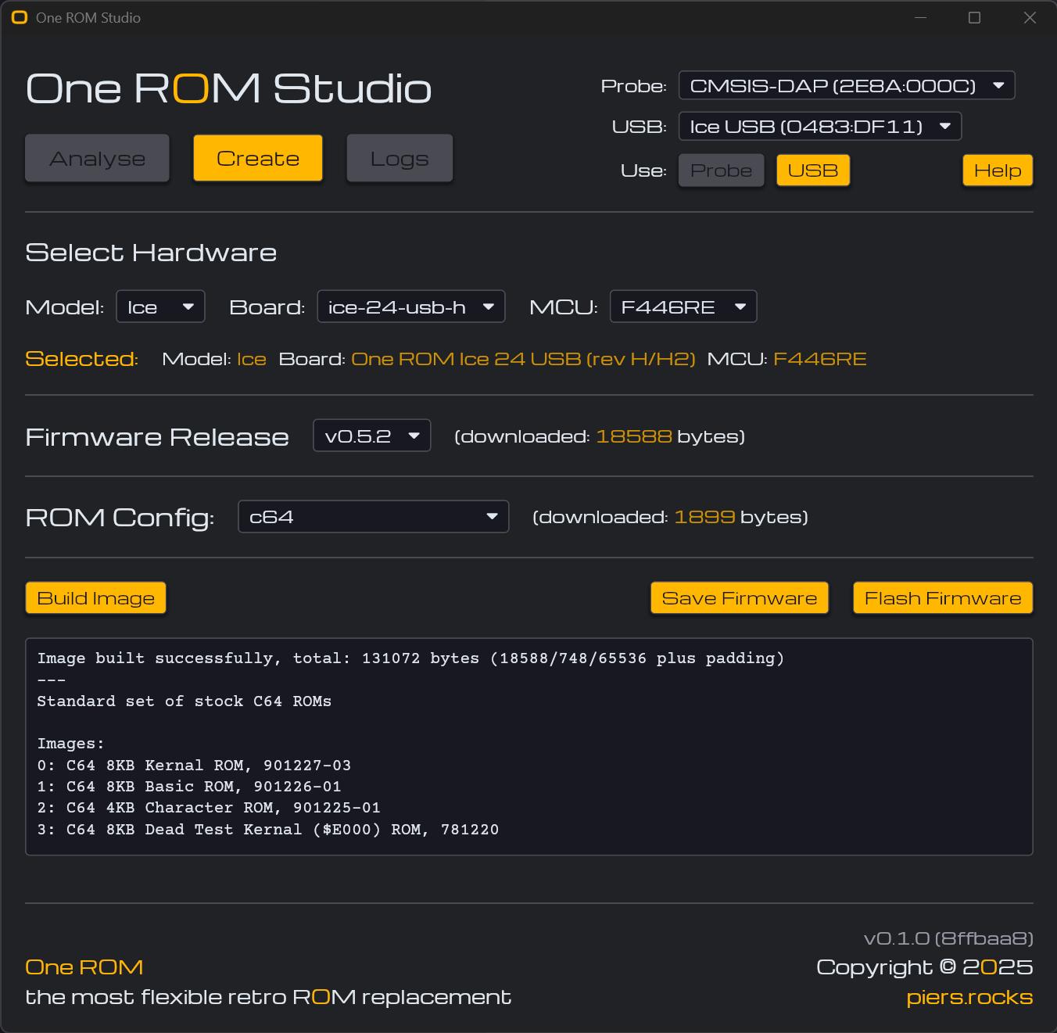
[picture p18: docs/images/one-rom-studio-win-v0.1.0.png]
One ROM Studio on Windows


Features include:
- Supported platforms: Windows, Mac, Linux (Ubuntu, Debian and Raspberry Pi OS)
- Supported One ROMs: all variants including Ice/Fire and Pro/USB
- Program One ROMs with a choice of ROM images
- Generate and save One ROM firmware files
- Analyse One ROM devices and firmware files
- Automatic debug probe and One ROM USB detection

One ROM Studio can be downloaded from https://onerom.org/studio/.

### Added

- Added "limp mode" support to detect when an incompatible firmware has been flashed to an Ice One ROM.  It blinks fast in this state and, if it is a USB model, allows the device to drop into DFU mode when USB is connected, to allow flashing of a compatible firmware.  Note that "slower" MCU firmwares are permitted by "faster" MCUs - but not the other way around.  See #37 for details.

### Fixes

## v0.5.2 - 2025-10-14

New in this release is a command line firmware image creation tool `rust/fw`.  This dynamically creates a custom One ROM firmware image from a specified:
- set of ROM images (specified as a JSON config file)
- model, board and MCU type (specified as command line arguments)
- optional firmware version (defaults to the latest version available)

To build:
```bash
cd rust/fw
cargo build --release --bin onerom-fw
# Binary is located at /rust/target/release/onerom-fw
```

This is a precursor to simplifying the CI builds to avoid having to create every combination of hardware/ROM config as build artifacts.  The hardware combinations can be pre-built with empty metadata and ROM image data, and this tool then composes a complete firmware image, ready for flashing.

As v0.5.1, and empty firmware image can also be flashed - One ROM then blinks its status LED slowly, and can have metadata and ROM images flashed to it later.

The complete list of available "empty" hardware configuration firmwares can be found at https://images.onerom.org/releases.json.

This command line tool may also be augmented with a native GUI, in parallel to the web-based tool at https://onerom.org/prog/.

### Changes

- Improved `onerom-gen` testing, and improved `onerom-config` and `onerom-gen` validation.

### Fixes

- Fix rust/gen/tests for boards with address lines all >=8.
- Fix `sdrr-info` processing of firmware from v0.5.1 onwards with detailed metadata content in a valid, but unexpected, order.

## v0.5.1 - 2025-10-13

For the average user, there are no particularly notable changes in this release, except the addition of the [Atari 800XL BASIC ROM config](/config/atari800xl.mk).

The firmware generator process underwent a major overhaul in this release:
- Support ROM types and hardware (PCB) revisions are now parsed at build time, which can be included in Web Assembly code.
- `sdrr-common` has been retired and mostly replaced with `onerom-config`
- Much of `sdrr-gen` has been moved out to `onerom-gen` crate, which can be used in other Rust projects, including Web Assembly.
- There is a new `onerom-wasm` crate at https://github.com/piersfinlayson/one-rom-wasm, which can be used to build Web Assembly code to generate One ROM firmware images in the browser.  Web Assembly packages, documentation and examples are located at https://wasm.onerom.org/.
- A metadata and ROM-less firmware can be built with `EXCLUDE_METADATA=1`.  When flashed with ths firmware, One ROM blinks its status LED slowly.  It can subsequently have metadata and ROM image fragments flashed, and, when reset, serves the newly flashed images.  This is expected to be useful for release artifacts and manufacturing, as a single firmware per hardware variant per release can be built, with metadata and ROM images added later, rather than the current need to build a firmware per hardware variant **per configuration** per release.

There is more work planned to the firmware upgrade process, including multi-stage USB device updates using the new capabilities, but this release has laid the groundwork and enabled some exciting new web-based features.

Also, the first, prototype 28 pin ROM support using hardware revision `ice-28-a` is in this release.  It successfully emulates a 27128 ROM (i.e. without the 3rd CS line on a 23128).  It has been tested successfully on a C64C, replacing the combined KERNAL/BASIC ROM with a One ROM Ice 28 A, clocked at just 55MHz using an STM32F446RCT6. This hardware revision is unlikely to be taken forwards - a different hardware layout is required to support 23128 with the 3rd CS line being used, as well as 32KB and 64KB ROMs.

Some default firmware configuration has been changed:
- BOOT_LOGGING is now disabled by default to improve boot times.

### New

- [Atari 800XL BASIC ROM config](/config/atari800xl.mk) included (and tested and working!)

### Changes

- Call out from sdrr-gen to wget to retrieve images located on sourceforge, as cloudfare seems to spot and block Rust TLS.
- Moved the PCB config/property files from `/hw-config` to `/rust/config/json`.

### Fixes

- Make "no ROMs installed" LED blink pattern slower, to be more visible.  Now on for 0.5s, off for 2.5s.  Previously flashed much too fast to be used properly.

## v0.5.0 - 2025-10-07

This release adds a bunch of hardware revisions, plus a modified flash and firmware format, to ease future device re-programming.

As a consequence of the new flash/firmware format, some of the STM32 variants (F401RB/RC, F411RC, F446RC) support 2 fewer ROM images than before.

### New

- New flash/firmware format, with firmware code, followed by ROM metadata, followed by ROM images. 
- Added One ROM Ice USB H2 (unverified).
- Added One Rom Ice USB H (verified) kicad files.
- Added One ROM Fire USB B (unverified)

### Changes

Moved USB programmer site to https://github.com/piersfinlayson/one-rom-site repo.

## v0.4.4 - 2025-09-30

This is a point release that changes the release artifact generation, to set up the One ROM USB programmer to be able to offer to flash pre-built firmware images from the release artifacts.

Release artifact change summary:
- Include additional hardware variants
- Only include .bin files (not .elf, .dis, .map) in the release artifacts.
- Remove some of the less common STM32 variants from the release artifacts (to save build time and space)
- Include a build artifact manifest JSON file. 

If the particular release artifact you want is no longer included, you can build it yourself from source.

### Changes

Updated:
- USB One ROM site (onerom.piers.rocks):
  - Added the ability to select a local file as the firmware source, in addition to a URL.
  - Add check to prevent non-USB firmware being flashed.
  - Add check to ensure the MCU the firmware was build for matches the MCU the user selected.
- CI build process, to create release artifacts:
  - Now only creates .bin files (not .elf, .dis, .map) - if you want the other types, build them yourself.
  - Creates images for multiple different hardware revisions.

## v0.4.3 - 2025-09-29

Added USB DFU support for firmware updates over USB, along with STM32 24-pin rev H hardware (24-h) which includes a micro-USB connector.  One ROM detects when USB is connected, disables ROM serving, and enters STM32 DFU mode to allow the firmware to be updated.

There is also a new web-based programmer for One ROM USB, at https://onerom.piers.rocks/.  This can be used on Chrome or Chromium based browsers on Windows, Linux, or MacOS to program an attached One ROM USB.

### Changes

Updated:
- sdrr
- sdrr-hw-config
- sdrr-pcb
- sdrr-common
- sdrr-fw-parser
- sdrr-gen
- sdrr-info

### Fixes

## v0.4.2 - 2025-09-06

Added [One ROM Lab](rust/lab/README.md) support, which allows a One ROM to be used as a ROM reader.

### Changes

- Added fw-parser for One ROM Lab
- Modify sdrr-info/parser to support Airfrog custom firmware changes

### Fixes

- Probably a few here and there.

## v0.4.1 - 2025-08-28

### Changes

- Move STM32F4 hardware rev G to verified.
- Add KiCad design files for RP2350 rev A and STM32F4 rev G.

### Fixes

- #8 - reduce severity of VOS not ready warning, as it appears to be benign.
- Include RP2350 images in github release.
- Add RP2350 build commands to README.md and generally update the docs to refer to One ROM/RP2350.

## v0.4.0 - 2025-08-24

**The RP2350 release.**

This version contains the first RP2350 PCB revision, and mostly complete firmware support.

Should you use the new RP2350 hardware revision A?  Only limited testing of the RP2350 One ROM has been done so far, but it has generally performed well.

There is one outstanding, known issue - when using the RP2350 One ROM a character ROM on a PAL VIC-20 occasionally the machine boots to a black screen background - that is the machine boots to BASIC and shows the expected text, but the screen is black, not white.  This may be a boot timing issue - that perhaps One ROM RP2350 is not booting fast enough for the VIC chip, which is getting corrupted somehow.  This issue does not appear on a C64 (which has a different video bus architecture).

You may want to order and test small quantities of RP2350 based boards for now, as there is some risk of a hardware design issue coming to light.  However, the hardware appears solid in early testing, so it is likely most issues can be overcome by firmware changes - and it is expected that the RP2350 revision A will continue to be supported in future releases, even should another variant be released.

Other notable changes:

- Instead of building with `STM=<mcu variant> make`, you now need to use `MCU`:

  ```bash
  MCU=<mcu_variant> make
  ```

### Changes

- Added RP2350 support.
  - Hardware rev A.
  - Includes single ROM images, dynamically bank switched, and multi-ROM sets.
  - Includes image select jumpers, status LED, overclocking.
  - Features not supported include: C main loop, MCO output.
  - For the gory details of supporting the RP2350, see [RP2350](docs/RP2350.md).
- Added STM32F4 24-pin PCB rev G hardware configuration.  This adds a different programming header and one more image select jumper (so 5 in total, plus X1/2).
- Added hardware and firmware configuration to specify whether the image select jumpers and X1/X2 pins are pulled high or low when the PCB jumper is closed, to allow for different PCB designs.
- Added firmware support for up to 7 image select jumpers.
- Change STM32 MCO (and MCO2) divider to be /5 (previous value was /4).  Makes it easier to measure the clock speed of an overclocked STM32F4.
- Substantially refactored platform specific code to break out platform agnostic code - significant work to `sdrr/src/main.c`, `utils.c` and `rom_impl.c`.
- Tested overclocking and various STM32 clones.

### Fixes

- It is likely that the 4th image select pin on revs E/F didn't work properly - this has been fixed.

## v0.3.1 - 2025-08-16

The project has been renamed One ROM (To Rule Them All).

This release is a few odds and ends including some hardware improvements:
- One ROM hardware revision [F2](/sdrr-pcb/verified/stm32f4-24-pin-rev-f2/README.md) is currently recommended.
- An **unverified** hardware revision [G](/sdrr-pcb/unverified/stm32f4-24-pin-rev-g/README.md) is in testing.  This brings mostly layout improvements and slightly reduced manufacturing costs.
- The fastest STM32F4 MCU, the STM32F446 has been verified to work.   This brings a max supported clock speed of 180MHz, and has run stably up to 300MHz in testing.
- The STM32F405 has provided slower than expected (more details below).  It is supported and a decent choice, but the GigaDevices GD32F405 appears to be more performant.

### Changes

- Speed up STM32F405 support:
  - The STM32F405 is under-performant vs the other devices at the same clock speed - needs around 30-40% faster clock speed.
  - Added CCM RAM support for the F405, bringing the uplift in clock speed down to around 15-20%.
  - To disable CCM RAM set `C_EXTRA_FLAGS=-DDISABLE_CCM=1` when building.
  - The STM32F405 is still a decent MCU choice for One ROM, as its max clock speed is 168MHz compared with the F411's 100MHz.  However, users may wish to use the GigaDevices clone GD32F405, which appears to have no performance penalty. 
- Hardware revision 24-f2 is now verified.  JLC have successfully fabbed using the hardware files both STM32F411 and STM32F405 variants.
- Allow more aggressive overclocking (up to 400MHz).
- Validated STM32F446RCT6 (STM32F446RET6 highly likely to work as well).  Successfully tested as C64 char ROM, and verified clock speed of 180MHz (via MCO1 showing 45MHz = SYSCLK/4).  Also overclocked to 300MHz, ran stably.
- Added **unverified** hardware revision 24-g.

### Fixes

- Explicitly prevent COUNT_ROM_ACCESS and C_MAIN_LOOP being configured together, as they are incompatible.
- Fixed ability to run main loop from RAM (this tends to be slower than from flash, so isn't recommended).

## v0.3.0 - 2025-08-12

The main user facing change in this release is the addition of support for remote analysis and co-processing alongside the SDRR device via plug-ins, such as [Airfrog](https://piers.rocks/u/airfrog) - **a tiny $3 probe for ARM devices**.  This allows you to inspect the firmware and runtime state of the SDRR device, and change its configuration and ROM data - **while it is serving ROMs**.

There is also new ROM access counting feature, which causes SDRR to count how times the CS line(s) go active.  This can be extracted and visualised using [Airfrog](https://piers.rocks/u/airfrog) and other SWD probes, to determine how often the ROMs are accessed based on host activity.

ROM Access Graph

The Rust tooling has been substantially refactored to easier to integrate SDRR support in third-party tooling, such as [Airfrog](https://piers.rocks/u/airfrog).  In particular there is [Firmware Parser](rust/sdrr-fw-parser/README.md) crate, which can be used to parse the firmware from a file or running SDRR, and extract information about the configuration, ROM images, and to extract ROM images from the firmware.

### Changes

- TI-99/4A and CoCo2 configurations have been added to the [third-party configs](config/third-party/README.md) directory.  Thanks to [@keronian](https://github.com/keronian) for contributing these.
- Added a C main loop implementation for which GCC produces the assembly/machine code.  This requires a roughly 25% faster clock speed.  Use `EXTRA_C_FLAGS=-DC_MAIN_LOOP` when running `make` to use this version.
- Stored off image files used to create the firmware in `output/images/`.  This allows post build inspection of the images used.  It also enables additional tests - `sdrr-info` can be now be used as an additional automated check (along with `test`), to ensure the images in the firmware are correct, and validate the behaviour of `sdrr-info` and `test` to be compared.
- Substantial refactoring of `sdrr-gen`, to make it more maintainable.
- Substantial refactoring of `sdrr-fw-parser` in order to make it suitable for airfrog integration.
- Added ROM access counting behind COUNT_ROM_ACCESS feature flag.  When enabled, the firmware updates a u32 counter at RAM address 0x20000008 every time the chip select line(s) go active - i.e. the ROM is selected.  This can be read by an SWD probe, such as [Airfrog](https://piers.rocks/u/sdrr). 
- Changed default Makefile configuration to HW_REV=24-f COUNT_ROM_ACCESS=1 STATUS_LED=1.
- Added a manufacturing test tool [`sdrr-check`](rust/sdrr-check/README.md).
- Changed default build config:
  - HW_REV=24-f
  - STATUS_LED=1
  - COUNT_ROM_ACCESS=1
- Added retrieval of mangled ROM images from firmware.  This can be used to compare the embedded images between different firmwares and to collect a pre-mangled ROM images in order to overwrite a running SDRR's RAM image with it.
- Added new "One ROM To Rule Them All" BASIC program for upcoming video. 

### Fixes

- Probably a few here and there.

## v0.2.1 - 2025-07-22

The main new feature in this version of SDRR is the addition of dynamic [bank switching](docs/MULTI-ROM-SETS.md#dynamic-bank-switching) of ROM images.  This allows SDRR to hold up to 4 different ROM images in RAM, and to switch between them **while the host is running** by using the X1/X2 pins (hardware revision F and later) to switch between them.  Some fun [C64](config/bank-c64-char-fun.mk) and [VIC-20](config/bank-vic20-char-fun.mk) character ROM configurations that support bank switching are included.

In other news:
- The default ROM serving algorithm has been improved, leading to better performance, and hence the ability to support more systems with lower powered STM32F4 devices than before.  Check out [STM32 Selection](docs/STM32-SELECTION.md). The current price/performance sweet spot is the F411.
- [Hardware revision E](sdrr-pcb/verified/stm32f4-24-pin-rev-e/README.md) is now fully verified, so manufacture these with confidence.
- If you'd rather use [revision F](sdrr-pcb/unverified/stm32f4-24-pin-rev-f/README.md) (required for multi-ROM and bank switching support), at least once user has reported getting these manufactured and working with his NTSC VIC-20 - although they did not testing either multi-ROM or bank switching support.

### Changes

- Added pull-up/downs to X1/X2 in multi-ROM cases, so that when a multi-set ROM is configured, but X1/X2 are not connected, the other ROMs in the set still serve properly.
- Improved serving algorithm `B` in the CS active low case.
- Moved to algorithm `B` by default.
- Measured performance of both algorithm on all targets.
- Refactor `rom_impl.c`, breaking out assembly code to `rom_asm.h` to make the main_loop easier to read, and commonalising a bunch of the code for greater maintainability.
- Added detection of hardware reported STM32F4 device and flash size at runtime, and comparison to firmware values - warning logs are produced in event of a mismatch.
- Verified [hw revision e](/sdrr-pcb/verified/stm32f4-24-pin-rev-e/) - supports STM32F4x5 variants in addition to F401/F411, all passives are now 0603, contains a status LED and a 4th image select jumper.
- Added [documentation](/docs/STM32-CLONES.md) on STM32 clones.
- Moved firmware parsing to [`rust/sdrr-fw-parser`](/rust/sdrr-fw-parser/README.md) crate, which can be used to parse the firmware and extract information about the configuration, ROM images, and to extract ROM images from the firmware.  Done in preparation for using the same code from a separate MCU.
- Moved Rust code to [`rust/`](/rust/) directory to declutter the repo a bit.
- Added experimenta; [build containers](/ci/docker/README.md) to assist with building SDRR, and doing so with the recommended build environment.
- Added dynamic [bank switchable](docs/MULTI-ROM-SETS.md#dynamic-bank-switching) ROM image support, using X1/X2 (you can use __either__ multi-ROM __or__ bank switching in a particular set).
- Added fun banked character ROM configs.
- Added VIC-20 NTSC config.
- Added retry in [ci/build.sh](ci/build.sh) to allow for intermittent network issues when downloading dependencies.
- Added [demo programs](demo/README.md) for C64 and VIC-20 to list SDRR features and other information/

### Fixes

- Fixed status LED behaviour, by placing outside of MAIN_LOOP_ONE_SHOT, and using the configured pin.
- Got `sdrr` firmware working on STM32F401RB/RC variants.  These have 64KB RAM, so can only support individual ROM images (quantity limited by flash) and do not support banked or multi-set ROMs.

## v0.2.0 - 2025-07-13

This version brings substantial improvements to the SDRR project, including:

- A single SDRR can be used to replace multiple ROM chips simultaneously.
- New [`sdrr-info`] tool to extract details and ROM images from firmware.
- Add your own hardware configurations, by adding a simple JSON file.
- New STM32F4 variants supported.
- Comprehensive testing of compiled in images to ensure veracity.

Care has been taken to avoid non-backwards compatible interface (such as CLI) changes, but some may may have been missed.  If you find any, please report them as issues.

### New Features

- Added support for ROM sets, allowing SDRR to serve multiple ROM images simultaneously, for certain combinations of ROM types.  This is done by connecting just the chip selects from other, empty sockets to be served, to pins X1/X2 (hardware revision 24-f onwards).  Currently tested only on VIC-20 (PAL) and C64 (PAL), serving kernal and BASIC ROMs simultaneously on VIC-20 and kernal/BASIC/character ROMs simultaneously on the C64.  See [Multi-ROM Sets](/docs/MULTI-ROM-SETS.md) for more details.
- Added [`sdrr-info`](/rust/sdrr-info/README.md) tool to parse the firmware and extract information about the configuration, ROM images, and to extract ROM images from the firmware.  In particular this allows
  - listing which STM32F4 device the firmware was built for
  - extraction of ROM images from the firmware, for checksumming and/or comparing with the originals.
- Moved hardware configuration to a dynamic model, where the supported hardware configurations are defined in configuration files, and the desired version is selected at build time.  Users can easily add configurations for their own PCB layouts, and either submit pull requests to include them in the main repository, or keep them locally.  For more details see [Custom Hardware](/docs/CUSTOM-HARDWARE.md).
- Added support F446 STM32F446R C/E variants - max clock speed 180 MHz (in excess of the F405's 168 MHz).  Currently untested.
- Added [`test`](/test/README.md), to verify the images source code files which are built into the firmware image, output the correct bytes, given the mangling that has taken place.

### Changes

- Updated VIC-20 PAL config to use VIC-20 dead-test v1.1.01.
- 24-pin PCB rev E/F gerbers provided (as yet unverified).
- Many previously compile time features now moved to runtime.
- Makefile produces more consistent and less verbose output.
- Added `sddr_info` struct to main firmware, containing firmware properties, for use at runtime, and later extraction.  This should also allow querying the firmware of a running system via SWD in future.

### Fixed

- Moved to fast speed outputs for data lines, instead of high speed, to ensure VOL is 0.4V, within the 6502's 0.8V requirement.  With high speed outputs, the VOL can be as high as 1.3V, which is beyond the 6502's 0.8V requirement.

## v0.1.0 - 2025-06-29

First release of SDRR.

- Supports F401, F411, and F405 STM32F4xxR variants.
- Includes configurations and pre-built firmware for C64, VIC-20 PAL, PET, 1541 disk drive, and IEEE disk drives.
- PCB rev D design included.
- Release binaries

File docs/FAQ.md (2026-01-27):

# One ROM Frequently Asked Questions

January 2026 - this FAQ is a little out of date.  For programming see [One ROM Studio](https://onerom.org/studio) and [One ROM Web](https://onerom.org/web).

## What is One ROM?

**Q: What exactly is One ROM?**

A: One ROM is a ROM replacement solution that uses a cheap RP2350 or STM32F4 microcontroller to emulate failed or missing ROMs in retro computers. It is easily reprogrammed, can store up to 16 different ROM images and switch between them using jumpers, eliminating the need for expensive EEPROM programmers or multiple physical ROM chips.

**Q: What is Software Defined Retro ROM (SDRR)?**

A: The old name for One ROM.  While it captures the technical essence of One ROM, it wasn't exactly catchy.

**Q: Why would I use One ROM instead of buying replacement ROMs or using an EEPROM?**

A: One ROM offers several advantages:

- Much cheaper to program than xEPROMs ($5 programmer vs $40+ for xEPROM programmers).
- Fits the exact footprint of original ROMs, no overhanging the socket.
- Can be reprogrammed in-situ without removal, allowing sub-minute times to recompile and reflash firmware.
- Stores multiple images.
- Can support all required chip select line behaviours without any hardware changes.
- Is faster to build and program (just `make run` vs complex xEPROM procedures).
- Makes it easy to download and combine ROM images from various sources - no need to build combination ROM images by hand.
- Have various advanced features, such as boot time and dynamic image selection, and the ability to serve multi ROM sockets from a single ROM. 

**Q: What ROM types does One ROM support?**

A: One ROM currently emulates 2364 (8KB), 2332 (4KB), and 2316 (2KB) ROMs commonly used in Commodore systems, disk drives, and other retro computers.

The original ROMs had mask programmable chip select behaviour, which meant they could be either low or high when selected. One ROM can emulate this by configuring the chip select lines in software, allowing it to work with any system that uses these ROM types - and can support multiple images with different chip select configurations in a single firmware build.

## Hardware Compatibility

**Q: Which MCU variants are supported?**

A: Currently supported variants include:

- Raspberry Pi RP2350 (A4 stepping, 150Mhz max clock, 8 ROM images)
- STM32F401RBT6/RCT6/RET6 (84MHz max clock, 6-16 ROM images)
- STM32F411RCT6/RET6 (100MHz max clock, 14-16 ROM images)  
- STM32F405RGT6 (168MHz max clock, 16 ROM images)
- STM32F446RCT6/RETx (180MHz max clock, 16 ROM images)

The RP2350/F405/F446 are recommended for maximum compatibility as they runs fastest and supports the maximum number of target systems.

Note all MCUs are overclockable.

See [Supported Microcontrollers](/docs/MCU-SELECTION.md) for more details.

**Q: What retro systems work with One ROM?**

A: Tested systems include Commodore PETs, VIC-20s, C64s, TI-99, 1541 drives, and IEEE-488 drives. The F405 variant running at 168MHz should support virtually any system using compatible ROM types, including faster 2MHz systems.

If One ROM **doesn't** work in your system, replacing a 2364, 2332 or 2316, we want to hear about it!  Please [raise an issue](/README.md#debugging).

**Q: How do I know which MCU variant I need?**

A: Choose based on your target system's timing requirements. PETs need 26MHz minimum, VIC-20s need 37MHz, C64 kernals need 75MHz, and C64 character ROMs need 98MHz.

Use RP2350, F405 or F446 if unsure - they support all target systems.

See [MCU Selection](/docs/MCU-SELECTION.md) for more details.

**Q: Why are you using the STM32's internal oscillator - doesn't that make it unstable?**

A: An internal oscillator was one of the microcontroller selection criteria, in order to simplify the design, and reduce the PCB footprint and BOM cost.  The STM32F4 runs stably off its internal oscillator, although its accuracy is not as good as from an external crystal.  A precisely accurate clock is not required for this application - it primarily requires raw speed.

**Q: Why can't I find the MCU for $2?**

A: You need to look at Chinese sites including [aliexpress.com](https://www.aliexpress.com) and [LCSC](https://www.lcsc.com), JLC PCB's component supplier ARM.

As of July 2025:

- LCSC wanted $1.74 for a single RP2350.
- LCSC had STM32F401 for $1.93 in quantities of 1 - good enough for PET, VIC-20 and C64 single ROMs
- LCSC had STM32F411 for $2.69 in quantities of 1 - also good enough for C64 multi-ROM sets
- aliexpress had STM32F405 for $3.08 in quantities of 1 - faster than the F401/F411
- aliexpress had GD32F405 $2.27 in quantities of 1 - GigaDevices produces clones of the STM32 parts

The aliexpress seller referred to above was also offering free shipping when buying more than 4 or 5 parts.

One ROM is extremely flexible in the STM32F4xxR variants it supports, so you can choose the cheapest one that meets your requirements.

**Q: Are STM32 clones just as good as the real deal STM32?**

A: Mostly, but not entirely.  The GigaDevices GD32F405 may take longer to boot than the STM32F405, but generally appears more performantSee [STM32 Clones](/docs/STM32-CLONES.md) for more details.

## Installation and Setup

**Q: What do I need to get started?**

A: You need:

- One ROM PCB
- a supported microcontroller
- some other components (voltage regulator, LED, resistors and capacitors)
- ARM GNU toolchain, Rust, probe-rs
- and an SWD programmer (ST-Link, Pi Debug Probe, or programmed Pi Pico).

See the [Installation Guide](INSTALL.md) for detailed setup instructions.

**Q: How difficult is the PCB assembly?**

A: Depends on the board.

STM32 - Medium difficulty - some experience with surface mount soldering is recommended.

The rev D PCB uses a combination of 0402 and 0603 components.

Rev E/F PCBs uses all 0603 components, so are easier to solder.

All variants use an STM32 LQFP64 package, which requires soldering as it is close to other components.

RP2350 - High difficulty.  Recommend getting these assembled.

**Q: Can I use a Raspberry Pi Pico as a programmer?**

A: Yes! Flash the debug probe firmware to a Pi Pico and connect CLK (GP2), DIO (GP3), GND, and optionally 5V (VBUS). This provides a $5 programming solution.

See the [Pi Pico Programmer Guide](/docs/PI-PICO-PROGRAMMER.md) for detailed instructions.

## Programming and Flashing

**Q: How do I flash firmware to One ROM?**

A: Connect your programmer's CLK, DIO, and GND lines to One ROM, then run a command like this:

```bash
MCU=f411re CONFIG=old-config/c64.mk make run
```

This automatically downloads ROMs, generates firmware, and flashes the device.

There are other pre-collated collections of ROMs available in the [`old-config/`](/old-config/) directory, such as `vic20-pal.mk`, `pet-4-40-50.mk`, and `1541.mk`. You can also create your own custom configurations.

**Q: Can I reprogram One ROM while it's installed in my retro system?**

A: Yes! You can flash in-situ with the system powered on. The system may crash during flashing but will work normally after completion.

**Never** externally power One ROM when installed in a retro system.

**Q: What if I have flashing problems?**

A:

STM32: Jump the BOOT0 pin to 3.3V and power cycle to force bootloader mode, then reflash. Alternatively, enable the `BOOTLOADER` config option to enter bootloader mode when all image select jumpers are closed.

See the [Programming Guide](/docs/PROGRAMMING.md) for more details.

RP2350: Jump the BOOT pin to GND and power cycle to force bootloader mode, then reflash.

**Q: How can I see what platform in my firmware image is for?**

A: You can use [`sdrr-info`](/rust/sdrr-info/README.md) to inspect firmware `.elf` and `.bin` files.

**Q: How can I see what ROMs are in my firmware image?**

A: You can use [`sdrr-info`](/rust/sdrr-info/README.md) to inspect firmware `.elf` and `.bin` files.

## Configuration and Usage

**Q: How do I select which ROM image to use?**

A: Use the image select jumpers labeled 1, 2, 4, and 8 on the PCB bottom.  Close jumpers to form a binary number (0-15) corresponding to your desired ROM image.  A closed jumper corresponds to 1, an open jumper 0.

You must reboot One ROM after changing jumpers.

**Q: How many ROM images can I store?**

A: Up to 16 images, limited by either flash size (smaller variants) or the physical jumper count. Each image consumes 16KB of flash regardless of actual ROM size.

**Q: Can I mix different ROM types in one firmware?**

A: Yes! Each ROM image can be independently configured as 2364, 2332, or 2316 with different chip select configurations. See the [config files](/old-config/) for examples.

**Q: How do I create custom ROM configurations?**

A: Define `ROM_CONFIGS` with file paths, ROM types, and chip select settings:

```bash
ROM_CONFIGS=file=kernal.rom,type=2364,cs1=0 file=basic.rom,type=2364,cs1=0
```

Or create your own [config file](/old-config/).

## Performance and Technical

**Q: Can you add feature X to One ROM?**

A: Perhaps - raise an issue on the [GitHub issues page](https://github.com/piersfinlayson/software-defined-retro-rom/issues).

One ROM is very busy serving ROM images, so has few spare cycles for additional features.  However, it can be augmented by a co-processor such as [Airfrog](https://piers.rocks/u/airfrog) to provide additional functionality, such as remote access and control, or telemetry.  The RP2350 is likely to get additional features, on-board, due to its second core.

**Q: Why does One ROM store all ROM images as 16KB in flash?**

A: This optimization allows the main loop to use chip select states as direct address offsets, eliminating runtime calculations and achieving the required access speeds.

See [Technical Details](/docs/TECHNICAL-DETAILS.md) for more information.

**Q: What makes One ROM fast enough for retro systems?**

A: Multiple optimizations: maximum clock speeds, highly optimised assembly main loop, preloaded ROM data in RAM, no interrupts, flash prefetch/caching, and "mangled" ROM storage that matches the PCB pin mapping.

See [Technical Details](/docs/TECHNICAL-DETAILS.md) for more information.

**Q: Why not use interrupts?**

A: Interrupts would add latency that could cause the system to miss critical timing windows. The polling-based approach ensures consistent, predictable response times.  As One ROM does nothing other than serve flash, a tight main loop with no interrupts is sufficient **and** optimal.

**Q: Isn't the RP2350/STM32 a 3.3V device? How does it work in 5V systems?**

A: Most of the GPIO pins on the RP2350/STM32F4xx are 5V tolerant, and the maximum and minimum input and output voltage levels are compatible with the main target retro driving ICs (such as the 6502, VIC and VIC-II) chips.  Care is taken to ensure that only 5V tolerant GPIOs are used, including setting the drive strength on the STM32 to stay within the required output levels.

There's a detailed analysis in [Voltage Levels](/docs/VOLTAGE-LEVELS.md).

**Q: What languages are used in One ROM?**

A: The main [`sdrr`](/sdrr/) firmware is written in a combination of C and assembly.  Assembly is used for the main loop to achieve the required performance, while C is used for the startup-up logic.

C was chosen above other lanuages in order to stay as close as possible to the hardware, for performance reasons.  The C code is fully bare-metal - no hardware abstraction layer or other libraries are used, except [SEGGER-RTT](https://github.com/piersfinlayson/segger-rtt) for logging.

The [`sdrr-gen`](/rust/sdrr-gen/README.md) tool, which generates the ROM images and other code to embed in the main firmware is written in Rust.

**Q: What does the build pipeline look like.**

```ascii
User Input → Top-level Make → sdrr-gen → sdrr Make → sdrr-info → test (optional) → probe-rs → STM32
    ↓              ↓            ↓          ↓             ↓              ↓              ↓        ↓
Config Files  ROM Download    Code Gen    Compile      Query      Compile tests      Flash    Running
ROM Images    & Validation    & Mangle    & Link      Firmware        & Run         Firmware
```

See [Build System](/docs/BUILD-SYSTEM.md) for more details on how the build system works.

## Troubleshooting

**Q: How do I debug One ROM issues?**

A: Enable boot logging (default) to see startup information via SWD/RTT. This shows hardware info, ROM configurations, frequency settings, and which image is loaded. Boot logging adds ~1.5ms to startup time.

See [Logging](/docs/LOGGING.md) for more details.

**Q: My retro system doesn't boot with One ROM installed. What should I check?**

A: Verify the correct ROM type and chip select configuration, ensure One ROM is fully seated in the socket, check that the STM32 variant can run fast enough for your system, and review boot logs for errors.

It would be worth reprogramming One ROM with your firmware image in-situ, and viewing the logs to ensure the expected ROM image is being served.

See [`BOOT_LOGGING`](/docs/LOGGING.md#boot_logging) for more details on how to interpret boot logging.

**Q: Can I reduce power consumption?**

A: Lower the clock frequency using the `FREQ` option, disable the status LED with `STATUS_LED=0`, or choose a lower-power STM32 variant if it meets your timing requirements.

[Clock Speed Requirements](/docs/STM32-SELECTION.md#clock-speed-requirements) provides guidance on selecting the right frequency for your system, but you may need to experiment to find the best balance between performance and power consumption.

## Cost and Availability

**Q: How much does One ROM cost to build?**

A: In small quantities, expect around $5 per device.  The STM32F4 costs around $2 depending on variant, PCB manufacturing is inexpensive (2-layer, single-side components), and the BOM is minimal.

**Q: Where can I get the PCB?**

A: Order the latest revision from [OSH Park](https://oshpark.com) using the provided link for your chosen revision in the [`sdrr-pcb`](/sdrr-pcb/README.md), or manufacture using the open-source design files.  We use JLC PCB to assemble our One ROMs, and are very happy with their service.

**Q: Is One ROM open source?**

A: Yes! Software/firmware uses MIT license, hardware uses CC BY-SA 4.0. You can modify, improve, and share the designs within the license terms.

**Q: Is there a warranty?**

A: In common with most open source projects, no warranty is provided.  See [License](/LICENSE.md) for details.  The project is provided "as is" without any guarantees of fitness for purpose or reliability.

However, if you find a bug or issue, please raise an issue via GitHub.

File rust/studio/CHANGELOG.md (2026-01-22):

# Changelog

## v0.1.9 - 2026-01-22

### Fixed

- Fixed #90 in v0.6.0 when older (pre v0.1.8) versions of One ROM Studio are used to build firmware images with more than one ROM set, One ROM will not boot on any ROM set other than ROM set 0.
- 2732 ROM type serving was broken - the top 2K replicated the bottom 2K.  Fixed (#103).  This included fixing the testing, which had also not caught this issue.

## v0.1.8 - 2026-01-14

### Added

- Support for low level config of firmware at runtime using JSON files #87.

## v0.1.7 - 2026-01-03

### Added

- #77 - Support for serving multi-ROM sets using Fire PIO algorithm.

## v0.1.6 - 2026-01-01

### Added

- 231024 ROM support in JSON config files.
- fire-24-c
- ice-24-i

## v0.1.5 - 2025-12-12

### Added

- fire-28-a

## v0.1.4 - 2025-12-09

### Added

- Support for local files to onerom-fw and onerom-studio.

### Fixed

- Set Windows PE file and product versions to match Cargo version.

## v0.1.3 - 2025-11-24

### Fixed

- Panic (crash) when analyzing a Fire with a debug probe.  Moved to fork of probe-rs with fix for panic.
- Allow multi-rom sets to be built
- Statically link with vcruntime

## v0.1.2 - 2025-11-09

- Built with rustc 1.91
- Move to probe-rs 0.30
- Added ability to load ROM config JSON files from disk in Create view
- Added online manifest to access latest URLs, with local cache file backup, and defaults as further backup
- Added app version update check and download link

## v0.1.1 - 2025-10-30

- Built with rustc 1.90
- Mac and Windows releases now signed.
- Mac app now uses the One ROM liquid glass icon.
- Moved to libusb-less DFU implementation using `dfu-rs` and `nusb` crates.
- Moved to manual rescanning to detect probes and USB devices.
- Added network connectivity icon.
- Single universal macOS dmg installer instead of separate Intel and Apple Silicon versions.
- Added ability to load ROM config JSON files from disk in Create view.

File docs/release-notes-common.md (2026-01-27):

# One ROM - Release Notes

The most flexible ROM replacement for your retro computer.

## Changes In This Release

[CHANGELOG_PLACEHOLDER]

## Quick Start

Use [One ROM Studio](https://onerom.org/studio) to configure and build custom firmware images for your One ROM.

Alternatively, download pre-built firmware images from the releases below.

## File Types

- **onerom-{hw-rev}-{mcu}-{rom-config}.bin** - Single binary file for a specific hardware revision, MCU variant and ROM configuration, ready to flash
- **onerom-{hw-rev}-{mcu}.zip** - Zip of binaries for a specific hardware revision and MCU variant, ready to flash
- **manifest.json** - JSON manifest file listing all available firmware images, their hardware and ROM configurations, and SHA256 checksums, for use by automated tooling.

## Supported Configurations

Each zip firmware with a selection of ROM images for multiple system configurations, including:

- C64
- VIC-20 PAL  
- PET
- Commodore 1541 disk drive
- IEEE disk drives
- And more...

Firmware for ROM image configurations that require explicit licence acceptance (for example ['c64'](/old-config/c64.mk)) are not included in the release.  You can build them yourself, by following instructions in the [README](/README.md) and [INSTALL](/INSTALL.md).

There are more hardware, MCU and other build configurations options supported by One ROM than are included in the release artifacts.  You can build them yourself, by following instructions in the [README](/README.md) and [INSTALL](/INSTALL.md).

## Installation

1. Download the appropriate **.bin** for your hardware and desired ROM configuration
2. Flash the desired binary to your One ROM
3. Install One ROM into your retro computer

## Support

For documentation, hardware setup guides, and support:

- GitHub: [Project](https://piers.rocks/u/one)
- YouTube: [@piers.rocks](https://www.youtube.com/@piers_rocks)

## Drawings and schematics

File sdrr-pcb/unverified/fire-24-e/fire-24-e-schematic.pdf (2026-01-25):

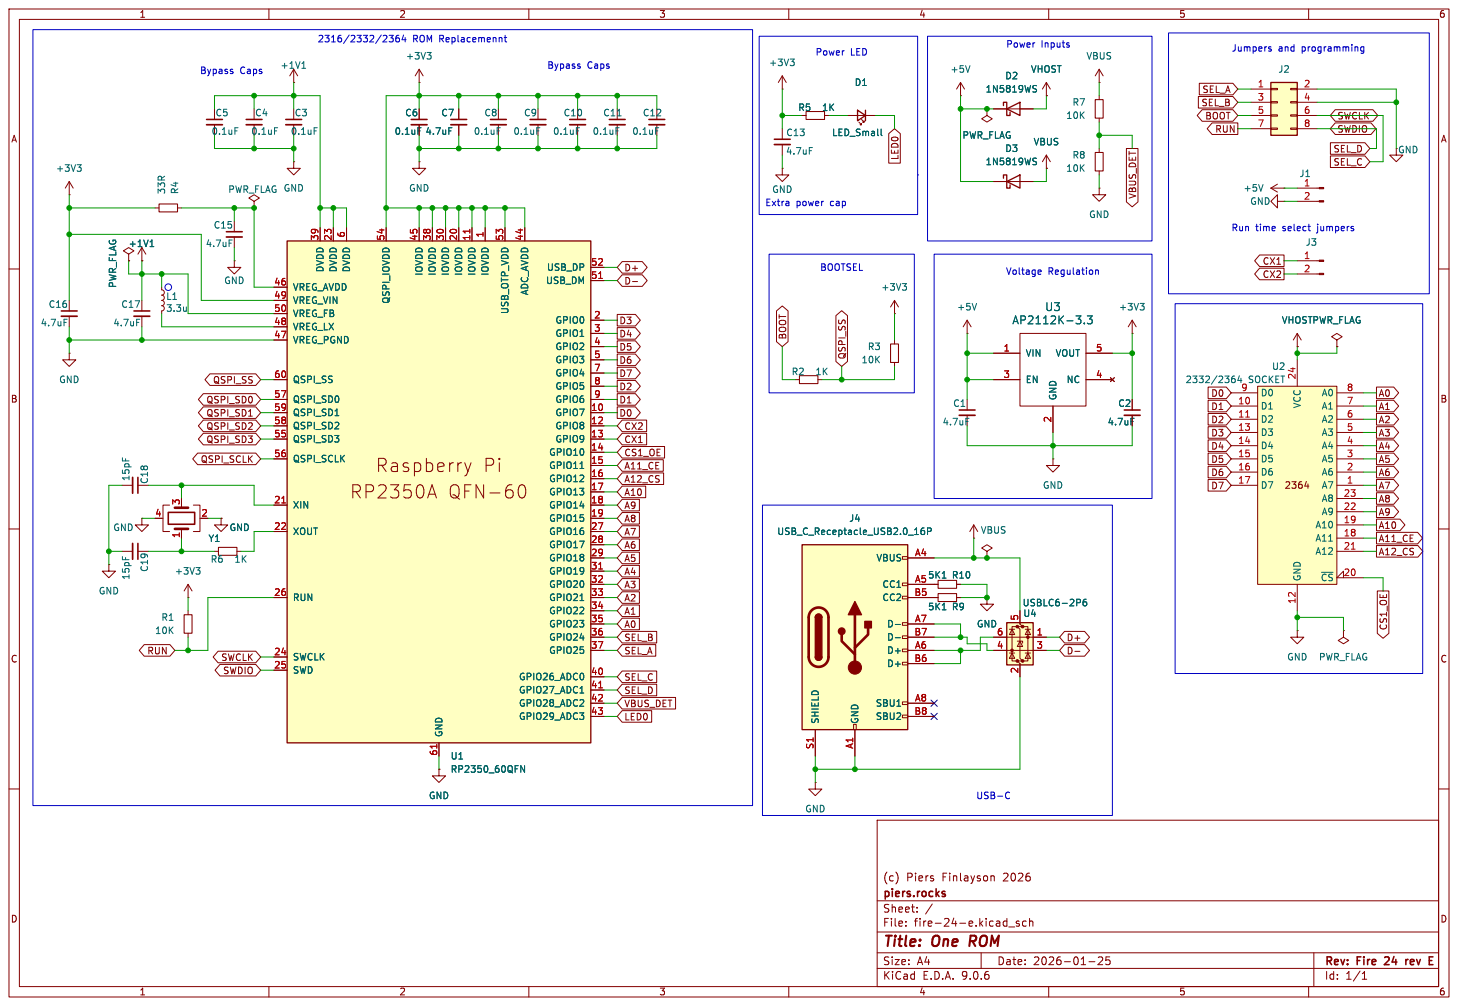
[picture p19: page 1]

Run time select jumpers

6 QSPI_IOVDD 54 IOVDD 45 IOVDD 38 GND 61 IOVDD 30 IOVDD 20 IOVDD 11 IOVDD

File: fire-24-e.kicad_sch Sheet: / piers.rocks

Id: 1/1 Title: One ROM

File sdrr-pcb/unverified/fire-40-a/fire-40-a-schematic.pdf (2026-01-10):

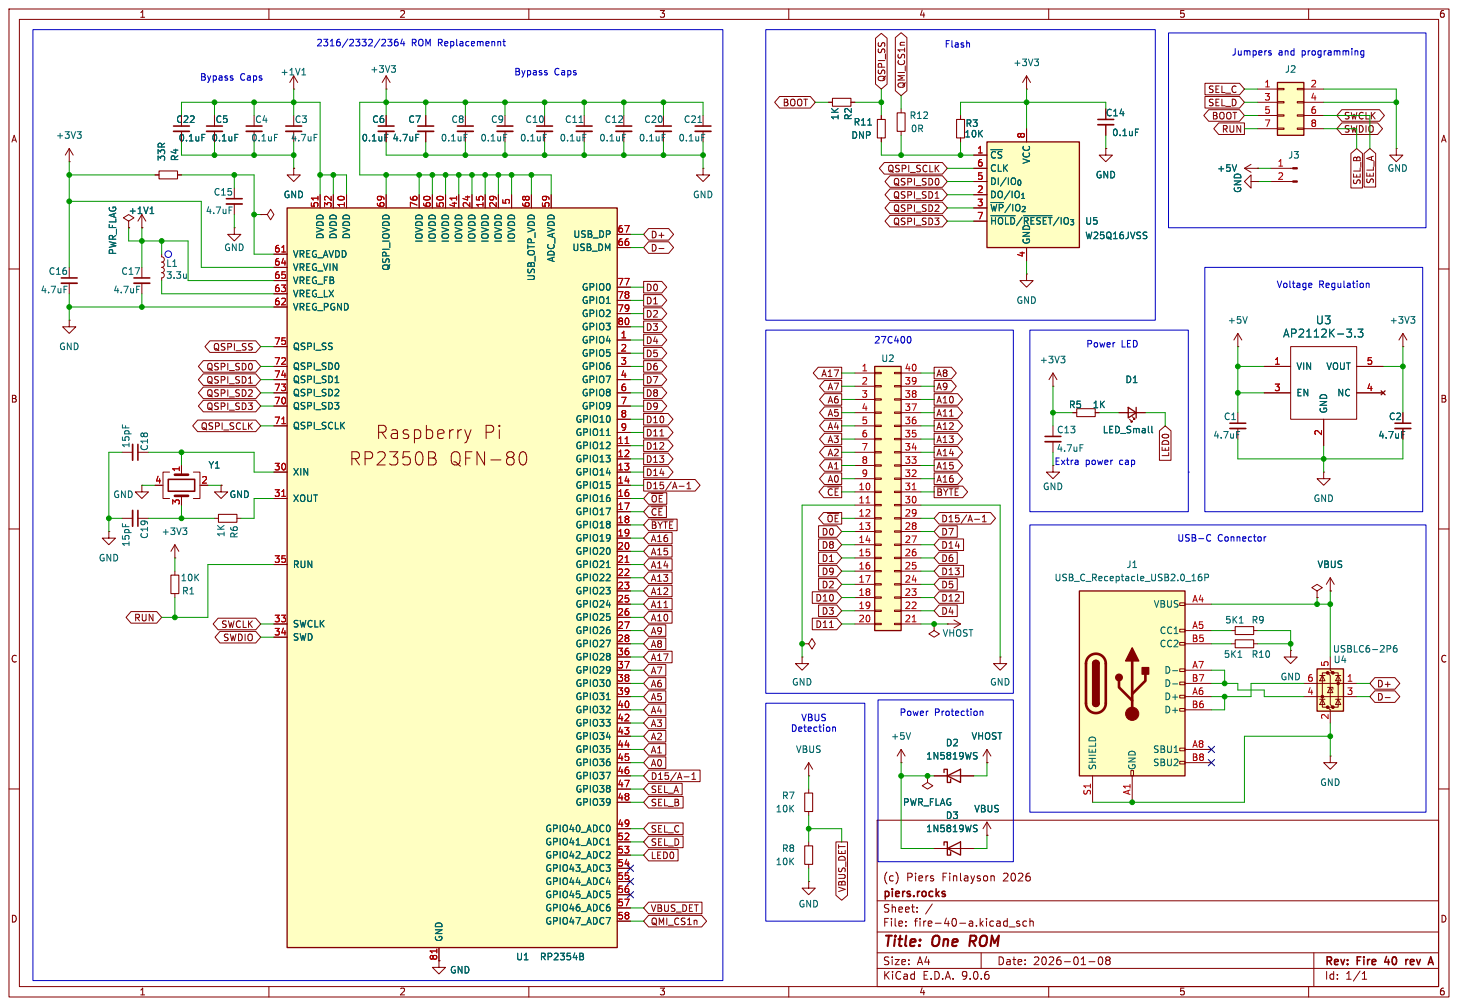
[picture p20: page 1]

2 VOUT 5 NC 4 VBUS GND

File: fire-40-a.kicad_sch Sheet: / piers.rocks

Id: 1/1 Title: One ROM

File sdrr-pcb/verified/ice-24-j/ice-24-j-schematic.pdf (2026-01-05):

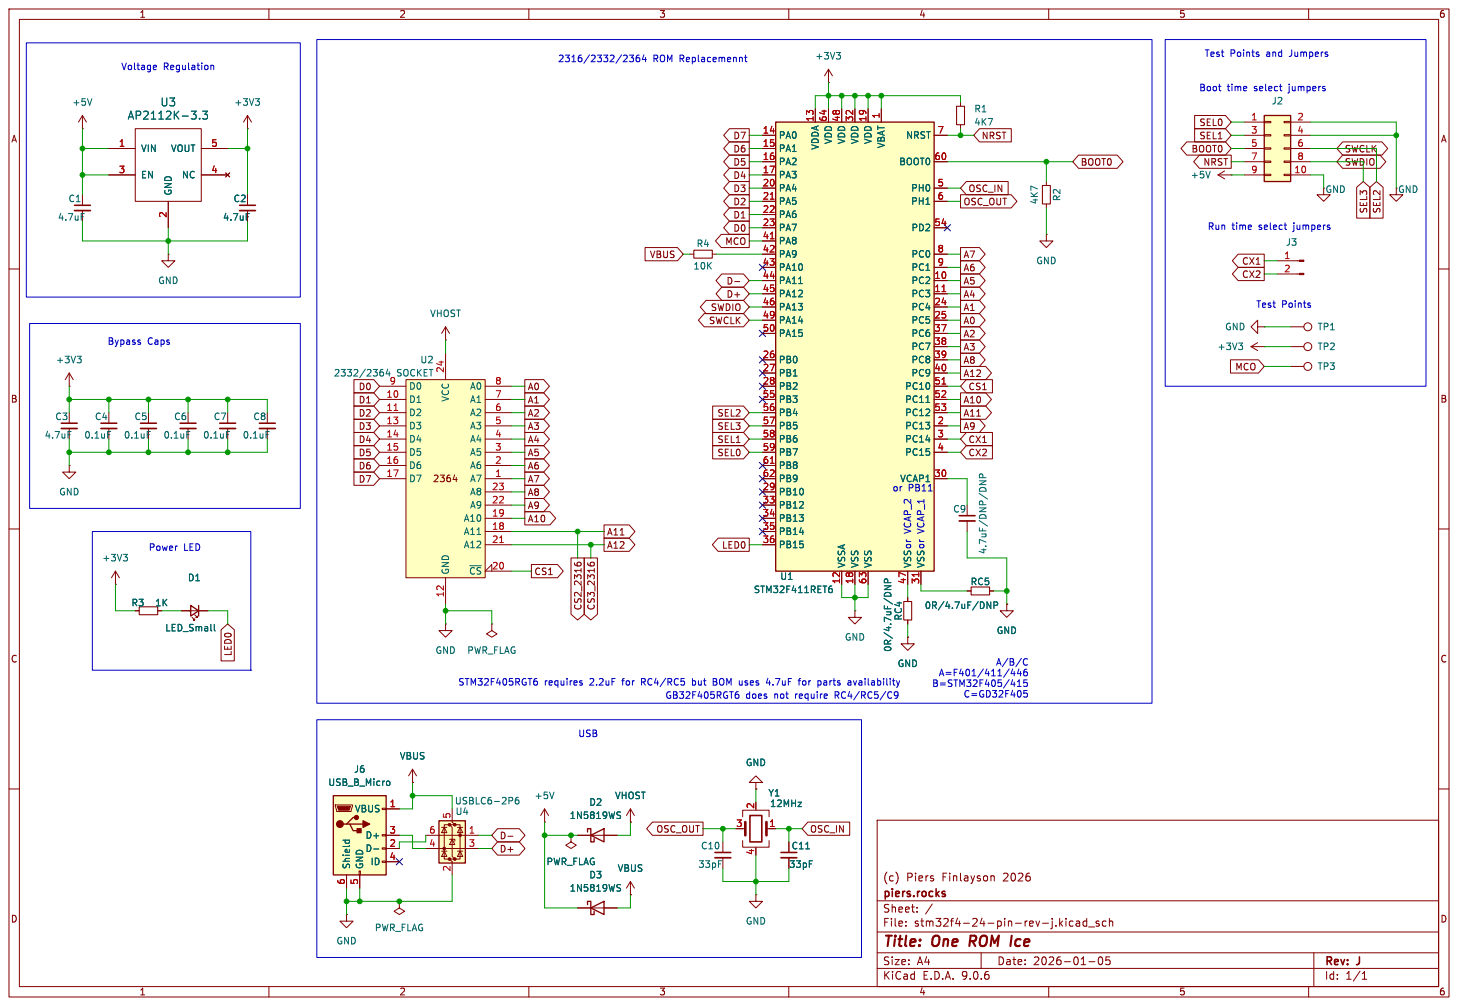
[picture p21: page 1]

Test Points and Jumpers Boot time select jumpers Run time select jumpers GB32F405RGT6 does not require RC4/RC5/C9 D3
D5 D7 D4 D3 D1 D2 D+ SWDIO

1 VDD 19 VSS 63 VDD 32 VSS 18 VDD 48 VSSA 12 VDD 64 VDDA 13 PA0 14 PA1 15 PA2 16 PA3 17 PA4 20 PA5 21 PA6 22 PA7 23 PA8 41 PA9 42 PA10 43 PA11 44 PA12 45 PA13 46 PA14 49 PA15 50 PB0 26 PB1 27 PB2 28 PB3 55 PB4 56 PB5 57 PB6 58 PB7 59 PB8 61 PB9 62 PB10 29 PB12 33 PB13 34 PB14 35 PB15 36 U1 STM32F411RET6 GND

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

A=F401/411/446 B=STM32F405/415 C=GD32F405 STM32F405RGT6 requires 2.2uF for RC4/RC5 but BOM uses 4.7uF for parts availability

File: stm32f4-24-pin-rev-j.kicad_sch Sheet: / piers.rocks

Id: 1/1 Title: One ROM Ice

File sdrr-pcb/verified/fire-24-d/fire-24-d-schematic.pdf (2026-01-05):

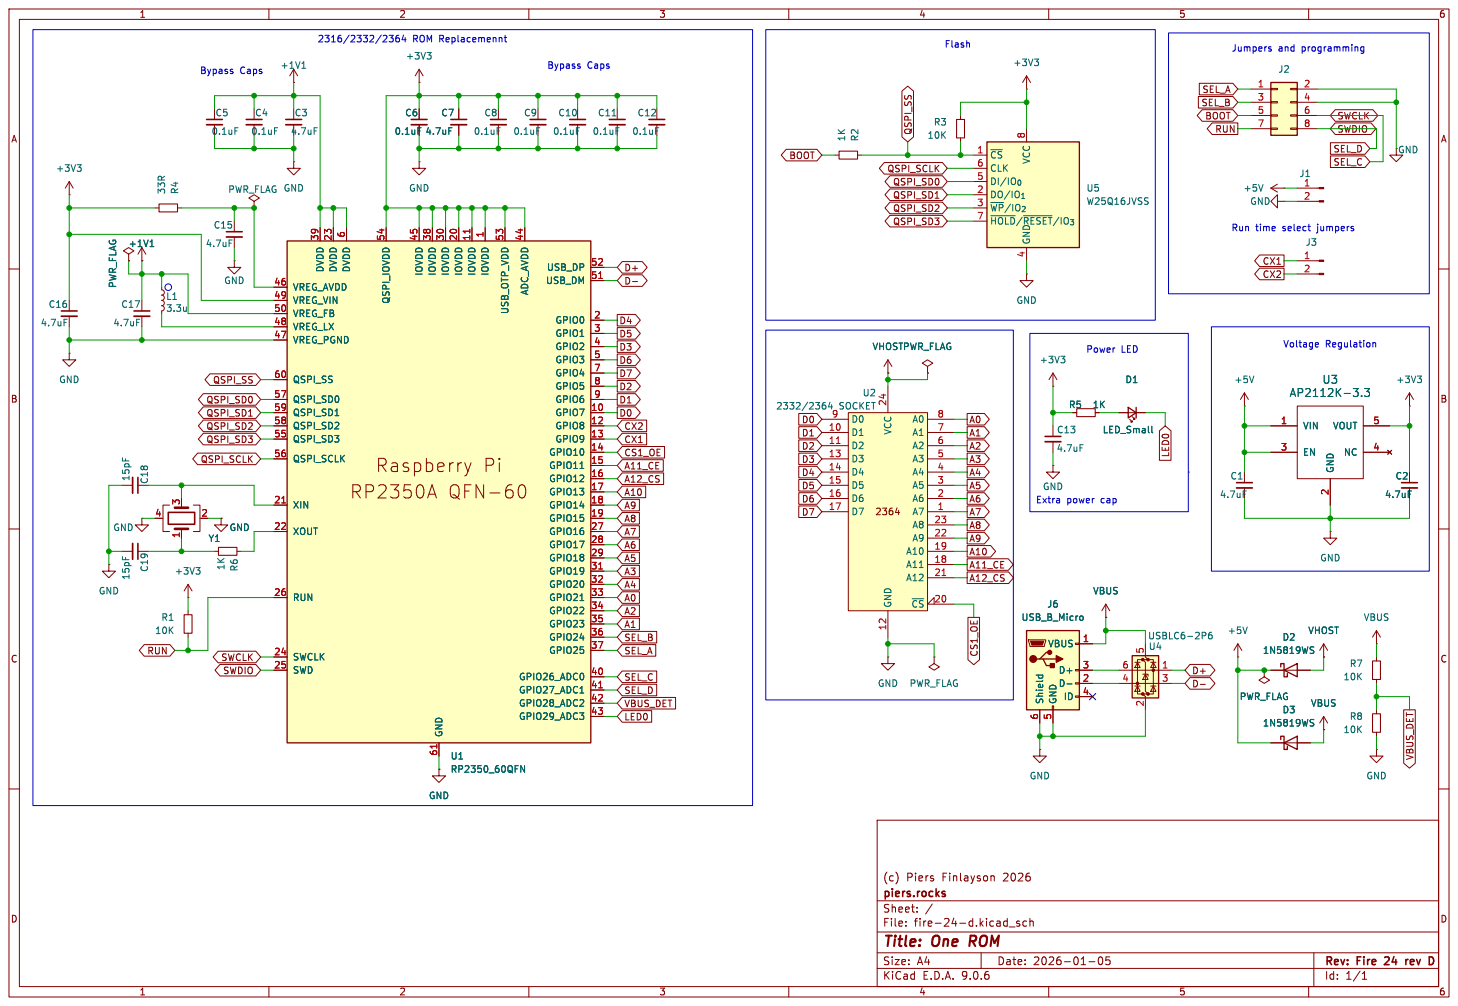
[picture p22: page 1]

6 QSPI_IOVDD 54 IOVDD 45 IOVDD 38 GND 61 IOVDD 30 IOVDD 20 IOVDD 11 IOVDD

File: fire-24-d.kicad_sch Sheet: / piers.rocks

Id: 1/1 Title: One ROM

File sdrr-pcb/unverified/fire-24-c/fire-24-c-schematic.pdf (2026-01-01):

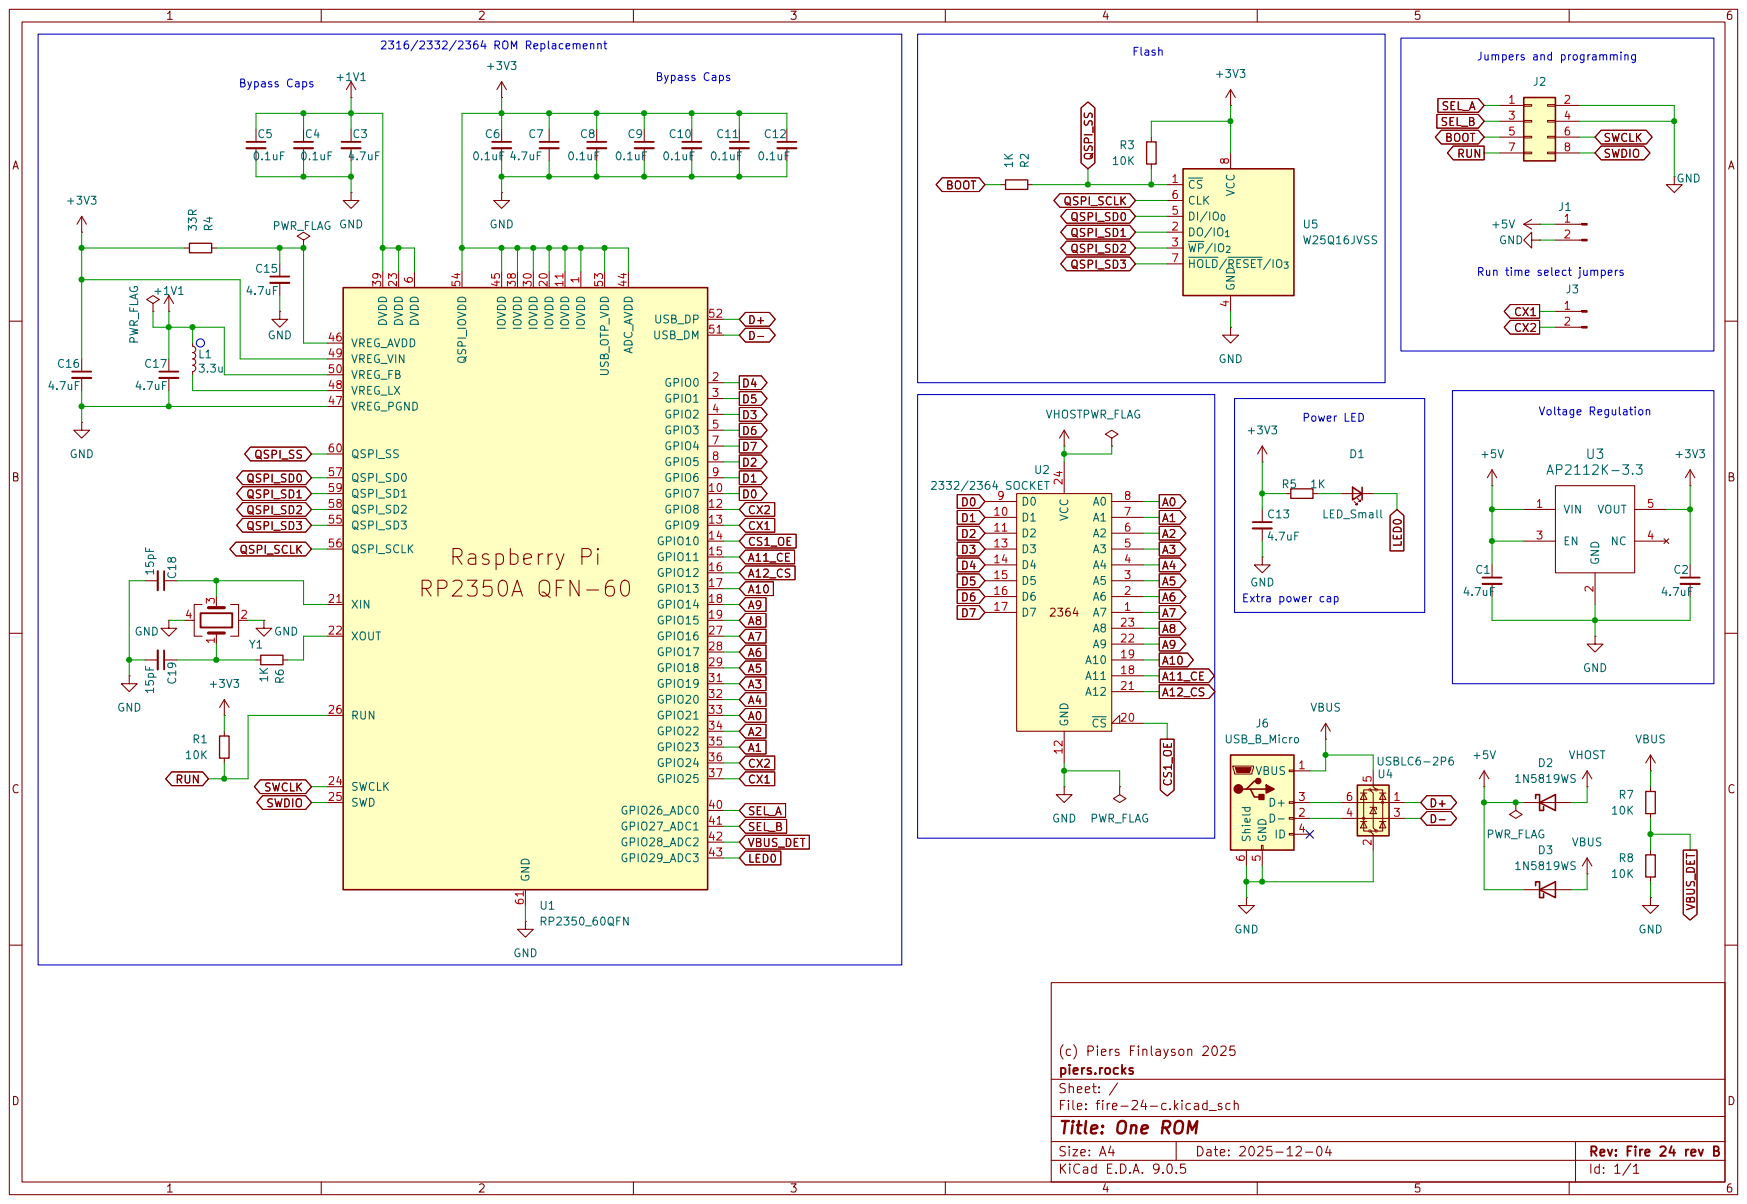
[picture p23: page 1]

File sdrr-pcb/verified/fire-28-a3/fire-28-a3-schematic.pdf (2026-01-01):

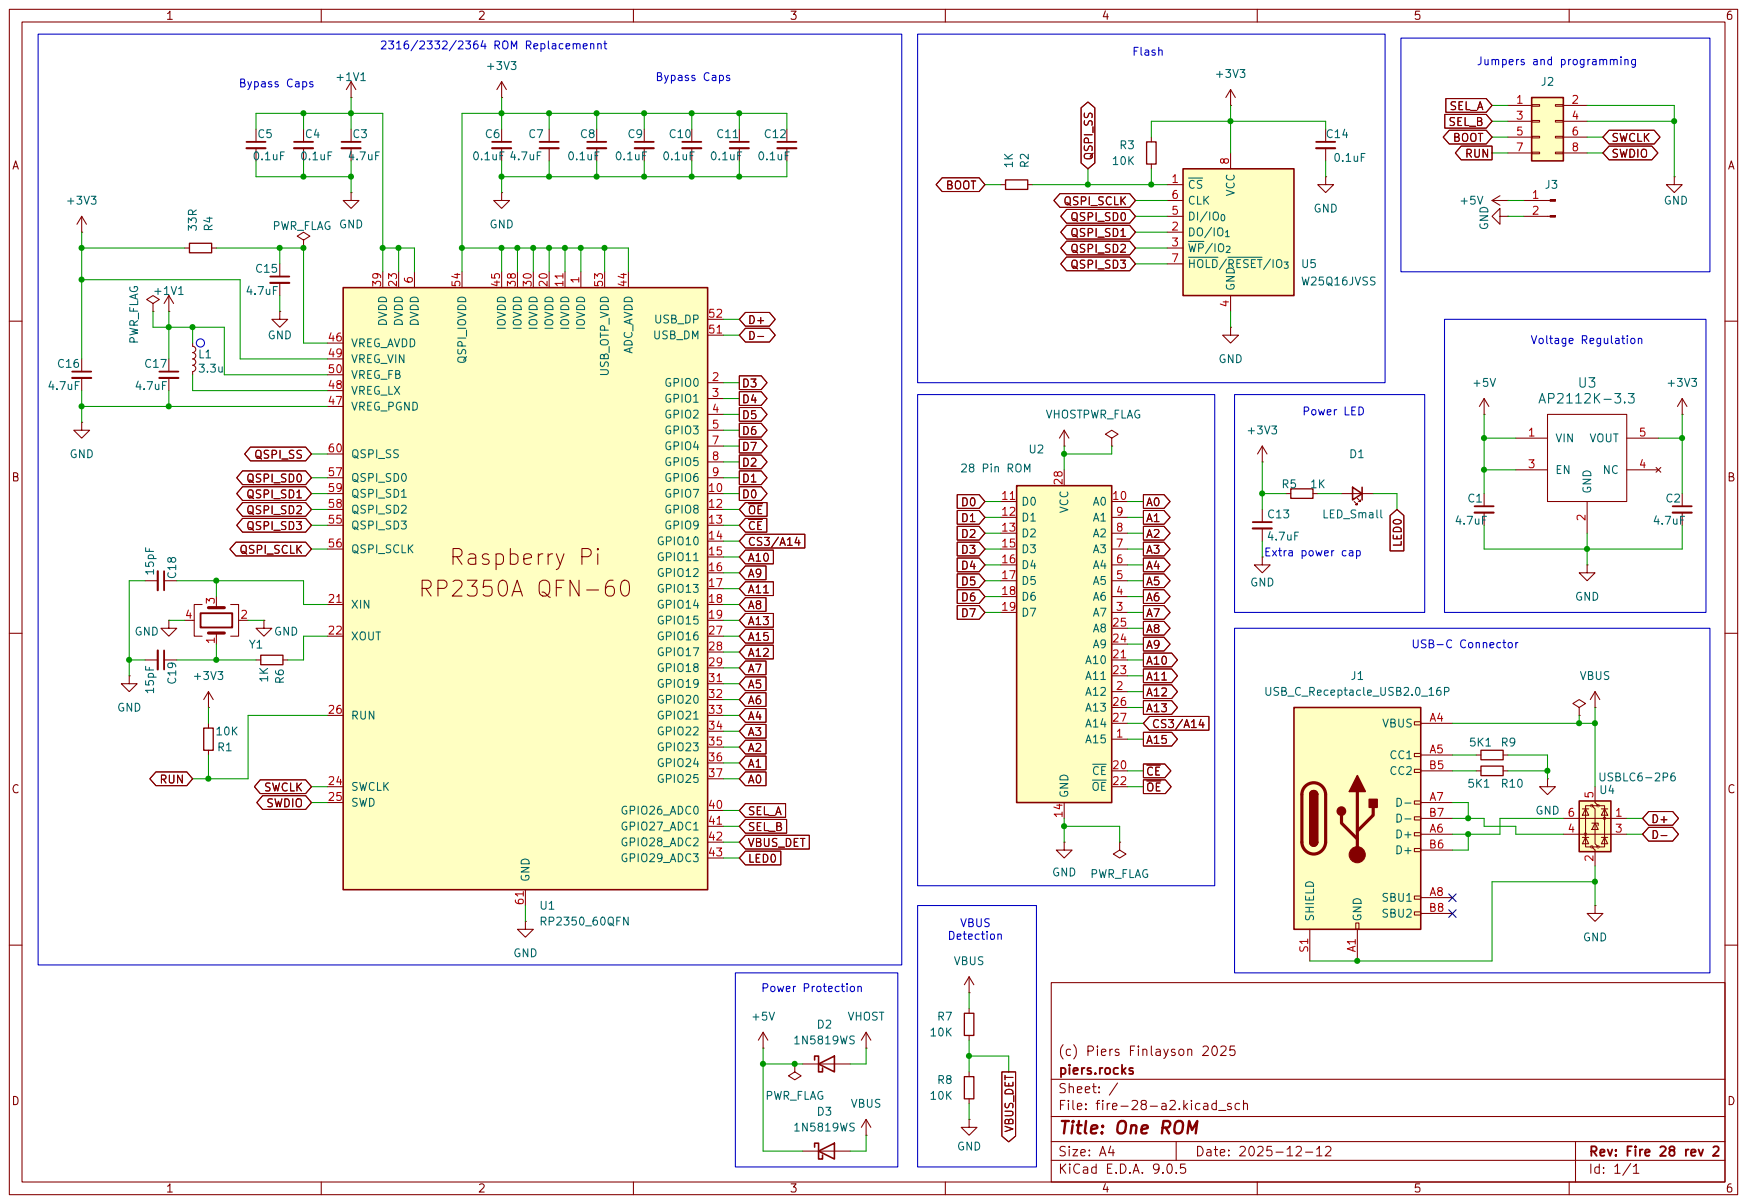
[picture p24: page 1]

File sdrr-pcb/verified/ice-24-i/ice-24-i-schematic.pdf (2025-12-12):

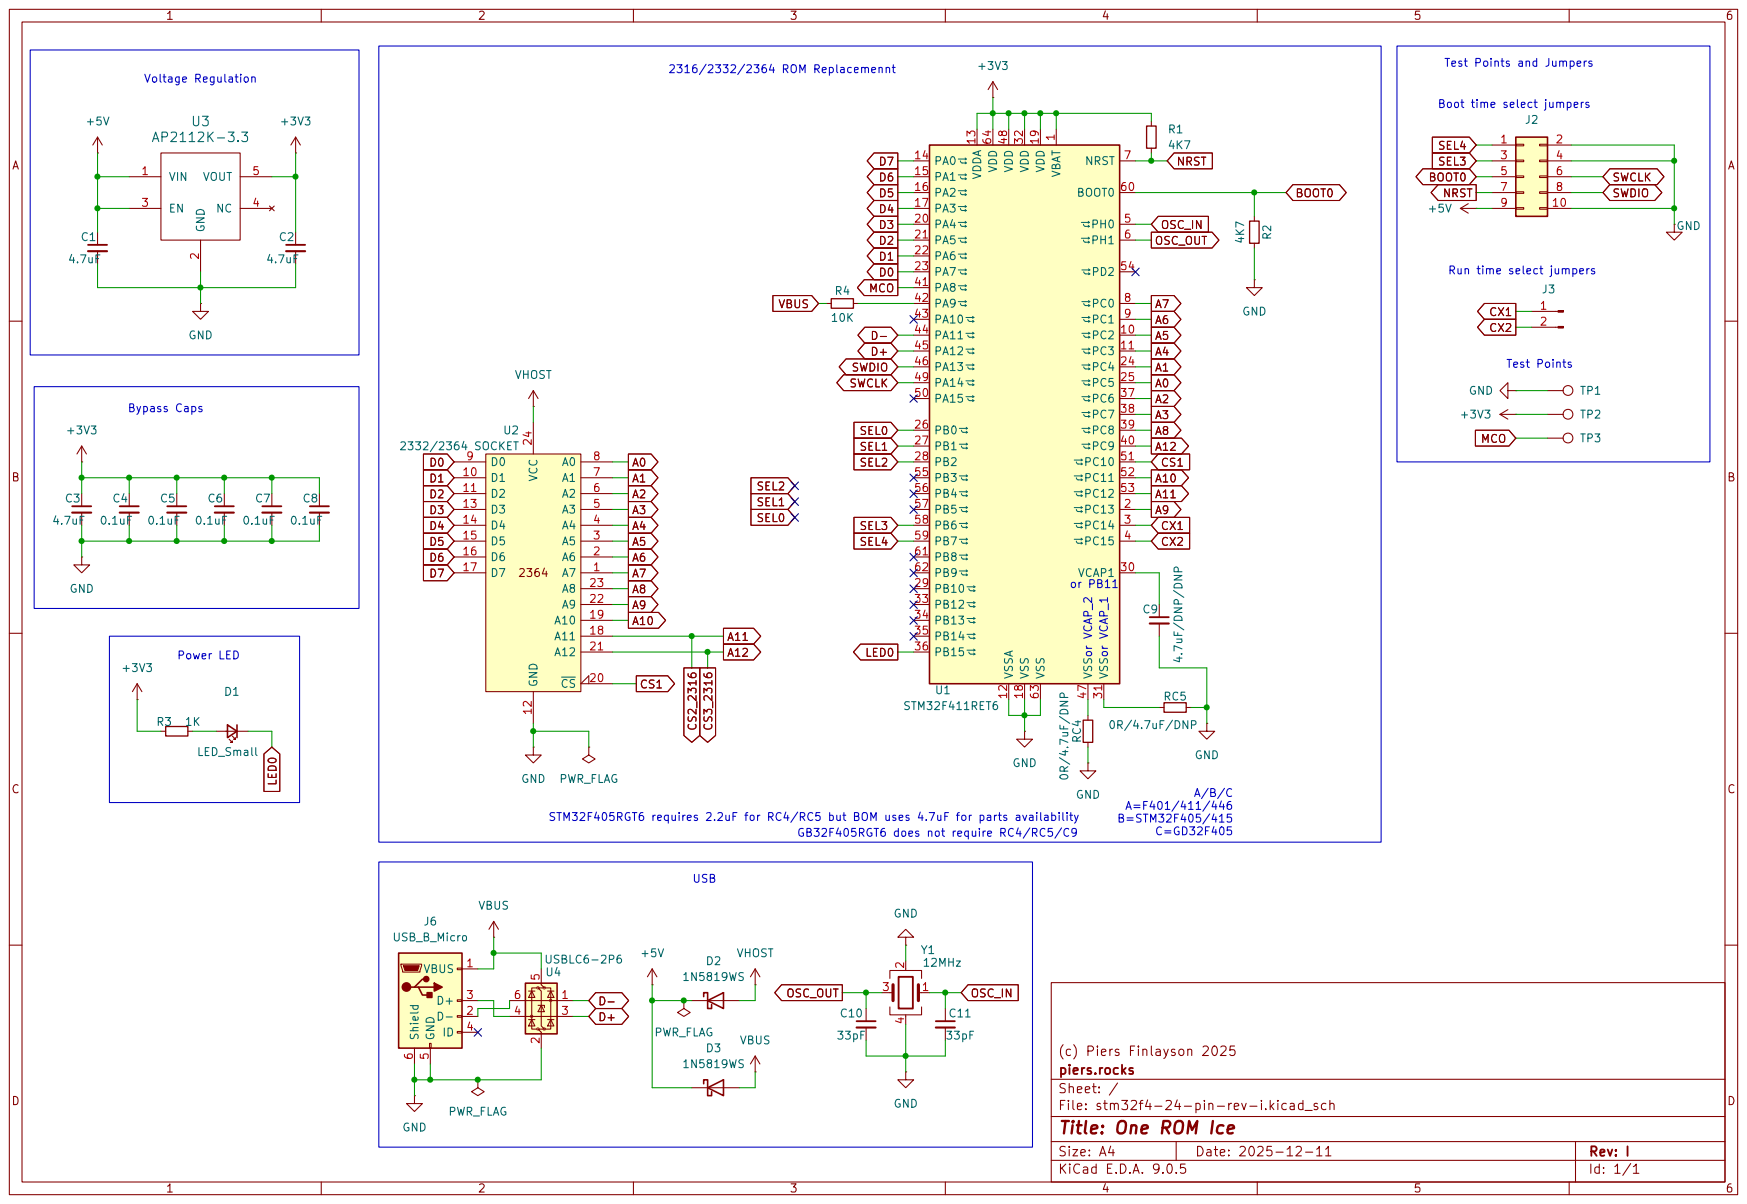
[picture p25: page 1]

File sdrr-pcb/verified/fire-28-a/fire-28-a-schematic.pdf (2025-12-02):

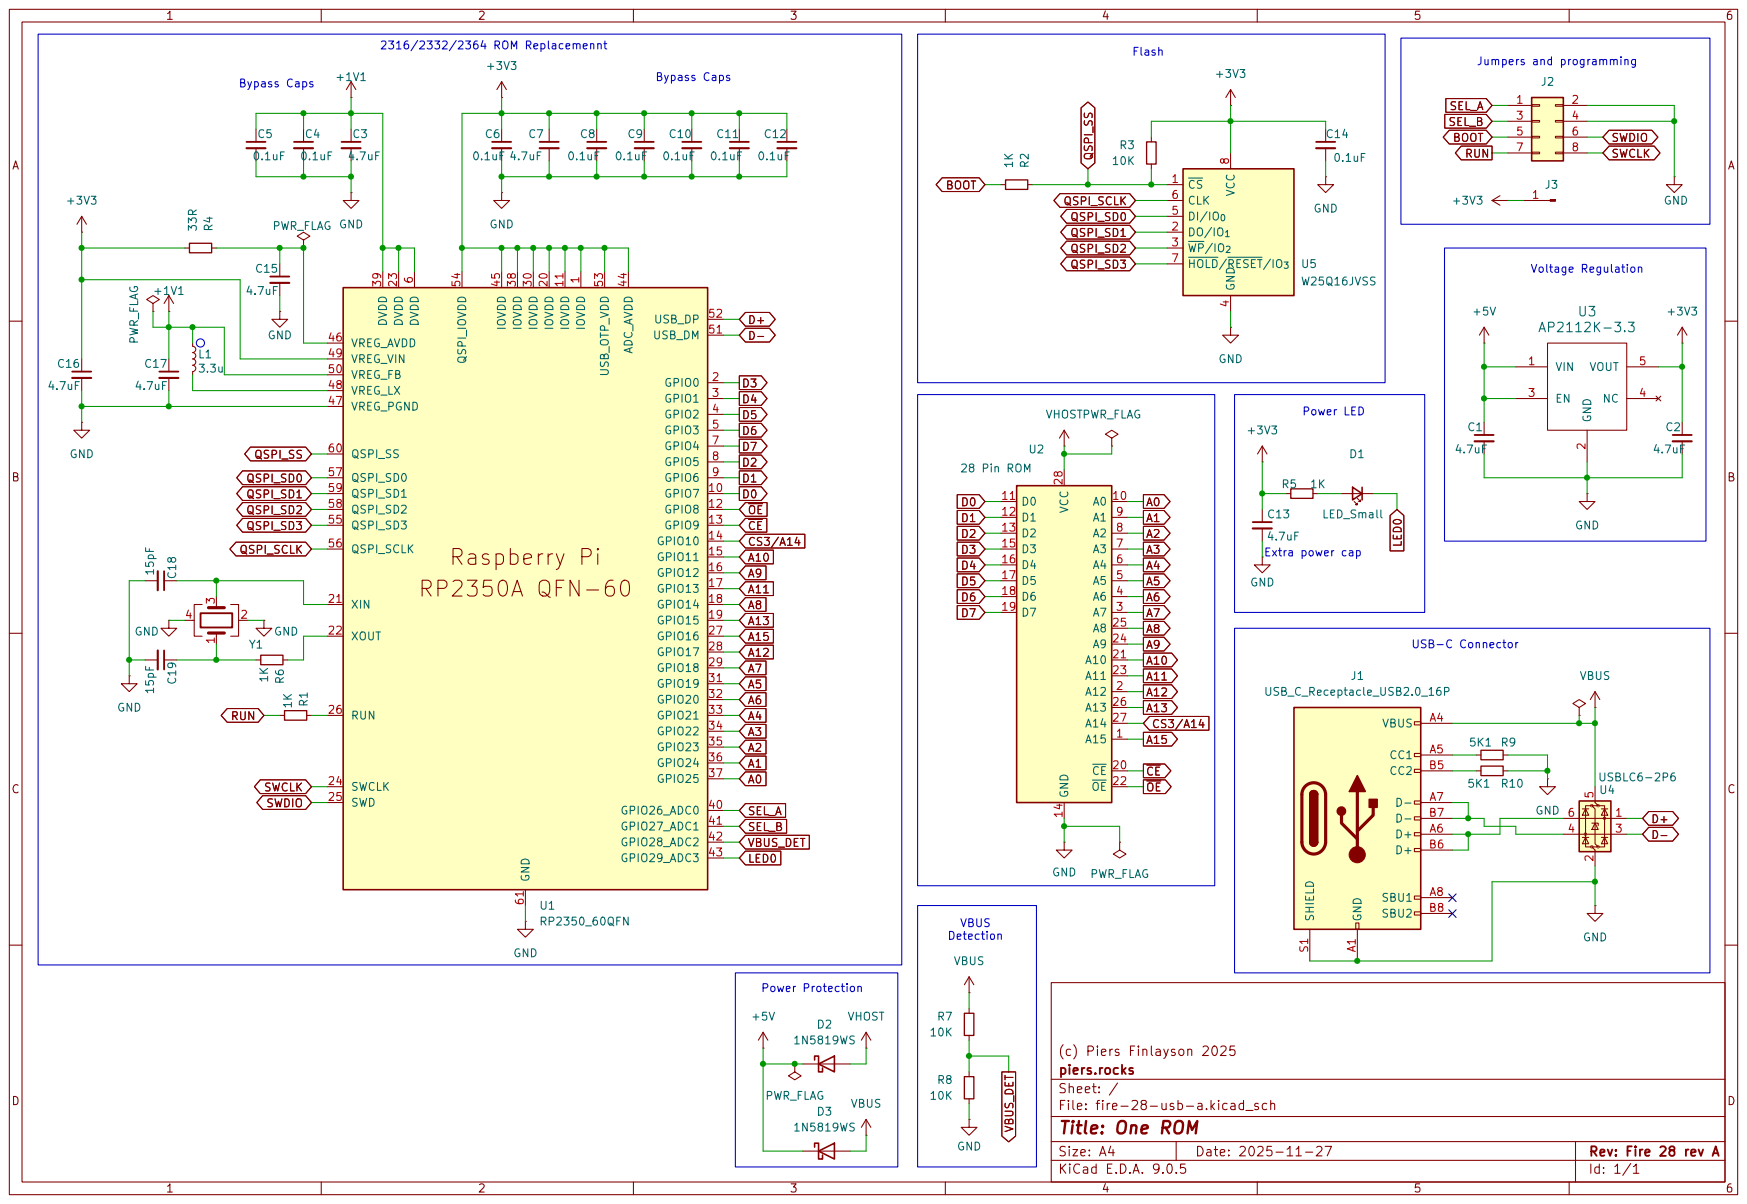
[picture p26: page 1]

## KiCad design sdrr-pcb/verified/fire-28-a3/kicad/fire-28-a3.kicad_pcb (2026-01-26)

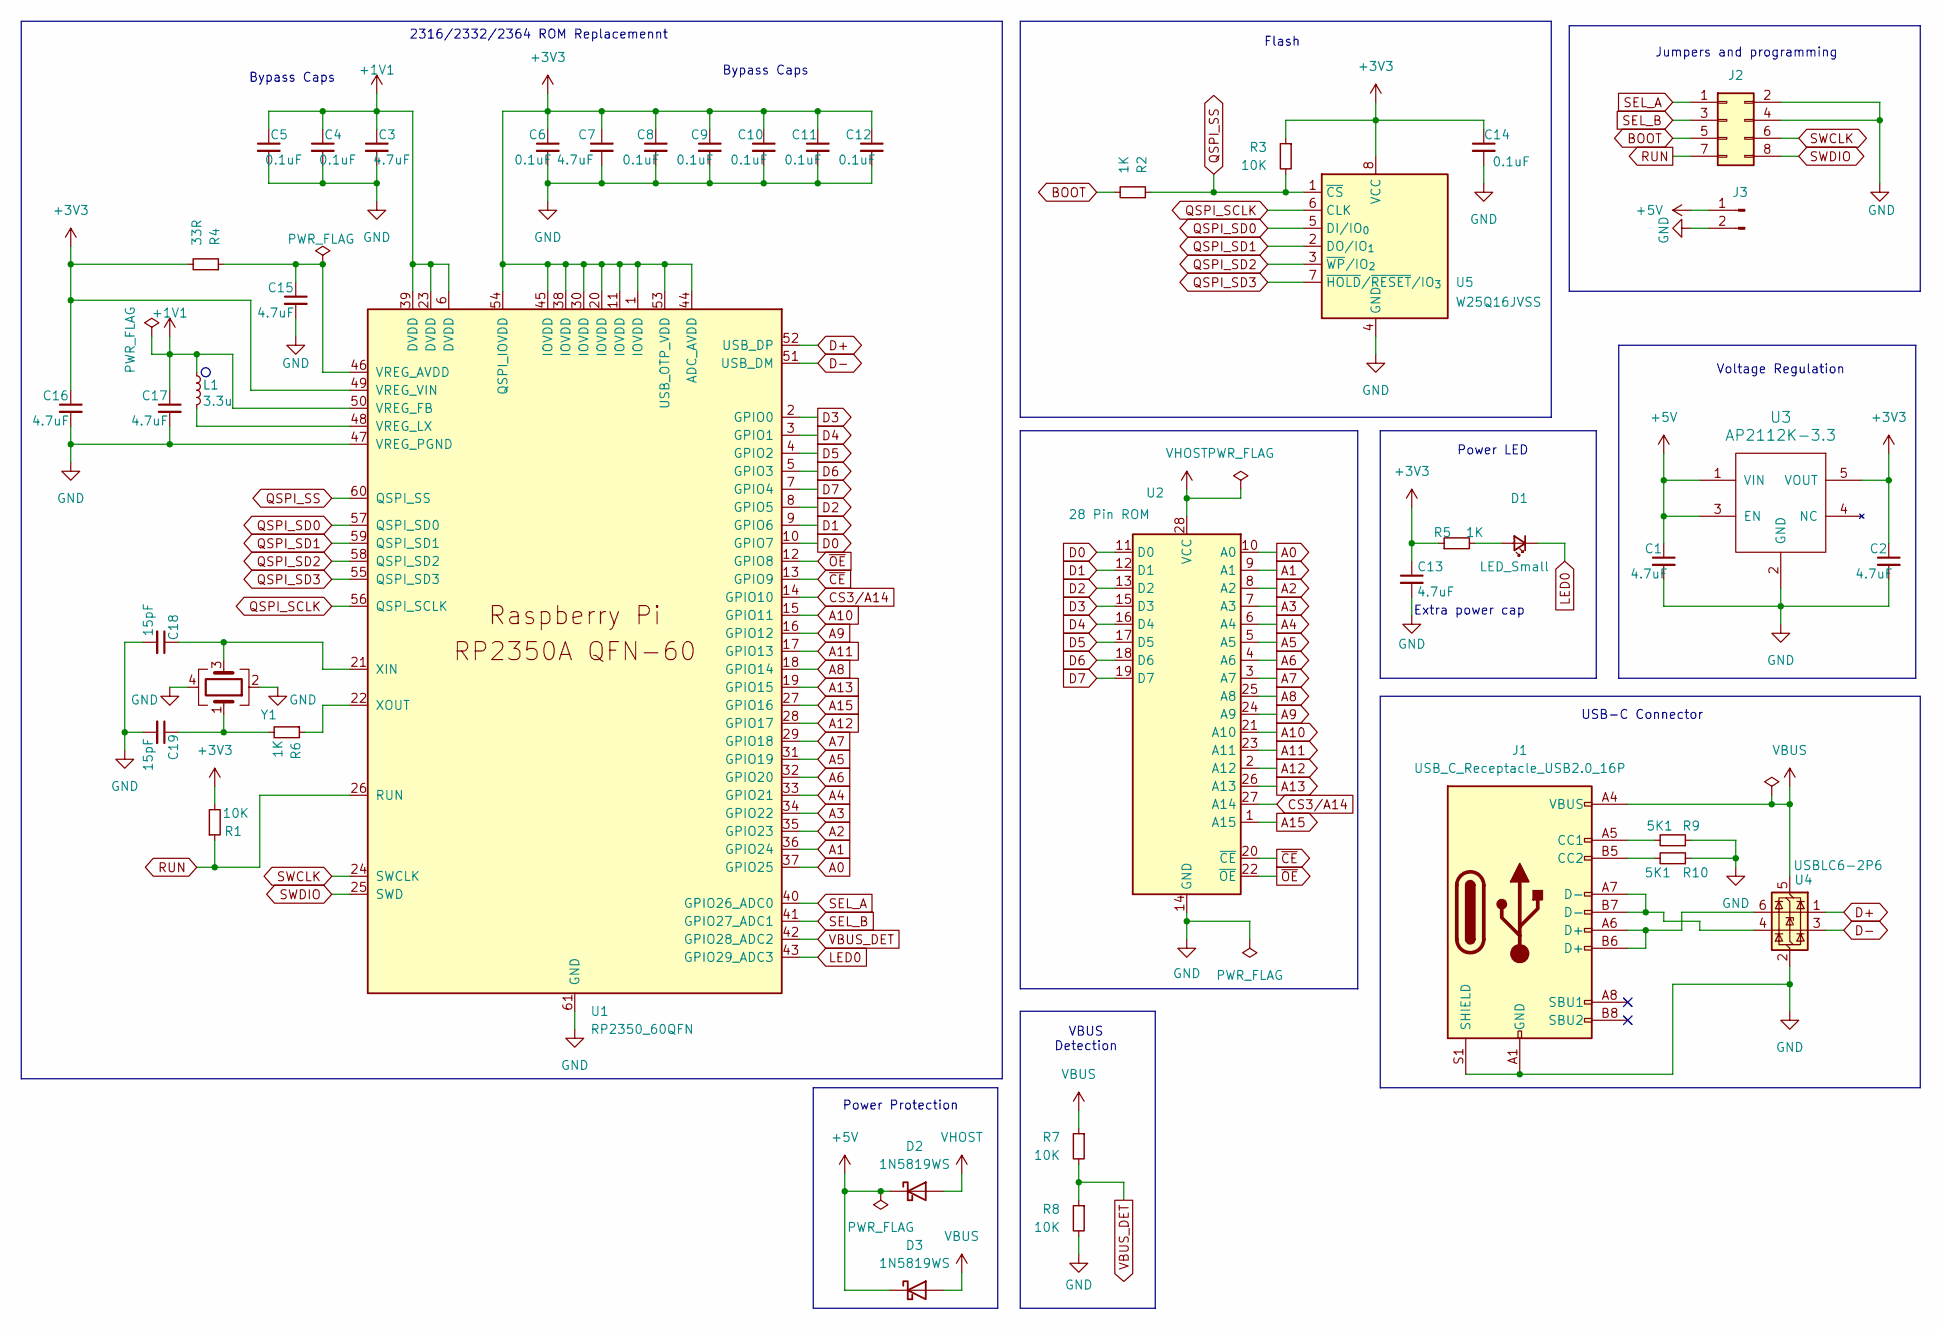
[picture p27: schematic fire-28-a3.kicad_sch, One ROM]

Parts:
C1, C2, C3, C7, C13, C15: 4.7uF; C_0402_1005Metric; LCSC C23733
C4, C5, C6, C8, C9, C10, C11, C12, C14: 0.1uF; C_0402_1005Metric; LCSC C1525
C16, C17: 4.7uF; C_0402_1005Metric_small_pads; LCSC C23733
C18, C19: 15pF; C_0402_1005Metric; LCSC C1548
D1: LED_Small; LED_0603_1608Metric; LCSC C2286
D2, D3: 1N5819WS; D_SOD-323; LCSC C191023
J1: USB_C_Receptacle_USB2.0_16P; USB_C_connector_c2765186; LCSC C2765186
J2: Conn_02x04_Odd_Even; PinHeader_2x04_P2.54mm_Vertical custom silkscreen
J3: Conn_01x02_Pin; PinHeader_1x02_P2.54mm_Vertical
L1: 3.3u; L_pol_2016; LCSC C42411119
R1, R3, R7, R8: 10K; R_0402_1005Metric; LCSC C25744
R2, R5, R6: 1K; R_0402_1005Metric; LCSC C11702
R4: 33R; R_0402_1005Metric; LCSC C25105
R9, R10: 5K1; R_0402_1005Metric; LCSC C25905
U1: RP2350_60QFN; RP2350-QFN-60-1EP_7x7_P0.4mm_EP3.4x3.4mm_ThermalVias; LCSC C42411118
U2: 28 Pin ROM; 28 pin rom footprint
U3: AP2112K-3.3; SOT-23-5; LCSC C51118
U4: USBLC6-2P6; SOT-666; LCSC C15999
U5: W25Q16JVSS; Winbond_USON-8-1EP_3x2mm_P0.5mm_EP0.2x1.6mm; LCSC C2843335
Y1: Crystal_GND24; Crystal_SMD_Abracon_ABM8G-4Pin_3.2x2.5mm; LCSC C20625731

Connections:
+1V1: C3.1, C4.1, C5.1, C17.1, L1.1, U1.6 (DVDD), U1.23 (DVDD), U1.39 (DVDD), U1.50 (VREG_FB)
+3V3: C2.1, C6.1, C7.1, C8.1, C9.1, C10.1, C11.1, C12.1, C13.1, C14.1, C16.1, R1.2, R3.1, R4.2, R5.1, U1.1 (IOVDD), U1.11 (IOVDD), U1.20 (IOVDD), U1.30 (IOVDD), U1.38 (IOVDD), U1.44 (ADC_AVDD), U1.45 (IOVDD), U1.49 (VREG_VIN), U1.53 (USB_OTP_VDD), U1.54 (QSPI_IOVDD), U3.5 (VOUT), U5.8 (VCC)
+5V: C1.1, D2.1 (K), D3.1 (K), J3.1, U3.1 (VIN), U3.3 (EN)
A0: U1.37 (GPIO25), U2.10 (A0)
A1: U1.36 (GPIO24), U2.9 (A1)
A2: U1.35 (GPIO23), U2.8 (A2)
A3: U1.34 (GPIO22), U2.7 (A3)
A4: U1.33 (GPIO21), U2.6 (A4)
A5: U1.31 (GPIO19), U2.5 (A5)
A6: U1.32 (GPIO20), U2.4 (A6)
A7: U1.29 (GPIO18), U2.3 (A7)
A8: U1.18 (GPIO14), U2.25 (A8)
A9: U1.16 (GPIO12), U2.24 (A9)
A10: U1.15 (GPIO11), U2.21 (A10)
A11: U1.17 (GPIO13), U2.23 (A11)
A12: U1.28 (GPIO17), U2.2 (A12)
A13: U1.19 (GPIO15), U2.26 (A13)
A15: U1.27 (GPIO16), U2.1 (A15)
BOOT: J2.5, R2.2
CS3/A14: U1.14 (GPIO10), U2.27 (A14)
D0: U1.10 (GPIO7), U2.11 (D0)
D1: U1.9 (GPIO6), U2.12 (D1)
D2: U1.8 (GPIO5), U2.13 (D2)
D3: U1.2 (GPIO0), U2.15 (D3)
D4: U1.3 (GPIO1), U2.16 (D4)
D5: U1.4 (GPIO2), U2.17 (D5)
D6: U1.5 (GPIO3), U2.18 (D6)
D7: U1.7 (GPIO4), U2.19 (D7)
D+: U1.52 (USB_DP), U4.1 (I/O1)
D-: U1.51 (USB_DM), U4.3 (I/O2)
GND: C1.2, C2.2, C3.2, C4.2, C5.2, C6.2, C7.2, C8.2, C9.2, C10.2, C11.2, C12.2, C13.2, C14.2, C15.2, C16.2, C17.2, C18.2, C19.2, J1.A1 (GND), J1.A12 (GND), J1.B1 (GND), J1.B12 (GND), J1.S1 (SHIELD), J2.2, J2.4, J3.2, R8.2, R9.1, R10.1, U1.47 (VREG_PGND), U1.61 (GND), U2.14 (GND), U3.2 (GND), U4.2 (GND), U5.4 (GND), Y1.2, Y1.4
LED0: D1.1 (K), U1.43 (GPIO29_ADC3)
unnamed: C19.1, R6.2, Y1.1
unnamed: D1.2 (A), R5.2
unnamed: J1.A5 (CC1), R9.2
unnamed: J1.B5 (CC2), R10.2
unnamed: J1.A6 (D+), J1.B6 (D+), U4.6 (I/O1)
unnamed: J1.A7 (D-), J1.B7 (D-), U4.4 (I/O2)
unnamed: C15.1, R4.1, U1.46 (VREG_AVDD)
unnamed: L1.2, U1.48 (VREG_LX)
unnamed: C18.1, U1.21 (XIN), Y1.3
unnamed: R6.1, U1.22 (XOUT)
QSPI_SCLK: U1.56 (QSPI_SCLK), U5.6 (CLK)
QSPI_SD0: U1.57 (QSPI_SD0), U5.5 (DI/IO_{0})
QSPI_SD1: U1.59 (QSPI_SD1), U5.2 (DO/IO_{1})
QSPI_SD2: U1.58 (QSPI_SD2), U5.3 (~WP/IO_{2})
QSPI_SD3: U1.55 (QSPI_SD3), U5.7 (~HOLD/~RESET/IO_{3})
QSPI_SS: R2.1, R3.2, U1.60 (QSPI_SS), U5.1 (~CS)
RUN: J2.7, R1.1, U1.26 (RUN)
SEL_A: J2.1, U1.40 (GPIO26_ADC0)
SEL_B: J2.3, U1.41 (GPIO27_ADC1)
SWCLK: J2.6, U1.24 (SWCLK)
SWDIO: J2.8, U1.25 (SWD)
VBUS: D3.2 (A), J1.A4 (VBUS), J1.A9 (VBUS), J1.B4 (VBUS), J1.B9 (VBUS), R7.1, U4.5 (VBUS)
VBUS_DET: R7.2, R8.1, U1.42 (GPIO28_ADC2)
VHOST: D2.2 (A), U2.28 (VCC)
~CE: U1.13 (GPIO9), U2.20 (~CE)
~OE: U1.12 (GPIO8), U2.22 (~OE)

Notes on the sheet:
USB-C Connector
Voltage Regulation
Extra power cap
2316/2332/2364 ROM Replacemennt
Bypass Caps
Power LED
Power Protection
VBUS Detection
Flash
Jumpers and programming

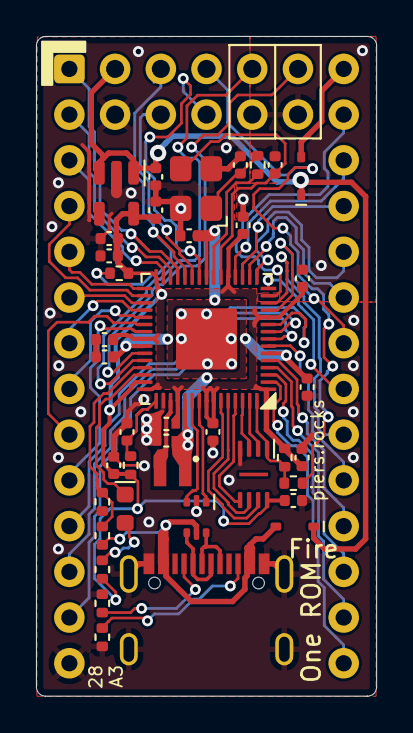
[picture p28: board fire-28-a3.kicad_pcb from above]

Board: 2 copper layers, 18.9 x 36.7 mm, 42 parts (0 on the bottom side), 58 nets.

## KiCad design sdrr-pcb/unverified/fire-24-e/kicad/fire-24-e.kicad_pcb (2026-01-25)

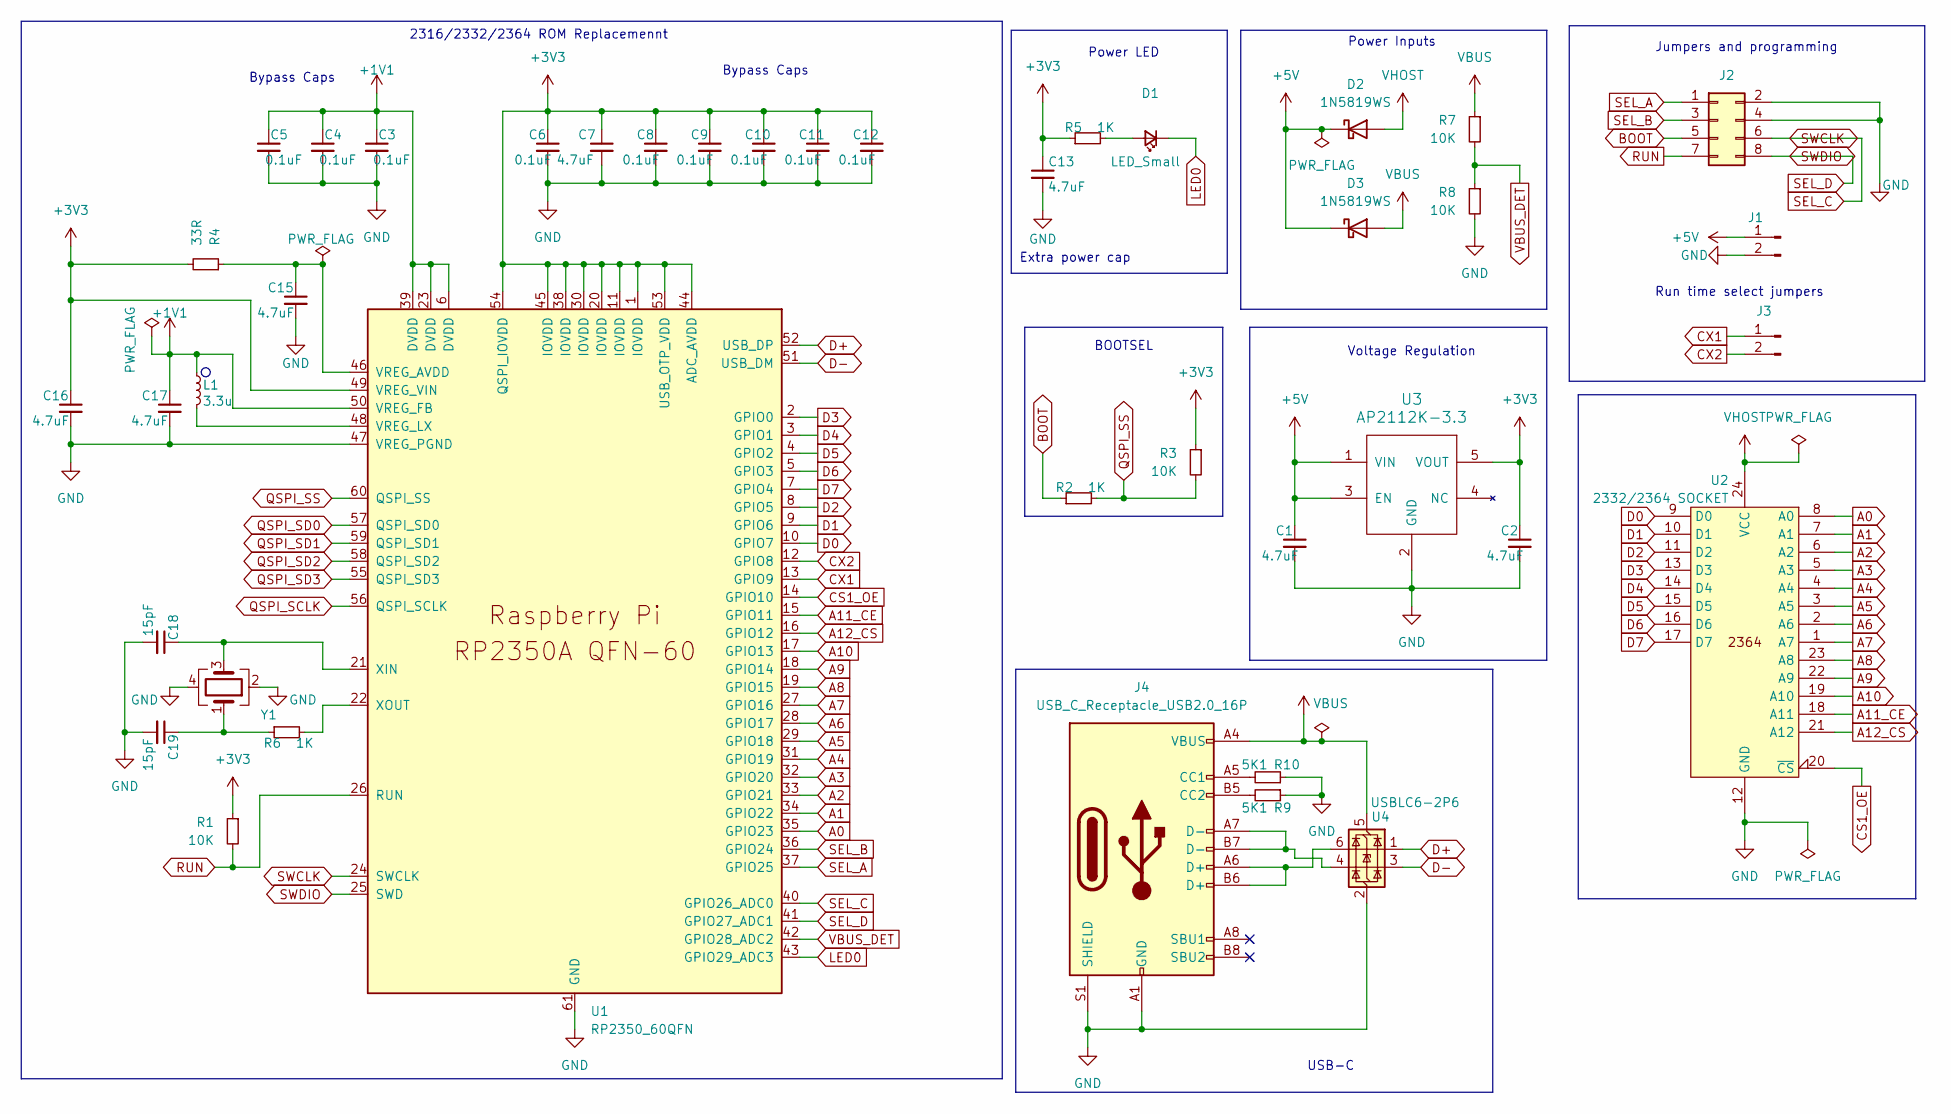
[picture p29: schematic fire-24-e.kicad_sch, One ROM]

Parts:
C1, C2, C7, C13, C15: 4.7uF; C_0402_1005Metric; LCSC C23733
C3, C4, C5, C6, C8, C9, C10, C11, C12: 0.1uF; C_0201_0603Metric; LCSC C668346
C16, C17: 4.7uF; C_0402_1005Metric_small_pads; LCSC C23733
C18, C19: 15pF; C_0201_0603Metric; LCSC C85891
D1: LED_Small; LED_0402_1005Metric; LCSC C25503345
D2, D3: 1N5819WS; D_SOD-323; LCSC C191023
J1, J3: Conn_01x02_Pin; PinHeader_1x02_P2.54mm_Vertical
J2: Conn_02x04_Odd_Even; PinHeader_2x04_P2.54mm_Vertical custom silkscreen
J4: USB_C_Receptacle_USB2.0_16P; USB_C_connector_c2765186; LCSC C2765186
L1: 3.3u; L_pol_2016; LCSC C42411119
R1, R3, R7, R8: 10K; R_0201_0603Metric; LCSC C473048
R2, R5, R6: 1K; R_0201_0603Metric; LCSC C270365
R4: 33R; R_0402_1005Metric; LCSC C25105
R9, R10: 5K1; R_0201_0603Metric; LCSC C270344
U1: RP2350_60QFN; RP2350-QFN-60-1EP_7x7_P0.4mm_EP3.4x3.4mm_ThermalVias; LCSC C41378174
U2: 2332/2364 SOCKET; 2x12 dip pin output 600mil centres no ss
U3: AP2112K-3.3; SOT-23-5; LCSC C51118
U4: USBLC6-2P6; SOT-666; LCSC C15999
Y1: Crystal_GND24; Crystal_SMD_Abracon_ABM8G-4Pin_3.2x2.5mm; LCSC C20625731

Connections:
+1V1: C3.1, C4.1, C5.1, C17.1, L1.1, U1.6 (DVDD), U1.23 (DVDD), U1.39 (DVDD), U1.50 (VREG_FB)
+3V3: C2.1, C6.1, C7.1, C8.1, C9.1, C10.1, C11.1, C12.1, C13.1, C16.1, R1.1, R3.1, R4.2, R5.1, U1.1 (IOVDD), U1.11 (IOVDD), U1.20 (IOVDD), U1.30 (IOVDD), U1.38 (IOVDD), U1.44 (ADC_AVDD), U1.45 (IOVDD), U1.49 (VREG_VIN), U1.53 (USB_OTP_VDD), U1.54 (QSPI_IOVDD), U3.5 (VOUT)
+5V: C1.1, D2.1 (K), D3.1 (K), J1.1, U3.1 (VIN), U3.3 (EN)
A0: U1.35 (GPIO23), U2.8 (A0)
A1: U1.34 (GPIO22), U2.7 (A1)
A2: U1.33 (GPIO21), U2.6 (A2)
A3: U1.32 (GPIO20), U2.5 (A3)
A4: U1.31 (GPIO19), U2.4 (A4)
A5: U1.29 (GPIO18), U2.3 (A5)
A6: U1.28 (GPIO17), U2.2 (A6)
A7: U1.27 (GPIO16), U2.1 (A7)
A8: U1.19 (GPIO15), U2.23 (A8)
A9: U1.18 (GPIO14), U2.22 (A9)
A10: U1.17 (GPIO13), U2.19 (A10)
A11_CE: U1.15 (GPIO11), U2.18 (A11)
A12_CS: U1.16 (GPIO12), U2.21 (A12)
BOOT: J2.5, R2.1
CS1_OE: U1.14 (GPIO10), U2.20 (~CS)
CX1: J3.1, U1.13 (GPIO9)
CX2: J3.2, U1.12 (GPIO8)
D0: U1.10 (GPIO7), U2.9 (D0)
D1: U1.9 (GPIO6), U2.10 (D1)
D2: U1.8 (GPIO5), U2.11 (D2)
D3: U1.2 (GPIO0), U2.13 (D3)
D4: U1.3 (GPIO1), U2.14 (D4)
D5: U1.4 (GPIO2), U2.15 (D5)
D6: U1.5 (GPIO3), U2.16 (D6)
D7: U1.7 (GPIO4), U2.17 (D7)
D+: U1.52 (USB_DP), U4.1 (I/O1)
D-: U1.51 (USB_DM), U4.3 (I/O2)
GND: C1.2, C2.2, C3.2, C4.2, C5.2, C6.2, C7.2, C8.2, C9.2, C10.2, C11.2, C12.2, C13.2, C15.2, C16.2, C17.2, C18.2, C19.2, J1.2, J2.2, J2.4, J4.A1 (GND), J4.A12 (GND), J4.B1 (GND), J4.B12 (GND), J4.S1 (SHIELD), R8.2, R9.1, R10.1, U1.47 (VREG_PGND), U1.61 (GND), U2.12 (GND), U3.2 (GND), U4.2 (GND), Y1.2, Y1.4
LED0: D1.1 (K), U1.43 (GPIO29_ADC3)
unnamed: C19.1, R6.1, Y1.1
unnamed: D1.2 (A), R5.2
unnamed: J4.A5 (CC1), R10.2
unnamed: J4.B5 (CC2), R9.2
unnamed: J4.A6 (D+), J4.B6 (D+), U4.6 (I/O1)
unnamed: J4.A7 (D-), J4.B7 (D-), U4.4 (I/O2)
unnamed: C15.1, R4.1, U1.46 (VREG_AVDD)
unnamed: L1.2, U1.48 (VREG_LX)
unnamed: C18.1, U1.21 (XIN), Y1.3
unnamed: R6.2, U1.22 (XOUT)
QSPI_SCLK: U1.56 (QSPI_SCLK)
QSPI_SD0: U1.57 (QSPI_SD0)
QSPI_SD1: U1.59 (QSPI_SD1)
QSPI_SD2: U1.58 (QSPI_SD2)
QSPI_SD3: U1.55 (QSPI_SD3)
QSPI_SS: R2.2, R3.2, U1.60 (QSPI_SS)
RUN: J2.7, R1.2, U1.26 (RUN)
SEL_A: J2.1, U1.37 (GPIO25)
SEL_B: J2.3, U1.36 (GPIO24)
SEL_C: J2.6, U1.24 (SWCLK), U1.40 (GPIO26_ADC0)
SEL_D: J2.8, U1.25 (SWD), U1.41 (GPIO27_ADC1)
VBUS: D3.2 (A), J4.A4 (VBUS), J4.A9 (VBUS), J4.B4 (VBUS), J4.B9 (VBUS), R7.1, U4.5 (VBUS)
VBUS_DET: R7.2, R8.1, U1.42 (GPIO28_ADC2)
VHOST: D2.2 (A), U2.24 (VCC)

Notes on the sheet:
Run time select jumpers
Voltage Regulation
Power Inputs
USB-C
Extra power cap
2316/2332/2364 ROM Replacemennt
Bypass Caps
Power LED
BOOTSEL
Jumpers and programming

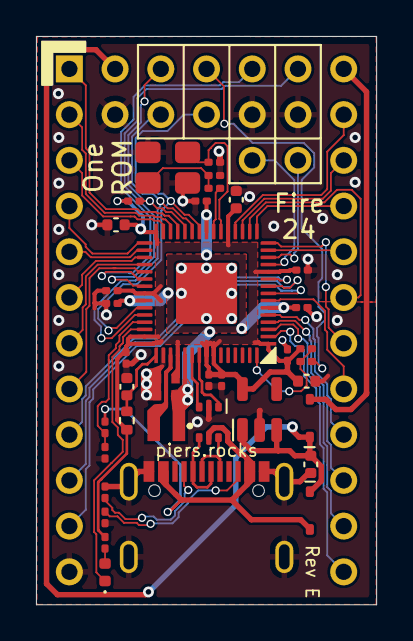
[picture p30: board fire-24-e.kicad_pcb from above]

Board: 2 copper layers, 18.9 x 31.6 mm, 41 parts (0 on the bottom side), 51 nets.

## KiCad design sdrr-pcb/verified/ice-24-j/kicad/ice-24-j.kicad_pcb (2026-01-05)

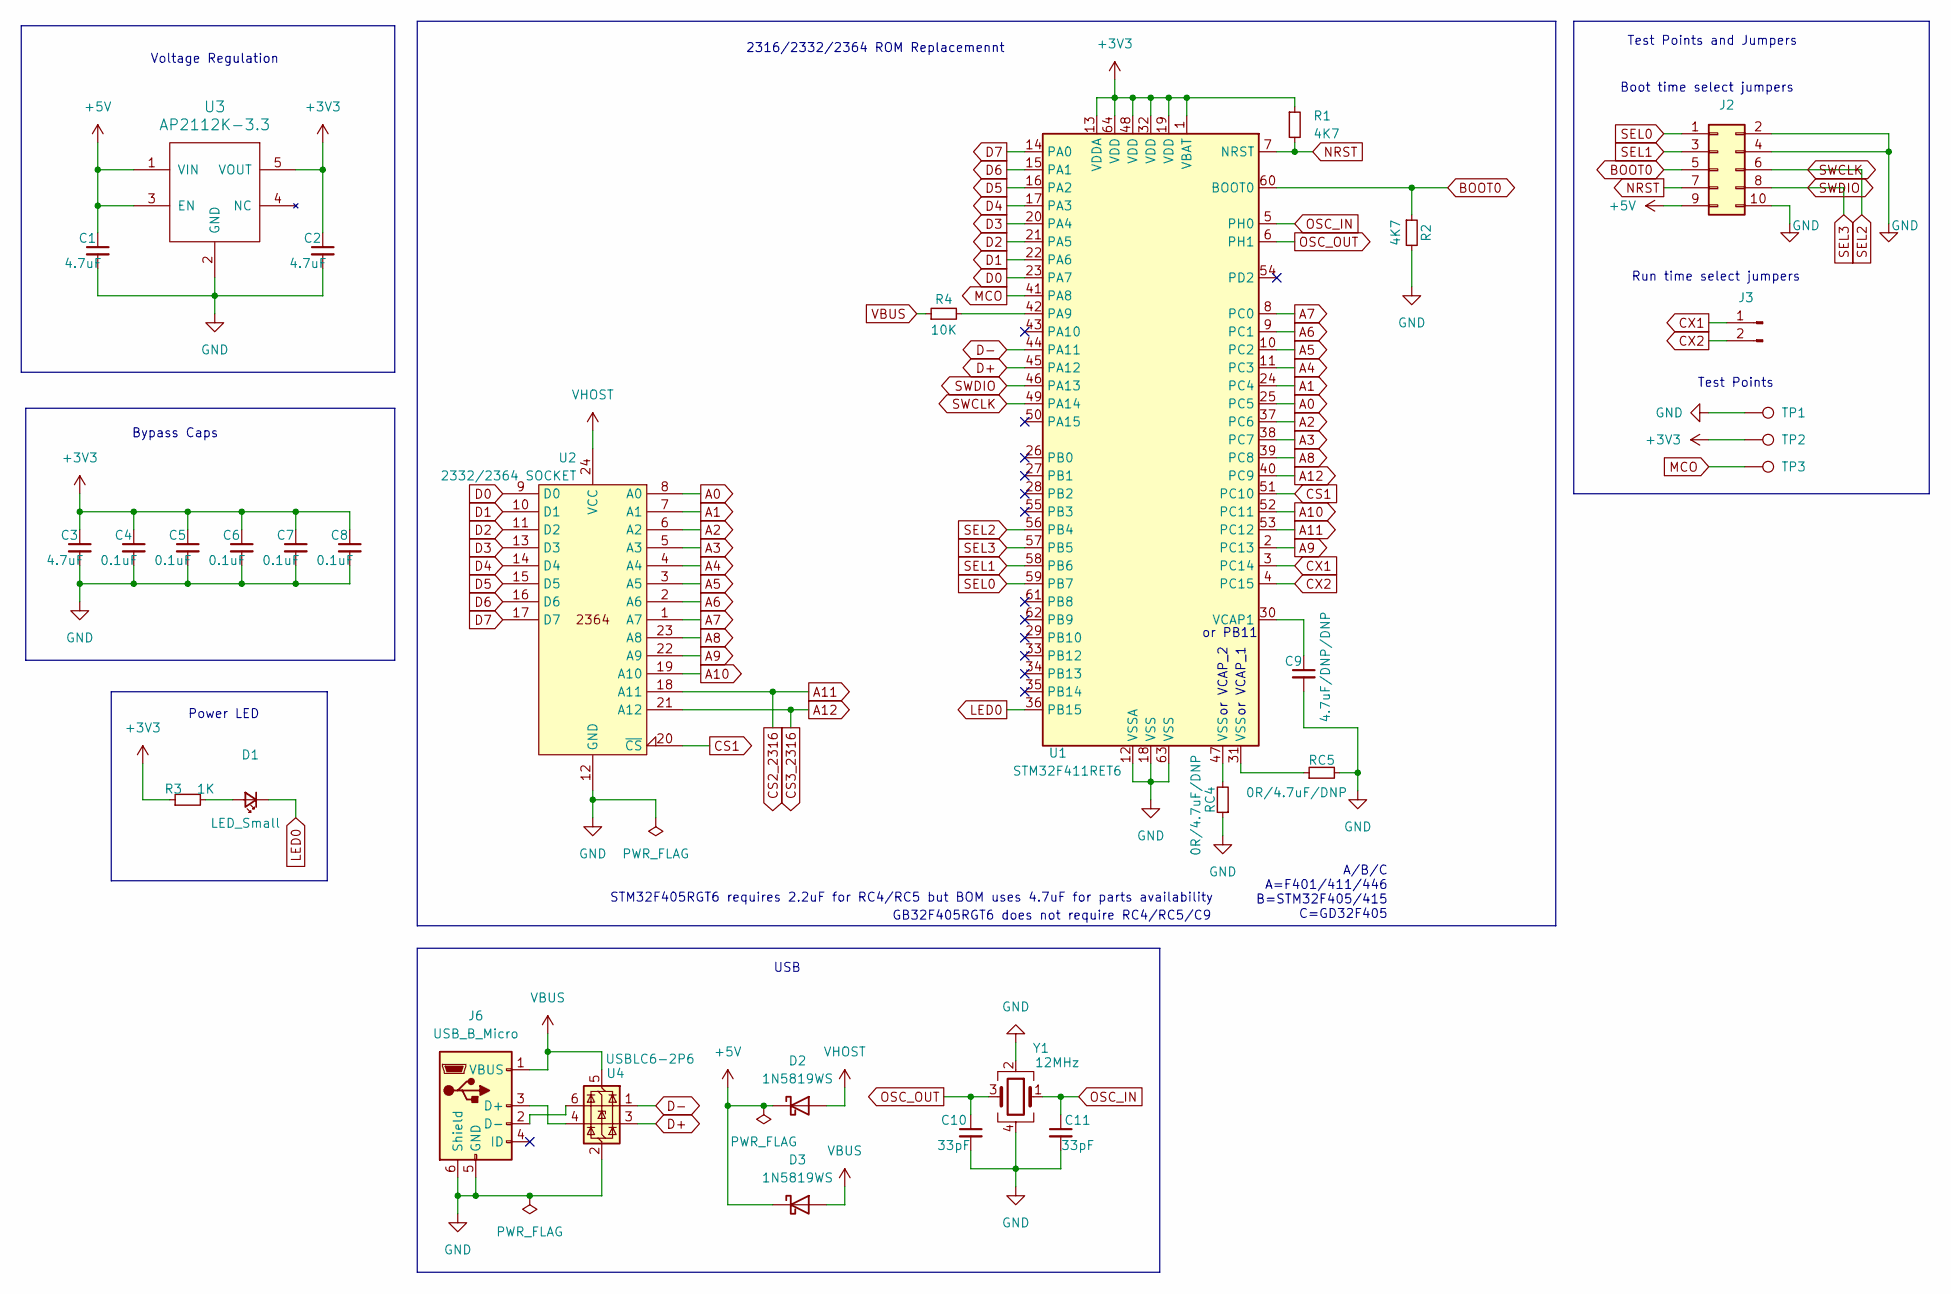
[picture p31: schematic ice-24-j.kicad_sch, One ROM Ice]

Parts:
C1, C2, C3: 4.7uF; C_0402_1005Metric; LCSC C23733
C4, C5, C6, C7, C8: 0.1uF; C_0402_1005Metric; LCSC C1525
C9: 4.7uF/DNP/DNP; C_0402_1005Metric; LCSC C23733
C10, C11: 33pF; C_0402_1005Metric; LCSC C1562
D1: LED_Small; LED_0603_1608Metric; LCSC C2286
D2, D3: 1N5819WS; D_SOD-323; LCSC C191023
J2: Conn_02x05_Odd_Even; PinHeader_2x05_P2.54mm_Vertical custom silkscreen
J3: Conn_01x02_Pin; PinHeader_1x02_P2.54mm_Vertical
J6: USB_B_Micro; USB_Micro-B_micro_xnj_073_C404969; LCSC C404969
R1, R2: 4K7; R_0402_1005Metric; LCSC C25900
R3: 1K; R_0402_1005Metric; LCSC C11702
R4: 10K; R_0402_1005Metric; LCSC C25744
RC4, RC5: 0R/4.7uF/DNP; C_0402_1005Metric; LCSC C17168
TP1, TP2, TP3: TestPoint; 1mm smd test point small ss
U1: STM32F411RET6; LQFP-64_10x10mm_P0.5mm; LCSC C94355
U2: 2332/2364 SOCKET; 2x12 dip pin output 600mil centres no ss
U3: AP2112K-3.3; SOT-23-5; LCSC C51118
U4: USBLC6-2P6; SOT-666; LCSC C15999
Y1: 12MHz; Crystal_SMD_3225-4Pin_3.2x2.5mm; LCSC C9002

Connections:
+3V3: C2.1, C3.1, C4.1, C5.1, C6.1, C7.1, C8.1, R1.1, R3.1, TP2.1, U1.1 (VBAT), U1.13 (VDDA), U1.19 (VDD), U1.32 (VDD), U1.48 (VDD), U1.64 (VDD), U3.5 (VOUT)
+5V: C1.1, D2.1 (K), D3.1 (K), J2.9, U3.1 (VIN), U3.3 (EN)
A0: U1.25 (PC5), U2.8 (A0)
A1: U1.24 (PC4), U2.7 (A1)
A2: U1.37 (PC6), U2.6 (A2)
A3: U1.38 (PC7), U2.5 (A3)
A4: U1.11 (PC3), U2.4 (A4)
A5: U1.10 (PC2), U2.3 (A5)
A6: U1.9 (PC1), U2.2 (A6)
A7: U1.8 (PC0), U2.1 (A7)
A8: U1.39 (PC8), U2.23 (A8)
A9: U1.2 (PC13), U2.22 (A9)
A10: U1.52 (PC11), U2.19 (A10)
A11: U1.53 (PC12), U2.18 (A11)
A12: U1.40 (PC9), U2.21 (A12)
BOOT0: J2.5, R2.1, U1.60 (BOOT0)
CS1: U1.51 (PC10), U2.20 (~CS)
CX1: J3.1, U1.3 (PC14)
CX2: J3.2, U1.4 (PC15)
D0: U1.23 (PA7), U2.9 (D0)
D1: U1.22 (PA6), U2.10 (D1)
D2: U1.21 (PA5), U2.11 (D2)
D3: U1.20 (PA4), U2.13 (D3)
D4: U1.17 (PA3), U2.14 (D4)
D5: U1.16 (PA2), U2.15 (D5)
D6: U1.15 (PA1), U2.16 (D6)
D7: U1.14 (PA0), U2.17 (D7)
D+: U1.45 (PA12), U4.3 (I/O2)
D-: U1.44 (PA11), U4.1 (I/O1)
GND: C1.2, C2.2, C3.2, C4.2, C5.2, C6.2, C7.2, C8.2, C9.2, C10.2, C11.2, J2.2, J2.4, J2.10, J6.5 (GND), J6.6 (Shield), R2.2, RC4.1, RC5.2, TP1.1, U1.12 (VSSA), U1.18 (VSS), U1.63 (VSS), U2.12 (GND), U3.2 (GND), U4.2 (GND), Y1.2, Y1.4
LED0: D1.1 (K), U1.36 (PB15)
MCO: TP3.1, U1.41 (PA8)
NRST: J2.7, R1.2, U1.7 (NRST)
unnamed: D1.2 (A), R3.2
unnamed: J6.3 (D+), U4.4 (I/O2)
unnamed: J6.2 (D-), U4.6 (I/O1)
unnamed: RC4.2, U1.47 (VSS)
unnamed: RC5.1, U1.31 (VSS)
unnamed: R4.2, U1.42 (PA9)
unnamed: C9.1, U1.30 (VCAP1)
OSC_IN: C11.1, U1.5 (PH0), Y1.1
OSC_OUT: C10.1, U1.6 (PH1), Y1.3
SEL0: J2.1, U1.59 (PB7)
SEL1: J2.3, U1.58 (PB6)
SEL2: J2.6, U1.49 (PA14), U1.56 (PB4)
SEL3: J2.8, U1.46 (PA13), U1.57 (PB5)
VBUS: D3.2 (A), J6.1 (VBUS), R4.1, U4.5 (VBUS)
VHOST: D2.2 (A), U2.24 (VCC)

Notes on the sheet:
or VCAP_1
or VCAP_2
Run time select jumpers
USB
Voltage Regulation
2316/2332/2364 ROM Replacemennt
Power LED
or PB11
GB32F405RGT6 does not require RC4/RC5/C9
Test Points
Bypass Caps
Boot time select jumpers
A/B/C A=F401/411/446 B=STM32F405/415 C=GD32F405
Test Points and Jumpers
STM32F405RGT6 requires 2.2uF for RC4/RC5 but BOM uses 4.7uF for parts availability

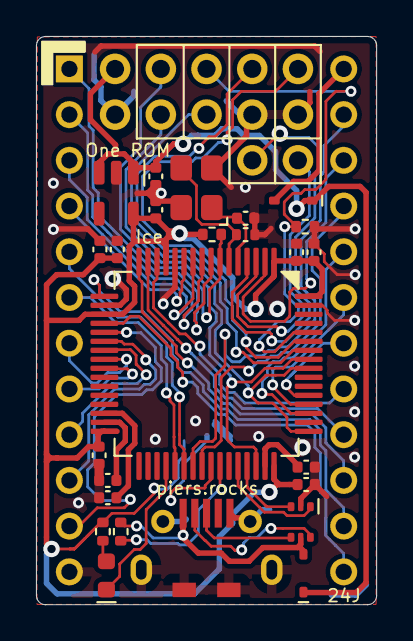
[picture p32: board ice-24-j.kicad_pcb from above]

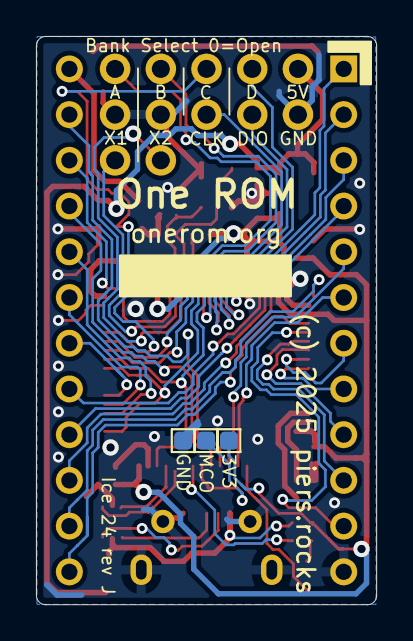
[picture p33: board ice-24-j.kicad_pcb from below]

Board: 2 copper layers, 18.9 x 31.6 mm, 31 parts (3 on the bottom side), 48 nets.

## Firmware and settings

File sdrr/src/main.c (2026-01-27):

// One ROM Main startup code (clock and GPIO initialisation)

// Copyright (C) 2025 Piers Finlayson <piers@piers.rocks>
//
// MIT License

#include "include.h"

#if !defined(RP235X) && !defined(STM32F4)
    #error "Unsupported MCU line - please define RP235X or STM32F4"
#endif // !RP2350 && !STM32F4

const char sdrr_build_date[] = __DATE__ " " __TIME__;

sdrr_runtime_info_t sdrr_runtime_info __attribute__((section(".sdrr_runtime_info"))) = {
    .magic = {'s', 'd', 'r', 'r'},  // Lower case to distinguish from firmware magic
    .runtime_info_size = sizeof(sdrr_runtime_info_t),
    .image_sel = 0xFF,
    .rom_set_index = 0xFF,
    .count_rom_access = 0x00,
    .access_count = 0xFFFFFFFF,
    .rom_table = NULL,
    .rom_table_size = 0,
    .bootloader_entry = 0,
#if defined(OVERCLOCK) && (OVERCLOCK == 1)
    .overclock_enabled = 1,
#else // !OVERCLOCK
    .overclock_enabled = 0,
#endif // OVERCLOCK
    .status_led_enabled = 0,  // updated from sdrr_info in vector.c
    .swd_enabled = 0,  // updated from sdrr_info in vector.c
    .fire_vreg = FIRE_VREG_STOCK,
    .ice_freq = ICE_FREQ_NONE,
    .fire_freq = FIRE_FREQ_NONE,
    .sysclk_mhz = TARGET_FREQ_MHZ,
#if defined(RP_PIO) && (RP_PIO == 1)
    .fire_serve_mode = FIRE_SERVE_PIO,
#else // !RP_PIO
    .fire_serve_mode = FIRE_SERVE_CPU,
#endif // RP_PIO
    .bit_mode = BIT_MODE_8
};

// This function checks the state of the image select pins, and returns an
// integer value, as if the sel pins control bit 0, 1, 2, 3, etc in order of
// that integer.  The first sel pin in the array is bit 0, the second bit 1, 
// etc.
uint32_t check_sel_pins(uint32_t *sel_mask) {
    uint32_t num_sel_pins, sel_value;
    uint64_t orig_sel_mask, gpio_value, sel_flip_bits;

    // Setup the pins first.  Do this first to allow any pull-ups to settle
    // before reading.
    num_sel_pins = setup_sel_pins(&orig_sel_mask, &sel_flip_bits);
    if (num_sel_pins == 0) {
        DEBUG("No image select pins");
        disable_sel_pins();
        *sel_mask = 0;
        return 0;
    }

    // Read the actual GPIO value, masked appropriately
    gpio_value = get_sel_value(orig_sel_mask, sel_flip_bits);

    // SEGGER doesn't cope well with 64-bit values, so split into two 32-bit
    // parts for logging
    DEBUG("Sel GPIO val: 0x%08lX%08lX #: %lu mask 0x%08lX%08lX", 
        (uint32_t)(gpio_value >> 32), (uint32_t)gpio_value,
        (unsigned long)num_sel_pins,
        (uint32_t)(orig_sel_mask >> 32), (uint32_t)orig_sel_mask);

    disable_sel_pins();

    // Now turn the GPIO value into a SEL value, with the bits consecutive
    // starting from bit 0, based on which pin the SEL value is.  At the same
    // time we have to update sel_mask, to match.  This gives us an integer
    // which can be used as an index into the rom set
    *sel_mask = 0;
    sel_value = 0;
    for (int ii = 0; ii < MAX_IMG_SEL_PINS; ii++) {
        uint8_t pin = sdrr_info.pins->sel[ii];
        if (pin < MAX_USED_GPIOS) {
            if (gpio_value & (1ULL << pin)) {
                sel_value |= (1 << ii);
            }
            *sel_mask |= (1ULL << ii);
        }
    }

    DEBUG("Sel value: 0x%08X mask: 0x%08X", sel_value, *sel_mask);

    // Store the value of the pins in sdrr_runtime_info
    sdrr_runtime_info.image_sel = sel_value;

    return sel_value;
}

// Check whether we shoud enter the device's bootloader and, if so, enter it.
// This is indicated via jumping SEL0, SEL1, and SEL2 - PB0-2.  These are all
// pulled up to enter the bootloader.  STM32F4 variant from rev E onwards also
// include PB7 as the most significant bit.
//
// This must be done before we set up the PLL, peripheral clocks, etc, as
// those must be disabled for the bootloader.
//
// As this checks the sel pins, cache and return the result, so we don't need
// to re-check it later.
void check_enter_bootloader(uint32_t sel_pins, uint32_t sel_mask) {
    LOG("Checking whether to enter bootloader");

    if ((sel_mask) && ((sel_pins & sel_mask) == sel_mask)) {
        // SEL pins are all high - enter the bootloader
        LOG("Entering bootloader");

        // Pause to allow the log to be received
        for (volatile int ii = 0; ii < 1000000; ii++);

        enter_bootloader();
    }

    return;
}

// Check the metadata is present
uint8_t metadata_present(const sdrr_info_t *info) {
    onerom_metadata_header_t *metadata = (onerom_metadata_header_t *)info->metadata_header;
    uint8_t present = 1;

    // Check for magic in metadata
    for (int ii = 0; ii < 16; ii++) {
        if (metadata->magic[ii] != "ONEROM_METADATA"[ii]) {
            present = 0;
            break;
        }
    }

    if (present) {
        if (metadata->version == 1) {
            LOG("Metadata v%d", metadata->version);
        } else {
            LOG("!!! Unsupported metadata version: %d", metadata->version);
            present = 0;
        }
    } else {
        LOG("Valid metadata header not found");
    }

    return present;
}

void limp_mode(limp_mode_pattern_t pattern) {
    LOG("Limp mode %d", pattern);

    uint32_t on_time, off_time;

    if (!sdrr_runtime_info.status_led_enabled && sdrr_info.status_led_enabled) {
        DEBUG("Enabled status LED");
        setup_status_led();
    }

    if (pattern >= NUM_LIMP_MODE_PATTERNS) {
        DEBUG("!!! Invalid limp mode pattern");
        pattern = LIMP_MODE_NONE;
    }

    on_time = limp_mode_patterns[pattern].on_time;
    off_time = limp_mode_patterns[pattern].off_time;

    while (1) {
        blink_pattern(on_time, off_time, 1);
    }
}

// Read in firmware overrides from the selected ROM set, if present (0.6.0+)
// and modify sdrr_runtime_info accordingly.
void process_firmware_overrides(
    sdrr_runtime_info_t *runtime_info,
    const sdrr_rom_set_t *set
) {
    if (set->extra_info == 1) {
        const onerom_firmware_overrides_t *overrides = set->firmware_overrides;
        if ((overrides != NULL) && (overrides != (void*)0xFFFFFFFF)) {
#if defined(STM32F4)
            if (overrides->override_present[0] & (1 << 0)) {
                runtime_info->ice_freq = overrides->ice_freq;
                LOG("ICE freq override: %d", runtime_info->ice_freq);
            }
            if (overrides->override_present[0] & (1 << 1)) {
                runtime_info->overclock_enabled = overrides->override_value[0] & (1 << 0) ? 1 : 0;
                LOG("ICE overclock override: %d", runtime_info->overclock_enabled);
            }
#endif
#if defined(RP235X)
            if (overrides->override_present[0] & (1 << 2)) {
                runtime_info->fire_freq = overrides->fire_freq;
                LOG("Fire freq override: %d", runtime_info->fire_freq);
            }
            if (overrides->override_present[0] & (1 << 3)) {
                runtime_info->overclock_enabled = overrides->override_value[0] & (1 << 1) ? 1 : 0;
                LOG("Fire overclock override: %d", runtime_info->overclock_enabled);
            }
            if (overrides->override_present[0] & (1 << 4)) {
                runtime_info->fire_vreg = overrides->fire_vreg;
                LOG("Fire VREG override: %d", runtime_info->fire_vreg);
            }
#endif
            if (overrides->override_present[0] & (1 << 5)) {
                runtime_info->status_led_enabled = overrides->override_value[0] & (1 << 2) ? 1 : 0;
                LOG("Status LED override: %d", runtime_info->status_led_enabled);
            }
            if (overrides->override_present[0] & (1 << 6)) {
                runtime_info->swd_enabled = overrides->override_value[0] & (1 << 3) ? 1 : 0;
                LOG("SWD enabled override: %d", runtime_info->swd_enabled);
            }
#if defined(RP235X)
            if (overrides->override_present[0] & (1 << 7)) {
                runtime_info->fire_serve_mode = overrides->override_value[0] & (1 << 4) ? FIRE_SERVE_PIO : FIRE_SERVE_CPU;
                LOG("Fire serve mode override: %d", runtime_info->fire_serve_mode);
            }
#endif
        }
    }
    else if (set->extra_info == 0) {
        LOG("No extra info in ROM set - no overrides present");
    } else {
        LOG("!!! Unsupported extra_info value in ROM set: %d", set->extra_info);
    }
}

// Needs to do the following:
// - Set up the clock to 68.8Mhz
// - Set up GPIO ports A, B and C to inputs
// - Load the selected ROM image into RAM for faster access
// - Run the main loop, from RAM
//
// Startup needs to be a small number of hundreds of ms, so it's complete and
// the main loop is running before the other hardware is accessing the ROM.
//
// The hardware takes around 200us to power up, then maybe 200us for the PLL to
// lock, in clock_init().  The rest of time we have for our code.
//
// preload_rom_image is likely to take the longest, as it is copying an 8KB
// ROM image to RAM, and having to deal with the internal complexity of
// remapping the data to the bit ordering we need, and to skip bit 3 (and use
// bit 14 instead).
int main(void) {
    // Platform specific initialization
    platform_specific_init();

    // Initialize GPIOs.  Do it now before checking bootloader mode.
    DEBUG("Init GPIO");
    setup_gpio();

    // Enable logging.  Done after GPIO setup, so SWD pins are configured.
    if (sdrr_info.boot_logging_enabled) {
        LOG_INIT();
    }

    // Set up VBUS detect interrupt.  Done next, so we can enter DFU mode as 
    // soon as USB plugged in
    if (sdrr_info.extra->usb_dfu) {
        DEBUG("Init VBUS det");
        setup_vbus_interrupt();
    }

    // Read image select pin values - we need this to check whether to enter
    // bootloader mode if they are all 1.
    uint32_t sel_mask, sel_pins;
    sel_pins = check_sel_pins(&sel_mask);

    // Now check whether to enter bootloader mode
    if (sdrr_info.bootloader_capable) {
        check_enter_bootloader(sel_pins, sel_mask);
    }
    
    // Now get the rom set from the image select pins.  We do this before
    // setting up the clock, in case there's any clock configuration overrides
    // to be applied from the selected ROM set.
    const sdrr_rom_set_t *set = NULL;
    uint8_t md = metadata_present(&sdrr_info);
#if defined(BOOT_LOGGING)
    if (md) {
        log_roms(sdrr_info.metadata_header);
    }
#endif
    if (md && (sdrr_info.metadata_header->rom_set_count > 0)) {
        // Find out if extra_info is set to 1 on the first set.  If it is, the
        // set structures are 0.6.0+ and are the size of sdrr_rom_set_t (64
        // bytes), otherwise they are pre 0.6.0 (probably created by an old
        // Studio/wasm version) and hence 16 bytes.
        uint8_t extra_info = sdrr_info.metadata_header->rom_sets[0].extra_info;
        DEBUG("First ROM set extra_info = %d", extra_info);
        if (extra_info == 1) {
            DEBUG("ROM sets are 0.6.0+ format");
        } else {
            DEBUG("ROM sets are pre-0.6.0 format");
        }
        uint8_t *base = (uint8_t *)sdrr_info.metadata_header->rom_sets;
        size_t stride = (extra_info == 1) ? sizeof(sdrr_rom_set_t) : 16;

        // Figure out what ROM set to use
        sdrr_runtime_info.rom_set_index = get_rom_set_index(sel_pins, sel_mask);

        // Get pointer to the selected ROM set
        set = (const sdrr_rom_set_t *)(base + (stride * sdrr_runtime_info.rom_set_index));

        // Now process any firmware overrides from the selected ROM set.
        // This should be safe because the first thing that does is check that
        // extra_info is 1.
        process_firmware_overrides(&sdrr_runtime_info, set);
    } else if (!md) {
        LOG("No metadata");
    } else {
        LOG("!!! No ROM sets");
    }

    // Check the bit mode
    if (sdrr_info.pins->data2[0] != 0xFF) {
        sdrr_runtime_info.bit_mode = BIT_MODE_16;
        LOG("16-bit mode");
#if defined(STM32F4)
        LOG("!!! 16-bit mode not supported on STM32F4");
        limp_mode(LIMP_MODE_INVALID_BUILD);
#endif // STM32F4
    } else {
        sdrr_runtime_info.bit_mode = BIT_MODE_8;
        LOG("8-bit mode");
    }

    // Initialize clock
    DEBUG("Init clock");
    setup_clock();

#if !defined(TIMER_TEST) && !defined(TOGGLE_PA4)
    if (set != NULL) {
        // Set up the ROM table
        if (sdrr_info.preload_image_to_ram) {
            sdrr_runtime_info.rom_table = preload_rom_image(set);
        } else {
            // If we are not preloading the ROM image, we need to set up the
            // rom_table to point to the flash location of the ROM image.
            sdrr_runtime_info.rom_table = (void *)&(set->data[0]);
        }
        sdrr_runtime_info.rom_table_size = set->size;
    }
#endif // !TIMER_TEST && !TOGGLE_PA4

    // Startup MCO after preloading the ROM - this allows us to test (with a
    // scope), how long the startup takes.
    if (sdrr_info.mco_enabled) {
        DEBUG("Init MCO");
        setup_mco();
    }

    // Setup status LED up now, so we don't need to call the function from the
    // main loop - which might be running from RAM.
    if (sdrr_runtime_info.status_led_enabled) {
        DEBUG("Init LED");
        setup_status_led();
    }

    // If we're in ROM mode, and no ROM set is selected, enter limp mode
    if (set == NULL) {
        // Brief blink pattern to indicate no ROM being served.  Stays off for
        // a fifth of the time as it is on.  Exact timings depend on clock
        // speed.  At 100MHz this is roughly 0.5s on 2.5s off.
        limp_mode(LIMP_MODE_NO_ROMS);
    }

    // Do final checks before entering the main loop
    check_config(&sdrr_info, &sdrr_runtime_info, set);

    // Startup - from a stable 5V supply to here - takes:
    // - ~3ms    F411 100MHz BOOT_LOGGING=1
    // - ~1.5ms  F411 100MHz BOOT_LOGGING=0

// Check for incompatible options
#if defined(EXECUTE_FROM_RAM) && defined(XIP_CACHE_WARM)
#error "EXECUTE_FROM_RAM and XIP_CACHE_WARM cannot be defined at the same time"
#endif

#if !defined(PRELOAD_TO_RAM)
#if defined(EXECUTE_FROM_RAM)
// PRELOAD_TO_RAM is for the ROM image, EXECUTE_FROM_RAM is main_loop()
#error "PRELOAD_TO_RAM must be defined when EXECUTE_FROM_RAM is enabled"
#endif // EXECUT_FROM_RAM
#if defined(XIP_CACHE_WARM)
#error "XIP_CACHE_WARM cannot be defined when EXECUTE_FROM_RAM is enabled"
#endif // XIP_CACHE_WARM
#endif // PRELOAD_TO_RAM

#if !defined(EXECUTE_FROM_RAM) && !defined(XIP_CACHE_WARM)
    // Execute the main_loop
#if !defined(MAIN_LOOP_LOGGING)
    LOG("Start main loop - logging ends");
#endif // !MAIN_LOOP_LOGGING
    //XIP_QMI_M0_TIMING &= ~0x04;
    //XIP_QMI_M0_TIMING |= 0x01;
    main_loop(&sdrr_info, &sdrr_runtime_info, set);
#endif

#if defined(EXECUTE_FROM_RAM) || defined(XIP_CACHE_WARM)
    // We need to set up a copy of some of sdrr_info and linked to data, in
    // order for main_loop() to be able to access it.  If we don't do this,
    // main_loop() will try to access the original sdrr_info, which is in
    // flash, and it will use relative addressing, which won't work when 
    // executing from RAM, or is sub-optimal, if using XIP cache pinning.

    // Set up addresses to copy sdrr_info and related data to

    // These come from the linker
    extern uint8_t _sdrr_info_ram_start[];
    extern uint8_t _sdrr_info_ram_end[];

    // The _addresses_ of the linker variables are the locations we're
    // interested in
    uint8_t *sdrr_info_ram_start = &_sdrr_info_ram_start[0];
    uint8_t *sdrr_info_ram_end = &_sdrr_info_ram_end[0];
    uint32_t ram_size = sdrr_info_ram_end - sdrr_info_ram_start;
    uint32_t required_size = sizeof(sdrr_info_t) + sizeof(sdrr_pins_t) + sizeof(sdrr_rom_set_t);
    DEBUG("RAM start: 0x%08X, end: 0x%08X", (unsigned int)sdrr_info_ram_start, (unsigned int)sdrr_info_ram_end);
    DEBUG("RAM size: 0x%08X bytes, required size: 0x%08X bytes", ram_size, required_size);
    if (required_size > ram_size) {
        LOG("!!! Not enough RAM for sdrr_info and related data");
    }
    // Continue anyway :-|

    // Copy sdrr_info to RAM
    uint8_t *ptr = sdrr_info_ram_start;
    sdrr_info_t *info = (sdrr_info_t *)ptr;
    memcpy(info, &sdrr_info, sizeof(sdrr_info_t));
    DEBUG("Copied sdrr_info to RAM at 0x%08X", (uint32_t)info);
    ptr += sizeof(sdrr_info_t);

    // Copy the pins and update sdrr_info which points to pins
    sdrr_pins_t *pins = (sdrr_pins_t *)ptr;
    memcpy(pins, sdrr_info.pins, sizeof(sdrr_pins_t));
    DEBUG("Copied sdrr_pins to RAM at 0x%08X", (uint32_t)pins);
    info->pins = pins;
    ptr += sizeof(sdrr_pins_t);

    // Copy the rom_set to RAM
    sdrr_rom_set_t *rom_set = (sdrr_rom_set_t *)ptr;
    memcpy(rom_set, set, sizeof(sdrr_rom_set_t));
    DEBUG("Copied sdrr_rom_set to RAM at 0x%08X", (uint32_t)rom_set);
    ptr += sizeof(sdrr_rom_set_t);
#endif // EXECUTE_FROM_RAM || XIP_CACHE_WARM

#if defined(XIP_CACHE_WARM)
    // Start and end of main_loop section in FLASH - these are variables
    // from the linker effectively located at these locations on flash, so we
    // need to use & to get the actual addresses.
    extern uint32_t _main_loop_start;
    //extern uint32_t _main_loop_end;

    // Get as addresses
    uint32_t main_loop_start_addr = (uint32_t)&_main_loop_start;
    uint32_t main_loop_end_addr = (uint32_t)&_main_loop_end;

    // Get offset from start of flash main_loop() is located at, and its
    // length
    uint32_t offset = main_loop_start_addr - FLASH_BASE;
    uint32_t length = main_loop_end_addr - main_loop_start_addr;

    // "Read" the main_loop so it gets loads into the cache 
    volatile uint32_t *code_ptr = (volatile uint32_t *)main_loop_start_addr;
    for (uint32_t ii = 0; ii < length; ii += 4) {
        volatile uint32_t dummy = code_ptr[ii/4];
        (void)dummy;
    }

    DEBUG("Warming 0x%08X bytes from 0x%08X, offset: 0x%08X", length, main_loop_start_addr, offset);

    LOG("Finished warming up main_loop %d bytes in XIP cache", length);
    // Execute the main_loop
#if !defined(MAIN_LOOP_LOGGING)
    LOG("Start main loop - logging ends");
#endif // !MAIN_LOOP_LOGGING
    main_loop(info, rom_set);
#endif // XIP_CACHE_WARM

#if defined(EXECUTE_FROM_RAM)
    // The main loop function was copied to RAM in the ResetHandler
    extern uint32_t _ram_func_start;
    void (*ram_func)(const sdrr_info_t *, const sdrr_rom_set_t *set) = (void(*)(const sdrr_info_t *, const sdrr_rom_set_t *set))((uint32_t)&_ram_func_start | 1);
    LOG("Executing main_loop from RAM at 0x%08X", (uint32_t)ram_func);
#if !defined(MAIN_LOOP_LOGGING)
    LOG("Start main loop - logging ends");
#endif // !MAIN_LOOP_LOGGING
    ram_func(info, rom_set);
#endif // EXECUTE_FROM_RAM

    LOG("!!! Unreachable code reached - main_loop() returned or never executed");

    return 0;
}

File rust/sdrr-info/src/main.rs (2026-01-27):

// Copyright (C) 2025 Piers Finlayson <piers@piers.rocks>
//
// MIT License

//! sdrr-info
//!
//! This tool extracts the core properties, configuration options and ROM
//! image information from an SDRR firmware binary or ELF file.
//!
//! It supports firmware version from v0.2.0 onwards.  v0.1.0 firmware did not
//! contain the relevant magic bytes or properties in a format that could be
//! easily extracted.
//!
//! It works by:
//! - Loading the provided file
//! - Detecting whether it's an ELF file (otherwise it assumes a binary file)
//! - If an ELF file, looks for the .sddr_info and .ro_data sections and builds
//!   a quick and dirty binary file from them.
//! - If it's not an ELF file, checks for the magic bytes at the known
//!   location (start of the sdrr_info structure, expects to be located at
//!   0x200 from the start of the binary).
//! - Then performs common processing on the binary file or "fake" ELF binary,
//!   starting with the sdrr_info struct (which contains the core options) and
//!   following and enumerating the ROM sets and images.

// Max version supported by sdrr-info
pub const SDRR_VERSION_MAJOR: u16 = 0;
pub const SDRR_VERSION_MINOR: u16 = 2;
pub const SDRR_VERSION_PATCH: u16 = 1;

// Modules
mod args;
mod load;
mod utils;

// External crates
use anyhow::Result;
use chrono::{DateTime, Local};
use core::fmt;
use std::fs::metadata;
use std::io::Write;
use std::path::Path;

use args::{Args, Command, parse_args};
use load::load_sdrr_firmware;
use sdrr_fw_parser::{McuLine, SdrrAddress, SdrrCsSet, SdrrInfo, SdrrMcuPort, SdrrServe};
use sdrr_fw_parser::{Parser, readers::MemoryReader};
use utils::add_commas;

// SDRR info structure offset in firmware binary
pub const SDRR_INFO_OFFSET: usize = 0x200;

// STM32F4 flash base address
pub const STM32F4_FLASH_BASE: u32 = 0x08000000;

// Supported file types
#[derive(Debug, Clone, Copy, PartialEq, Eq)]
enum FileType {
    // A .elf file
    Elf,

    // A .bin file
    Orc,
}

impl fmt::Display for FileType {
    fn fmt(&self, f: &mut fmt::Formatter<'_>) -> fmt::Result {
        match self {
            FileType::Elf => write!(f, "ELF (.elf)"),
            FileType::Orc => write!(f, "Binary (.bin)"),
        }
    }
}

struct FirmwareData {
    file_type: FileType,
    file_size: usize,
    reader: MemoryReader,
    info: SdrrInfo,
}

pub fn print_header() {
    println!("One ROM - Firmware Information");
    println!("------------------------------");
}

pub fn main() -> Result<(), Box<dyn std::error::Error>> {
    smol::block_on(async_main())
}

async fn async_main() -> Result<(), Box<dyn std::error::Error>> {
    let args = match parse_args() {
        Ok(args) => args,
        Err(e) => {
            print_header();
            eprintln!("{}", e);
            std::process::exit(1);
        }
    };

    let firmware_path = &args.firmware;
    let mut fw_data = match load_sdrr_firmware(firmware_path).await {
        Ok(info) => info,
        Err(e) => {
            print_header();
            eprintln!("Error loading firmware");
            eprintln!(
                "Did you supply an SDRR v{}.{}.{} or later .elf or .bin file?",
                SDRR_VERSION_MAJOR, SDRR_VERSION_MINOR, SDRR_VERSION_PATCH
            );
            eprintln!("Detailed error: {}", e);
            std::process::exit(1);
        }
    };

    if !fw_data.info.parse_errors.is_empty() {
        eprintln!("Warning: Firmware parsed with errors:");
        for error in &fw_data.info.parse_errors {
            eprintln!("  {}", error);
        }
        eprintln!();
        if args.strict {
            eprintln!("Exiting due to --strict flag");
            std::process::exit(1);
        }
    } else if !args.output_binary.unwrap_or(false) {
        println!("Firmware parsed successfully");
    }

    // Only output a header if output-binary argument not set
    #[allow(clippy::collapsible_if)]
    if let Some(binary) = args.output_binary {
        if !binary {
            print_header();
        }
    }

    match args.command {
        Command::Info => print_sdrr_info(&fw_data, &args),
        Command::LookupRaw => match args.range {
            None => lookup_raw(&mut fw_data, &args).await,
            Some(_) => lookup_raw_range(&mut fw_data, &args).await,
        },
        Command::Lookup => lookup(&mut fw_data, &args).await,
    }

    Ok(())
}

fn print_sdrr_info(fw_data: &FirmwareData, args: &Args) {
    let info = &fw_data.info;

    print_header();
    println!();

    if !info.parse_errors.is_empty() {
        println!("!!! Firmware Parse Errors !!!");
        println!("-----------------------------");
        for error in &info.parse_errors {
            println!("{}", error);
        }
        println!();
    }

    println!("Core Firmware Properties");
    println!("------------------------");
    println!(
        "File name:     {}",
        Path::new(&args.firmware)
            .file_name()
            .map(|n| n.to_string_lossy())
            .unwrap_or_else(|| "".into())
    );
    let modified_str = metadata(&args.firmware)
        .and_then(|data| data.modified())
        .map(|modified| {
            let datetime: DateTime<Local> = modified.into();
            datetime.format("%b %e %Y %H:%M:%S").to_string()
        })
        .unwrap_or_else(|_| "error".to_string());
    println!("File modified: {}", modified_str);
    println!("File type:     {}", fw_data.file_type);
    println!(
        "File size:     {} bytes ({}KB)",
        add_commas(fw_data.file_size as u64),
        fw_data.file_size.div_ceil(1024)
    );
    println!(
        "Version:       {}.{}.{} (build {})",
        info.major_version, info.minor_version, info.patch_version, info.build_number
    );

    println!(
        "Build Date:    {}",
        info.build_date.as_deref().unwrap_or("unknown")
    );

    println!(
        "Git commit:    {}",
        std::str::from_utf8(&info.commit).unwrap_or("<error>")
    );

    println!(
        "Hardware:      {}",
        info.hw_rev.as_deref().unwrap_or("unknown")
    );
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

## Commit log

2025-09-06 Release v0.4.2 (One ROM Lab) (#26)
    * First Lab version
    * uprev release and fix up lab to read
    * add rom database
    * add many more roms
    * rewrite rom detection, to detect any supported ROM type
    * improve logging when no ROM or empty ROM connected
    * improve zero and empty hanlding
    * (re)move magic
    * refactor and improve commenting
    * refactor and improve commenting
    * add firmware info
    * add link to RTT struct to enable Airfrog to access it
    * cargo clippy and fmt
    * get working and improve logging
    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
    [1541.csv, 2040.csv, 4040.csv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]
2025-09-10 Update PI-PICO-PROGRAMMER.md (#27)
2025-09-12 fix entering bootloader and add dfu-flash
    [main.c, reg-stm32f4.h]
2025-09-12 DFU only for STM32F4
2025-09-12 enter bootloader if powered from USB - no interrupt
2025-09-20 add rev H (USB)
    [sdrr-24-pin-rev-h-bom.csv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]
2025-09-30 add third-party, set and bank configs
    [blacklist-config.txt]
2025-10-02 new pcbs
    [one-rom-fire-usb-b-24-pin-bom.csv, rp2350-24-pin-rev-b.kicad_pcb, rp2350-24-pin-rev-b.kicad_sch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]
2025-10-07 fix no roms blink pattern
    [main.c]
2025-10-08 correct RE board capacities
2025-10-13 Release v0.5.1 - 28 pin prototype and major overhaul of metadata and ROM image data code (#35)
    * auto-generate rom type information
    * auto-generate rom type information
    * move over to auto-generated PCB revision code
    * retire sdrr-common
    * get onerom-config working with wasm
    * get firmware ready to serve 23128/27128
    * add roms doc
    * add basic 23128 support
    * add 2704/2708 and ROM docs
    * fix comment
    * better validation
    * change edition
    * add dir
    * allow onerom-config to be published
    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
    [blacklist-config.txt]
2025-10-14 v0.,5.2 - add onerom-fw cli tool (and fix nasty sdrr-fw-parser bug preventing dynamically generated images from being parsed) (#36)
    * improve gen testing
    * improved gen (and config) testing
    * more validation - rom pins and flash space
    * add description
    * initial empty build image script
    * start new rom-config dir
    * add new fw app
    * uprev makefile rev
    * add cross dependency
    * split fw into library and binary
    * update cargos
    [main.rs]
2025-11-12 Release v0.5.4 (#51)
    * move to 0.5.4
    * fix #re
    * note was/site/images updates required
    * uprev studio to 0.1.1 development
    * add extra rom method
    * add blank config (already added to images)
    * add schema and improve existing configs
    * improve ci
    * add support for extracting sections from larger ROM files
    * improve rom config readme
    * fix pincoder roms
    * properly cache the same ZIP file used over and over
    * rejig pincoder roms
    * update changelog
    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
    [fire-24-usb-b-bom.csv, ice-24-h3-bom.csv, rp2350-24-pin-rev-b.kicad_pcb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]
2025-11-18 Release v0.5.5 (#55)
    * first attempt at autonomous mode
    * basically working pio/dma implementation with 2332 C64 char ROM
    * only call piorom() on RP2350
    * faster pio/dma algorithm
    * enable pio/dma
    * have dual CS working, char rom serving at 69MHz, currently set to single CS
    * fully configurable, working, pio implementation
    * optimise DMAs down to <=3 cycles
    * Improve comments
    * flash using firmware file board info
    * remove extra line
    * fix fp support
    * fix stm32f4 build
    * add PIO/CPU alternative
    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
    [piorom.c, reg-rp235x.h, reg-stm32f4.h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]
2025-11-20 update pico instructions
2025-11-26 init DMA ch 1 read_addr to first byte of ROM table
2025-12-02 add fire-28-a
    [fire-28-usb-a-bom.csv, fire-28-usb-a.kicad_pcb, fire-28-usb-a.kicad_sch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]
2025-12-09 Firmware release 0.5.6, Studio 0.1.4 (#61)
    * support local rom files
    * support 2716 and 2732
    * fix cs line handling
    * add 27 series tests
    * remove rom.pio file as it doesn't provide the actual used PIO code
    * add PIO support for 2316/2716/2732
    * update Cargo files after publishing crates
    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
    [main.rs, piorom.c]
2025-12-12 Firmware Release v0.5.8 (#64)
    * increment version number
    * support >= 2716 and 2316 24 and 28 pin ROM types using PIO algorithm
    * support 28 pin roms
    * see error output from tests
    * fix test program - allocate correct size for rom image
    * add ice-24-i
    * add F446RCT6 part
    * fix 23128 cs3 active high
    * improve config checking
    * re-renable UF2 in BOOTSEL
    * fix sdrr-info lookup for 28 pin roms
    * publish new crates for 0.5.8
    * release 0.5.8
    [ice-24-i-bom-f446rc.csv, ice-24-i-bom.csv, stm32f4-24-pin-rev-i.kicad_pcb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]
2025-12-12 fix ci to build 24/28 configs for correct hardware
    [blacklist-config.txt]
2025-12-15 jlc have changed orientation of micro USB connector?
    [ice-24-i-top-pos-f446.csv, ice-24-i-top-pos.csv]
2025-12-31 move fire-28-a to verified
    [fire-28-usb-a-bom.csv, fire-28-usb-a.kicad_pcb, fire-28-usb-a.kicad_sch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]
2025-12-31 move h3 to verified
    [ice-24-h3-bom.csv, stm32f4-24-pin-rev-h3.kicad_pcb, stm32f4-24-pin-rev-h3.kicad_sch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]
2026-01-01 add hw revisions
    [fire-24-c-bom.csv, fire-24-c.kicad_pcb, fire-24-c.kicad_sch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]
2026-01-01 add fire-28-a3
    [fire-28-a2-bom.csv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]
2026-01-01 back out fire-24-c as verified hw design
    [fire-24-c-bom.csv, fire-24-c.kicad_pcb, fire-24-c.kicad_sch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]
2026-01-03 Support fire-24-c, PIO multi-ROM sets and move RAM ROM table to RAM base (0x2000_0000) (#79)
    * tentative fix to both #76 issues
    * fix PIO serving for non contiguous CS lines
    * promote fire-24-c to verified, and make recommended revision
    * get ci working properly on mac
    * correct contiguity writeup
    * correctly store multi-ROM sets for PIO serving mode
    * move ram rom image to RAM base 0x2000_0000 #78
    * add dates for 0.5.10/0.1.7
    * publish crates
    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
    [fire-24-c-bom.csv, fire-24-c.kicad_pcb, fire-24-c.kicad_sch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]
2026-01-05 add fire-24-d unverified
    [fire-24-d-bom.csv, fire-24-d.kicad_pcb, fire-24-d.kicad_sch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]
2026-01-05 add unverified ice-24-j
    [ice-24-j-bom-f411re.csv, ice-24-j-bom-f446rc.csv, ice-24-j.kicad_pcb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]
2026-01-06 add Fire 28 pin version of Lab for 28 pin ROM validation
    [1541.csv, c64.csv]
2026-01-07 get 24 pin ice qa version working
2026-01-10 add fire-40-a, a 40 pin 27c400 16-bit ROM prototype
    [fire-40-a-bom-rp2354-and-flash.csv, fire-40-a.kicad_pcb, fire-40-a.kicad_sch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]
2026-01-11 add 32 and 40 pin rom types
2026-01-14 Add support for runtime and One ROM Studio configurable firmware configuration. (#87)
    See pull request #87 for more details.
    [fire-28-a3-bom.csv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]
2026-01-14 move fire-28-a rev a3 to verified and recommended
    [fire-28-a3-bom.csv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]
2026-01-19 Merge One RAM prototype code into main. (#98)
    * First working and reliable RAM serving implementation - VIC-20 boots
    * refactor PIO code - this is mid-refactor, RAM function tested working
    * refactor PIO assembly helper macros and RAM PIO0:0
    * add DEBUG_BUILD
    * refactor PIO1 (working)
    * Reduce stack space required by pio assembler
    * finish refactoring the RAM serving using PIO assembler
    * use config in RAM serving
    * fix build breakages
    * refactor piorom
    * fix non-debug builds
    * add vic-20 ram tester to stock vic-20 configs
    [dmareg.h, main.c]
2026-01-20 move fire-24-d and ice-24-j to verified
    [fire-24-d-bom.csv, fire-24-d.kicad_pcb, fire-24-d.kicad_sch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]
2026-01-22 add info on panelising boards
2026-01-22 Releases 0.6.1 (#105)
    * fix #90
    * update copyright
    * fix fire-24-d image select jumpers
    * add swd sel jumper support for ice boards
    * new verified hardware
    * partial test refactoring to deal with CS lines - tests still run
    * fix #103
    * update changelogs
    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
    [main.c, reg-rp235x.h]
2026-01-25 add rp2354 variant of fire d boards
    [fire-24-d-bom-rp2354.csv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]
2026-01-25 add 24 rev E
    [fire-24-e-bom.csv, fire-24-e.kicad_pcb, fire-24-e.kicad_sch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]
2026-01-26 add fire-28-a3 kicad files
    [fire-28-a3.kicad_pcb, fire-28-a3.kicad_sch]
2026-01-27 Add release 0.6.2 - first PIO RAM serving algorithm for Fire 24 C/D (#113)
    * create 40 pin config file - tests run
    * make rams configurable using config files
    * get tests running in 0.7.0 branch
    * further ram improvements
    * get preloading data to RAM working
    * Free up 512KB on RP2350 for chip image
    * Free up 512KB on RP2350 for chip image
    * fix MAIN_LOOP_LOGGING
    * fix ROM_IMPL_DEBUG
    * remove execute from RAM tests
    * make clippy happier
    * add fire-24-e
    * Add possible enhancement
    * remove format
    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
2026-01-28 update board recommendations (Fire over Ice)

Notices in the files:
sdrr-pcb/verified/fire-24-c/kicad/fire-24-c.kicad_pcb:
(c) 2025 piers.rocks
